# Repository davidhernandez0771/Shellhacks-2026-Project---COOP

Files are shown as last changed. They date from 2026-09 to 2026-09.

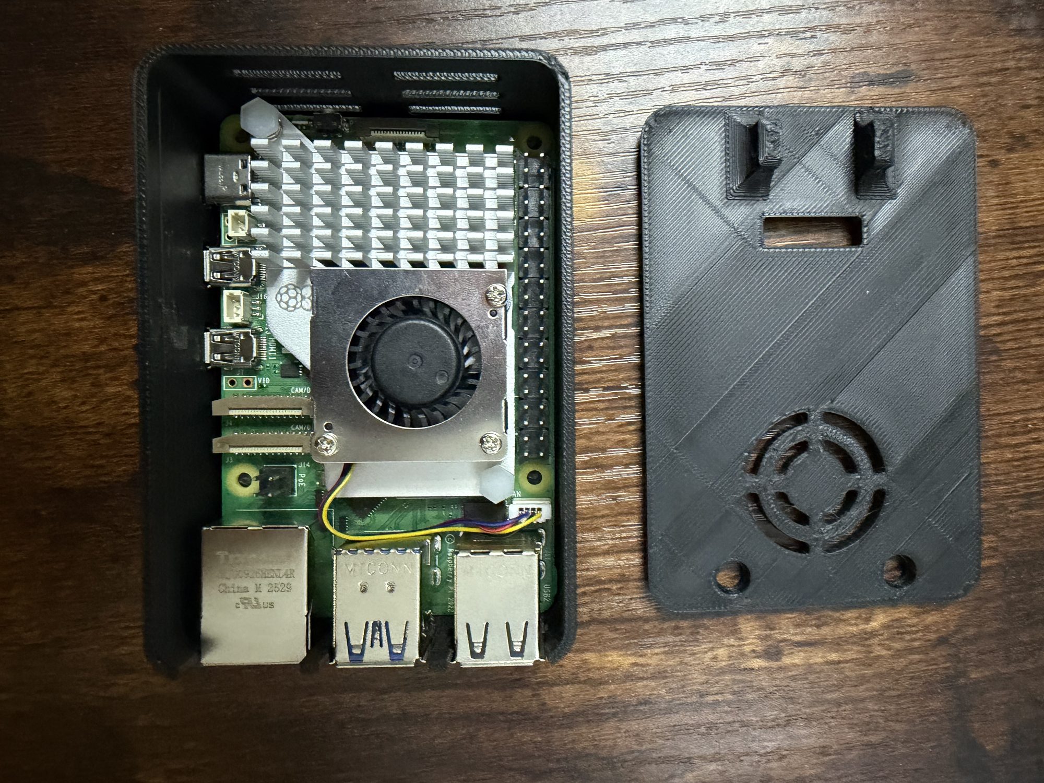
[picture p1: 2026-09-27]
site/media/gallery/05-printed-case-open.jpg

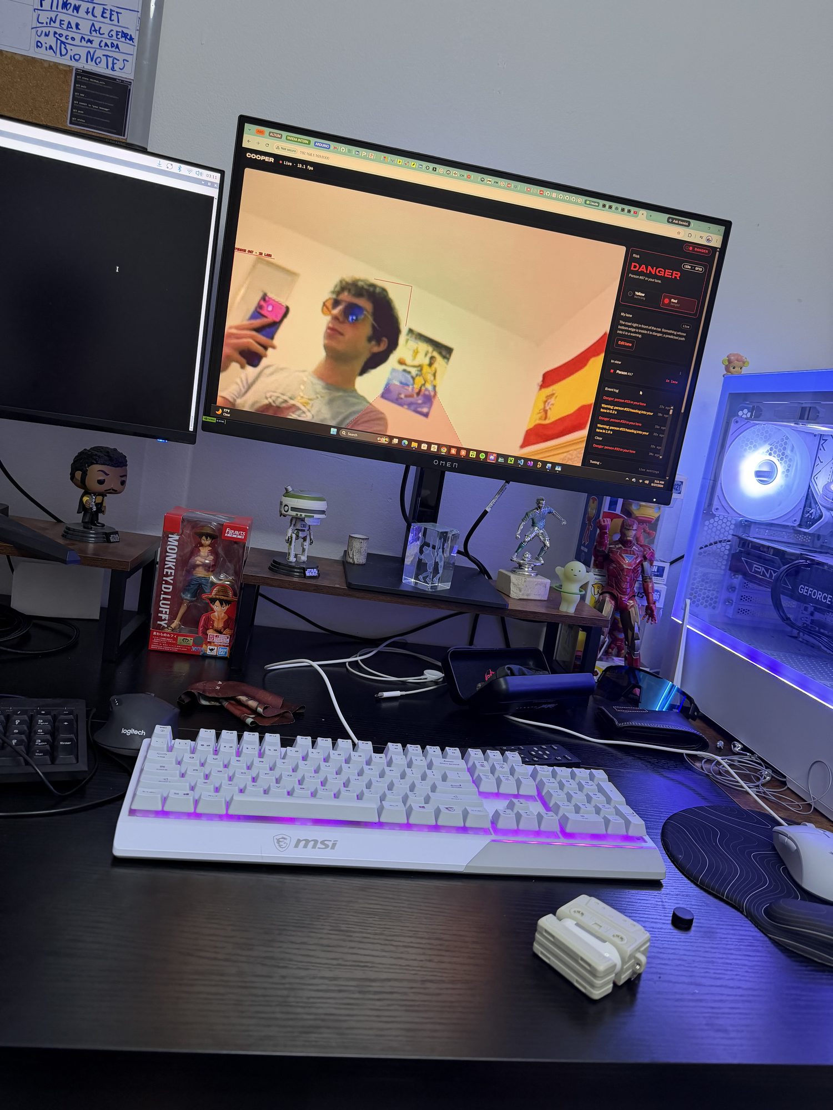
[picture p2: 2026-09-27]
site/media/gallery/12-test-danger-2.jpg

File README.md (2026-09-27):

# COOPER
✏️ _The story behind the name COOPER goes here (the team's to write)._

> COOPER is a Raspberry Pi 5 dashcam that spots people and cars, predicts where each one is heading, and lights a yellow or red LED before something cuts into your lane.

Built for **ShellHacks 2026**. The showcase site is live at [coop.davidhernandez.work](https://coop.davidhernandez.work) and the project page is on [Devpost](https://devpost.com/software/coop-l3s9ho); the Devpost submission text lives in [docs/DEVPOST.md](docs/DEVPOST.md).

```
Pi camera ─► YOLO11n + ByteTrack ─► Kalman filter per object ─► lane risk ─► yellow / red LED
                                                   │
                                                   └──► MJPEG stream + status API ─► web dashboard
```

## Team
| Who | Area |
|---|---|
| David Hernandez | Backend, vision, tracking, prediction |
| Diego Avila | CAD and hardware; assembled and wired the finished project |
| Diego Tabares | Presentation, pitch, and elements of website design |

## What it does
COOPER is a fixed, car-mounted dashcam: a Raspberry Pi 5 and an OV5647 camera behind the windshield, powered by the car. Nothing on it moves. Every frame, it:

1. **Detects** people, cars, motorcycles, buses and trucks with YOLO11n, and gives each one a stable ID with ByteTrack. All on the Pi 5's CPU, no accelerator.
2. **Predicts** where each object is going with its own Kalman filter, 1.5 s ahead.
3. **Judges the risk** against "my lane", a trapezoid of the road in front of the car:
   - **Red LED (danger):** something is in your lane right now.
   - **Yellow LED (warning):** something's predicted path enters your lane within 1.5 s (a car about to cut in, a pedestrian stepping out), or its time to contact is short (it's closing on you fast).
   - **Both off:** clear. Red overrides yellow.
4. **Streams** the video to a web dashboard that draws every predicted path, the lane (which you can drag to fit your car), the risk level and the LED state, and can beep in step with the LEDs.

## How it works (the math)
The car moves, so COOPER works on motion **relative to the camera**, in image pixels: that's what decides a collision, and it needs no map or speed sensor. [docs/MATH.md](docs/MATH.md) has the full derivation; the short version:

- **Where an object touches the road** is the bottom-centre of its box, (u, v). **How close it is** shows in the box height h, which is proportional to 1/distance.
- **A constant-velocity Kalman filter per object** tracks x = [u, v, h, u̇, v̇, ḣ] from measurements z = [u, v, h]:
  - F = [[I, Δt·I], [0, I]], H = [I 0].
  - Q is white-noise acceleration per axis, σ²·[[Δt⁴/4, Δt³/2], [Δt³/2, Δt²]], with σ = 400 px/s² for u, v and 150 px/s² for h.
  - R = diag(3², 3², 3²) px².
  - Predict: x̂⁻ = F·x̂, P⁻ = F·P·Fᵀ + Q. Update: K = P⁻Hᵀ(HP⁻Hᵀ + R)⁻¹, x̂ = x̂⁻ + K(z − Hx̂⁻), P = (I − KH)P⁻.
  - Because every matrix is block-diagonal per axis, it runs as three exact 2-state filters: a fraction of a millisecond for 10 objects.
- **Track lifetime:** a track unseen for 0.5 s is forgotten, and a track needs 3 measurements before its velocity is trusted for warnings.
- **Occlusion:** a box cut short by a nearer car would put the "ground point" on that car's roof. Measurements more than 4σ from the prediction are rejected and the filter coasts (v and h together, since they share the bottom edge), for at most 1 s.
- **Red:** at least 20 % of the object's bottom edge is inside the lane now.
- **Yellow:**
  - Path: the filter's path is sampled every 0.1 s out to 1.5 s, and a predicted bottom edge passes the same lane test.
  - Time to contact: τ = h / ḣ is below 2.0 s (it releases above 2.5 s) while the object is in the lane's corridor (the lane extended towards the vanishing point, widened by 25 % each side). That counts only when ḣ is more than 2 of its own standard deviations above zero, so detector jitter isn't read as closing, and only for boxes at least 24 px tall.
- **No flicker:** a level lights after 2 frames in a row and stays on 0.5 s after its condition ends.

## Hardware
- Raspberry Pi 5 (8 GB) with the active cooler
- OV5647 5 MP camera, 3.6 mm lens, 75° diagonal FOV (≈63°×49° at 4:3), no IR, on the Pi 5 camera port (needs the **15→22 pin Pi 5 cable**)
- A yellow and a red LED, each with a 330 Ω resistor, on Pi GPIO
- Power from the car: a USB-C PD car charger rated for the Pi 5 (5 V, 5 A / 27 W)
- microSD card (32 GB+) with Raspberry Pi OS Bookworm, 64-bit
- A windshield mount and enclosure for the Pi, camera and LEDs (designed in Fusion 360)

✏️ _Total parts cost: to fill in._

Wiring, pinout and the full BOM: [hardware/README.md](hardware/README.md).

### Wiring
| LED | GPIO (BCM) | Physical pin | Through | To |
|---|---|---|---|---|
| Yellow (warning) | GPIO17 ✏️ | 11 | 330 Ω → LED anode (long leg) | cathode → GND (pin 9) |
| Red (danger) | GPIO27 ✏️ | 13 | 330 Ω → LED anode (long leg) | cathode → GND (pin 14) |

✏️ **These pins are placeholders, still to confirm** against the real wiring. Set them as `yellow_pin` / `red_pin` under `[leds]` in `cooper.toml` (BCM numbers, not physical pin numbers). At 3.3 V with a ~2.0 V LED drop, 330 Ω gives about 4 mA per LED. gpiozero drives them through the lgpio backend (the Pi 5's GPIO is on the RP1 chip).

## Run it

### On a laptop (no Pi, no LEDs)
```bash
python -m venv .venv
.venv\Scripts\activate          # Windows  (source .venv/bin/activate on Mac/Linux)
pip install -r requirements.txt
python -m cooper.main --source webcam
```
Open `http://localhost:8000`. Off a Pi the LEDs are mocked automatically (`--no-leds` forces it anywhere): the dashboard shows what they would do, and gpiozero isn't needed. The first run downloads `yolo11n.pt`.

**No camera pointed at a road?** Run the rehearsal: the real app watching a synthetic road through a fixed dashcam (a car cutting in, a pedestrian crossing, the lead car braking, a car in the next lane that must never light anything).
```bash
python -m tools.rehearsal             # then open http://localhost:8000
python -m tools.rehearsal --timeline  # no dashboard: print one 20 s loop's risk and LED changes
```

### On the Pi
Flash Raspberry Pi OS Bookworm (64-bit) and, in Raspberry Pi Imager's settings, set the hostname, a user and **enable SSH**. Then, on the Pi:
```bash
git clone https://github.com/davidhernandez0771/Shellhacks-2026-Project---COOPER cooper
cd cooper
bash scripts/setup_pi.sh          # apt: picamera2, gpiozero, lgpio; a .venv that can see them; pip requirements
source .venv/bin/activate
python -m cooper.main --source picamera   # add --no-leds to keep the LEDs off
```
`setup_pi.sh` creates the venv with `--system-site-packages`, because Picamera2 and gpiozero come from apt, not pip. Test the camera alone with `rpicam-hello -t 5000`.

**Getting onto the Pi:**
- **SSH** from a laptop on the same network: `ssh <user>@<pi-hostname>.local`, or `ssh <user>@<Pi IP>`. `hostname -I` on the Pi prints its IP.
- **Raspberry Pi Connect** when you're not on the same network, or want the Pi's screen in a browser: `sudo apt install rpi-connect` (`rpi-connect-lite` on OS Lite), `rpi-connect on`, `rpi-connect signin`, then open [connect.raspberrypi.com](https://connect.raspberrypi.com) for a remote shell.

**Open the dashboard** from a laptop or phone on the same network: `http://<Pi IP>:8000` (or `http://<pi-hostname>.local:8000`).

- **Run on boot:** `sudo bash scripts/install_service.sh` installs `cooper.service` (systemd), which starts COOPER when the car powers the Pi and restarts it if it crashes. Check on it with `systemctl status cooper` and `journalctl -u cooper -f`; restart with `sudo systemctl restart cooper`.
- **Remote access:** to reach the dashboard over HTTPS from anywhere, with an email login in front (Cloudflare Tunnel + Access), see [scripts/setup_tunnel.md](scripts/setup_tunnel.md).
- **Calibrate the lane** once the camera is mounted: in the dashboard, **Edit lane**, drag the corners onto your lane out to about 15 m, then **Apply and save**. Step by step: [docs/HARDWARE_TEST.md](docs/HARDWARE_TEST.md).

## The dashboard
Served by the Pi at port 8000 (`web/`, plain HTML, CSS and JS; the API is in [docs/API.md](docs/API.md)).

- **Live feed** with, on one canvas: the lane (tinted yellow or red with the risk), every object's corner brackets, its predicted path with a tick every 0.5 s, and the bottom edge the lane test uses.
- **Risk panel:** the level and the reason ("car #201 heading into your lane in 0.8 s"), the two LEDs and whether they're real (GPIO) or mocked, every object by risk, and the event log.
- **Lane editor:** drag the four corners; **Apply** updates the risk rules on the next frame, **Apply and save** also writes it to `cooper.toml`.
- **Tuning:** confidence, horizon, time-to-contact thresholds and hold time, live.
- **Beep:** a sound that follows the same risk level as the LEDs, like a parking sensor: yellow is one short beep a second, red is rapid high beeps. It's off until you turn it on (the speaker button or the **S** key), because browsers block audio until the page is interacted with; the choice is remembered.
- **Diagnostics:** CPU temperature, throttling, vision and camera fps, inference time, camera-to-LED latency.
- **Keys:** **L** edit lane, **Esc** cancel, **F** fullscreen, **S** sound.

With no backend it plays a mock of the same road (`?demo=warning`, `?demo=danger`, …, listed in `web/mock.js`).

## Settings
Every tunable lives in `cooper/config.py`. To change one without editing code, copy `cooper.example.toml` to `cooper.toml` in the repo root and edit it (it's gitignored, so the Pi and each laptop keep their own). Unknown keys and wrong types stop COOPER at startup with the key named. `--config other.toml` picks another file.

Live from the dashboard (`GET/POST /api/settings`, saved back to `cooper.toml` with `"save": true`, comments kept): `conf`, `horizon_s`, `ttc_warn_s`, `ttc_clear_s`, `hold_s`. The lane is live too (`POST /api/lane`). See [docs/API.md](docs/API.md).

Command-line flags for `python -m cooper.main`: `--source auto|picamera|webcam`, `--port`, `--no-leds`, `--annotate` (burn boxes into `/video`), `--config`.

## Bench tools
Run from the repo root. Each also works as `python tools/<name>.py`.

| Tool | What it's for |
|---|---|
| `python -m tools.rehearsal` | The whole app on a synthetic road, no hardware. `--timeline` prints one loop's risk and LED changes instead. |
| `python -m tools.camera_check [--source picamera]` | Delivered resolution and FPS, plus a saved still for the colour and orientation check. |
| `python -m tools.bench_fps [--export]` | YOLO speed, PyTorch vs NCNN at imgsz 256/320/416, timing the same `track()` call COOPER makes; `--export` builds the NCNN models. Prints a Markdown table. |

The first-hardware checklist in [docs/HARDWARE_TEST.md](docs/HARDWARE_TEST.md) uses them in order: rehearsal → camera check → FPS bench → LEDs → lane calibration → risk test.

## Testing
```bash
pip install -r requirements-dev.txt
python -m pytest -q
```
Covers the Kalman filter (against the full 6×6 matrix form, occlusion gating, time to contact), every risk rule and the hysteresis, the LEDs (gpio vs mock, only writing on a change), the settings file and live settings, the lane API, the Flask API, diagnostics, the capture thread, the bench tools, and the rehearsal's whole 20 s loop (each scripted event warns before it's danger, the car in the next lane never lights an LED, no LED flickers). Runs anywhere `requirements.txt` does: no Pi, camera or GPIO needed. GitHub Actions runs it on every push and pull request.

## Performance tips (Pi 5)
- Export the model to NCNN for a big CPU speed-up: `python -m tools.bench_fps --export` (then `python -m tools.bench_fps` to compare), and set `model = "yolo11n_imgsz320_ncnn_model"` and `imgsz = 320` under `[detector]` in `cooper.toml`. An NCNN model must run at the size it was exported at.
- `/api/status` → `diag` shows `fps`, `capture_fps`, `infer_ms`, `latency_ms`, the CPU temperature and throttle flags.
- Keep `imgsz` at 320 and the capture resolution at 640×480 unless you have headroom. Prediction and risk cost well under a millisecond per frame.

## Troubleshooting
- **Camera not detected:** check the ribbon cable orientation and that it's the 22-pin Pi 5 cable. Test with `rpicam-hello`.
- **`numpy.dtype size changed` when importing picamera2:** pip replaced the system numpy. Run `pip uninstall numpy` inside the venv so it uses the apt version again.
- **LEDs say "mock" on the Pi:** the log line `LEDs: mock (...)` gives the reason. Usually gpiozero or lgpio isn't installed (re-run `scripts/setup_pi.sh`), or another process holds the pins.
- **Under-voltage (`throttled` not 0):** the car charger can't deliver 5 A. Use a 27 W USB-C PD charger.
- **No sound from the dashboard:** click the page once (or press **S**); the button reads "Click to enable" while the browser is still blocking audio.

## The website
[coop.davidhernandez.work](https://coop.davidhernandez.work) is the public showcase: a one-page, scroll-driven story (See, Detect, Predict, Warn, Build, Gallery, Team) in one persistent three.js scene, with COOPER's real CAD model pulled apart in the Build chapter. It lives in `site/`, has no build step and deploys to Cloudflare Pages; see [site/README.md](site/README.md) and [site/PERFORMANCE.md](site/PERFORMANCE.md).

## Repo layout
```
cooper/
  main.py       main loop: capture → detect/track → predict → risk → LEDs → stream
  config.py     every tunable value (camera, model, prediction, risk, lane, LED pins)
  camera.py     Picamera2 on the Pi, webcam fallback for laptop dev
  detector.py   YOLO11n + ByteTrack (person, car, motorcycle, bus, truck)
  predictor.py  constant-velocity Kalman filter per tracked object, in image space
  risk.py       lane geometry, path and time-to-contact rules, hysteresis → clear/warning/danger
  leds.py       the two LEDs: gpiozero on the Pi, a mock everywhere else
  control.py    the event log behind /api/events
  settings.py   cooper.toml loading/validation/saving, live tuning (/api/settings) and the lane (/api/lane)
  diag.py       CPU temperature, throttling, LED mode, fps for /api/status.diag
  stream.py     Flask MJPEG stream + the JSON API (docs/API.md)
cooper.example.toml  every setting at its default; copy to cooper.toml (gitignored) to override
web/            the dashboard (served by the Pi)
tools/          rehearsal, camera_check, bench_fps; cad_to_glb.py (Fusion 360 → the site's .glb); site_perf/ (site measurements)
scripts/        setup_pi.sh, install_service.sh + cooper.service, Cloudflare Tunnel (setup_tunnel.md, install_tunnel.sh)
hardware/       wiring, pinout, BOM, power and mounting notes
site/           the public showcase site (static; see site/README.md)
tests/          pytest suite
docs/           MATH.md (filter and risk rules), API.md, HARDWARE_TEST.md, DEVPOST.md, DESIGN_BRIEF.md
```

## License
MIT

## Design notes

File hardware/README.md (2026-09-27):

# Hardware

Owner: design & hardware teammate. Keep this file up to date when the wiring changes. Pin numbers live in `cooper/config.py` (`LedConfig`) and can be overridden under `[leds]` in `cooper.toml`.

## Architecture
```
car 12 V socket ──► USB-C PD car charger (5 V, 5 A) ──USB-C──► Raspberry Pi 5 ──22-pin ribbon──► OV5647 camera
                                                                   │
                                                                   ├─ GPIO17 ──330 Ω──► yellow LED ──► GND
                                                                   └─ GPIO27 ──330 Ω──► red LED ────► GND
```
COOPER is a fixed dashcam: nothing moves. The Pi runs everything (vision, prediction, risk) and drives the two LEDs directly from its GPIO.

## Bill of materials
| Part | Qty | Notes |
|---|---|---|
| Raspberry Pi 5, 8 GB | 1 | + active cooler (a parked car gets hot) |
| OV5647 5 MP camera, 3.6 mm, 75° | 1 | Non-IR |
| Pi 5 camera cable, 15→22 pin | 1 | ✅ have it |
| USB-C PD car charger, 27 W (5 V / 5 A) | 1 | + a short USB-C cable. A weaker charger causes under-voltage throttling |
| LED, yellow, 5 mm | 1 | Warning |
| LED, red, 5 mm | 1 | Danger |
| Resistor, 330 Ω | 2 | One per LED |
| Female-to-male jumper wires | 4 | Or solder to the header |
| microSD card, 32 GB+ | 1 | Raspberry Pi OS Bookworm, 64-bit |
| Windshield mount / enclosure | 1 | Designed by the hardware lead |

## Wiring: LEDs
**The pin numbers are placeholders (TODO): confirm them when wiring, then set them in `cooper.toml`.**

| LED | GPIO (BCM) | Physical pin | Series resistor | Cathode (short leg) to |
|---|---|---|---|---|
| Yellow (warning) | **GPIO17** (TODO) | 11 | 330 Ω, between the pin and the anode (long leg) | GND, physical pin 9 |
| Red (danger) | **GPIO27** (TODO) | 13 | 330 Ω, between the pin and the anode (long leg) | GND, physical pin 14 |

```toml
[leds]
yellow_pin = 17   # BCM numbering, not physical pin numbers
red_pin = 27
```

- **Why 330 Ω:** Pi GPIO is 3.3 V and a yellow or red LED drops about 2.0 V, so (3.3 − 2.0) / 330 ≈ 4 mA: clearly visible, and well under the Pi's per-pin limit (16 mA). Brighter LEDs for daylight can go down to 150 Ω (≈ 9 mA). Never connect an LED without a resistor.
- **BCM vs physical numbers:** gpiozero uses BCM numbers (GPIO17), not header positions (pin 11). `pinout` on the Pi prints the map.
- Only one LED is lit at a time: yellow = warning, red = danger, both off = clear.
- The software drives them through gpiozero with the lgpio backend (the Pi 5's GPIO is on the RP1 chip, which the old RPi.GPIO library doesn't support); `scripts/setup_pi.sh` installs both from apt.

## Power
- **Use a USB-C PD car charger rated for 5 V / 5 A (27 W).** A Pi 5 running YOLO draws a lot of current; a weak charger causes under-voltage throttling or reboots. Check with `vcgencmd get_throttled` (`0x0` = OK) or the dashboard's Power reading.
- On a charger that can't negotiate 5 A the Pi limits its USB ports to 600 mA and shows a boot warning. COOPER uses no USB devices, so that's harmless.
- **The car cuts power when the ignition turns off,** which is an unclean shutdown for the SD card. For the hackathon that's acceptable; a clean shutdown on ignition-off is on the "what's next" list.
- Cabin heat: a car in the sun passes 60 °C inside. Keep the active cooler, and watch `cpu_temp_c` (the Pi 5 throttles at 80–85 °C).

## Mounting and the lane
- Mount the camera **centred** behind the windshield (next to the rear-view mirror), **level**, looking straight down the road, and rigid: a mount that shakes makes every box jitter.
- The software's "my lane" is a region of the image, so it's only right for one mount position. After mounting, calibrate it from the dashboard (**Edit lane** → drag the corners onto your lane out to ~15 m → **Apply and save**); it's stored under `[risk] lane` in `cooper.toml`. `docs/HARDWARE_TEST.md` has the steps.
- Keep the LEDs where the driver sees them without looking away from the road (top of the dashboard, near the windshield base).

## Files
Put CAD, STL and wiring diagrams in this folder.

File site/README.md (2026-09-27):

# COOPER showcase site

A cinematic one-page site for COOPER, a fixed, car-mounted Raspberry Pi 5 dashcam that predicts every road user's path and lights a yellow or red LED before something enters your lane. The COOPER wordmark hero and seven chapters (See, Detect, Predict, Warn, Build, Gallery, Team) played out in one persistent WebGL scene that scroll drives. Design rationale: `docs/DESIGN_DIRECTIONS.md`.

**No build step.** Plain HTML, CSS and native ES modules. three.js and anime.js are vendored in `vendor/` and mapped with an import map in `index.html`, and the fonts are self-hosted in `fonts/`, so the page makes no third-party requests and deploys as-is.

## Preview locally
```bash
python -m http.server 8765 --directory site
```
Open http://localhost:8765. Useful switches:

| URL | What you get |
|---|---|
| `/?still` | the reduced-motion version (same as the OS "reduce motion" setting) |
| `/?nogl` | the no-WebGL fallback (a 2D-canvas render of the same scene) |
| `/?debug` | exposes `window.__coop` (the stage and anime.js) in the console |
| `/#build` | deep link to a chapter (skips the intro animation) |

## Edit the copy
All text is in `index.html`, one `<section class="chapter">` per chapter. Paragraphs with `class="reveal-words"` get the word-by-word reveal automatically; keep them plain text (no links inside). The intro tagline under the wordmark is `TAGLINE` in `js/intro.js`. The chapter names in the bottom HUD come from `CHAPTERS` in `js/stage/director.js`, and the on-canvas tags (`TRACKED`, `PATH · t + …`) from `js/stage/overlay.js`.

The Warn chapter keeps the section id `move` (the nav, the scroll code and the scene key off chapter numbers and ids), so don't rename the id.

## Fill the placeholders
Search for `✏️ PLACEHOLDER` (HTML comments) and `data-placeholder` (elements):

| Placeholder | Where | What to put |
|---|---|---|
| `cost-comparison` | Problem block | COOPER's total parts cost vs. a newer car vs. an aftermarket system |
| gallery `<li>` items | Gallery chapter | photos and videos, see below |

## Add photos and videos to the gallery
The 3D carousel is built from the list in `index.html` (`<ul id="gallery-list">`). Without WebGL the same list shows as a grid, so it's also the accessible version. Put files in `site/media/` and replace a placeholder `<li>`:

```html
<li data-src="media/build.jpg" data-alt="Inside COOPER: the Pi 5, camera and LEDs">Inside the build</li>
<li data-src="media/cut-in.mp4" data-kind="video" data-alt="COOPER lighting yellow as a car cuts in">A cut-in, caught early</li>
```
- The text inside the `<li>` is the caption; `data-alt` is the description for screen readers.
- Any number of items works (the ring spaces them evenly). 6–10 looks best.
- Images: JPG/WebP, 3:2, about 1600×1067, under 400 KB each. They're cover-cropped to 3:2.
- Videos: MP4 (H.264), muted, 3:2 or 16:9, under 4 MB, a few seconds long. They loop silently and only play while facing the viewer.
- A video card can open a longer cut with sound in the viewer: `data-src` is the short silent loop, `data-full` the full video (fetched only when the viewer opens it), `data-poster` the still shown until either plays. Cloudflare Pages rejects files over 25 MB. Card 1 (`media/gallery/demo*.{mp4,jpg}`) is the example.
- Media only downloads when the visitor scrolls near the gallery. The no-WebGL grid picks up the same `data-src` files automatically.

## The 3D model (.glb)
The Warn, Build and Team chapters show COOPER itself: `models/cooper-camera.glb`, made from the team's Fusion 360 assembly by `tools/cad_to_glb.py` (Blender, headless). It has one node per part: `Pi_Case`, `Pi_Case_Lid`, `RASPBERRY_PI_5_1`, `Camera_Mount`, `Camera_Module`, `LED5mm_Yellow` and `LED5mm_Red` (an instance of the yellow one's mesh). It's in metres, with the lens facing −Z, +Y up and the origin at the centre of the case's bottom face. It has about 24k triangles and weighs 281 KB, with positions only (no normals, textures or Draco).

To rebuild it after a CAD change, export the assembly from Fusion as **FBX** (it keeps the component names; the OBJ export loses them) and run from the repo root:

```
blender -b -P tools/cad_to_glb.py -- --src "path/to/Assembled Pi Case.fbx"
blender -b -P tools/cad_to_glb.py -- --src "…fbx" --preview preview.png   # check the part grouping first
```

The CAD files stay out of the repo. The script prints each part's triangle count; the budgets are at the top of it. On the site:
- `js/stage/solids.js` loads the model lazily, once the scroll nears the Warn chapter. Until then, or if it fails, a stand-in built from boxes (same parts, same places) is shown. `CAMERA_MODEL_URL = null` forces the stand-in.
- The model is restyled to match the scene (ink fill, paper edges; the scene has no lights). The exploded view is the `EXPLODE` table there: the lid lifts off first and takes the LEDs with it, the Pi rises out of the tray, then the mount and the camera module slide forward.
- The Build labels (`#parts` in `index.html`) hang on the parts through `data-part` → `PART_NODES`.
- Nothing on COOPER moves in use: no turning base, no bearing readout. The Warn chapter shows its two LEDs, lit by the scene's warning level (`riskLevel` in `js/stage/director.js`, by the real rules: red when something is in "my lane" now, yellow when a predicted path enters it within 1.5 s, red overrides yellow, and a level holds 0.5 s). The same level tints the lane in the scene and lights the model's LEDs.

## How it's put together
| File | Role |
|---|---|
| `main.js` | boot, straight into the hero (no loader or Enter gate): fonts → anime.js → three.js + scene → intro; enhances the hero CTAs, the wordmark and the stack grid |
| `js/intro.js` | the hero timeline: brackets lock onto the wordmark, the readout decodes into the tagline |
| `js/fx/vector-wordmark.js` | the hero title: "COOPER" drawn as one WebGL quad, its glyphs revealed through a soft-to-sharp mask that follows the pointer (auto-sweeps with no pointer) |
| `js/fx/tactile-button.js` + `.css` | the "See how it works" CTA: a keycap face that presses down onto its base and springs back |
| `js/fx/scan-grid-button.js` + `.css` | the "View on GitHub" CTA: a looping scanline sweep and a staggered glitch on the label while hovered or focused |
| `js/fx/interactive-grid.js` + `.css` | the tech-stack tile sheet at the end of the Build chapter (`#stack-grid`, logos in `media/logos/`): the hovered tile and its four neighbours lift and glow; the layout is pure CSS and works without JS |
| `js/chapters.js` | anime.js `onScroll` per chapter, word reveals, nav, chapter scrubber, frame counter, the Warn LEDs |
| `js/cursor.js` | the desktop cursor (ring → lock brackets on links, "Drag" in the gallery) |
| `js/stage/world.js` | the street as data: people, cars, sampled point clouds (no three.js) |
| `js/stage/director.js` | chapter keyframes: camera and what's visible; the scene's warning level; the HUD chapter names |
| `js/stage/points.js` | the point cloud shader (one draw call; motion computed on the GPU) |
| `js/stage/overlay.js` | detection brackets, leader-line labels, velocity vector, predicted path point, "my lane", the Build labels |
| `js/stage/solids.js` | COOPER's 3D model (lazy .glb, box stand-in), its exploded view and lit LEDs, the view frustum |
| `js/stage/carousel.js` | the gallery ring |
| `js/lightbox.js` + `lightbox.css` | the full-screen gallery viewer: opens on the carousel's `cooper:gallery-open` event (detail `{ index }`) or a click/Enter on a `#gallery-list` item; reads `data-full` (else `data-src`), shows the card image until the full one has loaded, pinch/double-tap/wheel zoom with pan, swipe to change item or close, and fires `cooper:gallery-close` with the last index. Built on first open; nothing runs while closed |
| `js/stage/fallback2d.js` | the no-WebGL renderer |
| `tokens.css` | every color, font and timing |

Numbers in the copy are real where they describe COOPER (FOV, frame size, the 1.5 s horizon and 0.1 s path steps, the 2 s time-to-contact warning, two frames to light and 0.5 s hold; see `cooper/config.py`). The scene is an illustration, not live data: the detection confidences, figures, frame counter, "my lane" (a 1.6 m × 5.5 m strip ahead of the unit) and the `PATH · t + 1.6 s` tag (drawn further ahead than the real horizon so it's visible) are all made up.

**Updating the vendored libraries:** `vendor/three.module.min.js` is `three/build/three.module.js` bundled and minified with esbuild (`esbuild three.module.js --bundle --minify --format=esm`); `vendor/GLTFLoader.js` is `three/examples/jsm/loaders/GLTFLoader.js` bundled the same way with `--external:three`; `vendor/anime.esm.min.js` is copied from the `animejs` package's `dist/bundles/`.

## Deploy (Cloudflare Pages)
The Pages project is **`coop-224`**: framework **None**, build command **empty**, build output directory **`site`**. Every pushed branch gets a preview at `https://<branch-alias>.coop-224.pages.dev`, where the alias is the branch name lowercased with `/` turned into `-` (so `cloud/showcase` → `cloud-showcase.coop-224.pages.dev`). Pushes to `main` update production.

To connect it the first time: Cloudflare dashboard → **Workers & Pages → Create → Pages → Connect to Git** → this repo, with the settings above.

**Hostname:** the showcase is served at `coop.davidhernandez.work` (the public link for judges); the live dashboard is at `coop-live.davidhernandez.work` behind Cloudflare Access (see `scripts/setup_tunnel.md`). Don't put an Access policy on the showcase hostname.

### Alternative: GitHub Pages
GitHub Pages can only publish from the repo root or `/docs`, so deploy `site/` with an Actions workflow (`actions/upload-pages-artifact` with `path: site`, then `actions/deploy-pages`), and set **Settings → Pages → Source: GitHub Actions**.

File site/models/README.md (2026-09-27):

# Models

`cooper-camera.glb` is COOPER itself, the model shown in the Warn, Build and Team chapters. It's made from the team's Fusion 360 assembly by `tools/cad_to_glb.py`: one node per part, in metres, lens facing −Z, +Y up, and about 24k triangles in 281 KB. `site/README.md` ("The 3D model") explains how to rebuild it and how the site uses it.

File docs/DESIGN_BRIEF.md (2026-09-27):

# COOP design brief

The single source of truth for the dashboard's look. It shares its identity with the showcase site (`site/`, rationale in `docs/DESIGN_DIRECTIONS.md`): **black, white and one orange**. The showcase is cinematic; the dashboard is a tool: calm, legible, fast.

**Vibe in one line:** an instrument panel for a camera that aims itself. The live feed and the pan gauge are the heroes; everything else is quiet.

## Tokens
All colors, type, spacing and motion live in **`web/tokens.css`**. No hard-coded colors anywhere else.

| Token | Value | Use |
|---|---|---|
| `--ink` | `#060606` | page background |
| `--ink-2` | `#0E0E0D` | panels |
| `--paper` | `#EEEDEA` | primary text, the active mode, the auto-picked target |
| `--paper-2` | `#9C9B98` | secondary text (7:1 on ink) |
| `--paper-3` | `#62615F` | ticks, disabled, never body text |
| `--lock` | `#FF5A1F` | **the one orange**: a locked target, the predicted aim, the primary action, and anything that needs you (e-stop, Arduino away, warnings) |
| `--hazard` | orange/ink stripes | the e-stop control and alert banners only |

There is no red and no green. Severity is shown with orange plus shape (hazard stripes, filled vs. outlined), never color alone.

**Type:** Archivo (display at 112–125% width for the brand and big numbers; normal width for UI text) and Martian Mono for telemetry, labels and numbers (tabular). Fonts are served from `web/fonts/`, so the Pi works offline. Sentence-case headings, no all-caps labels except detection tags (which mirror the model's class names).

**Shape:** 10px panels with a 1px line and no shadows or blur; pills for the mode switch and chips; a rectangular e-stop with a hazard edge. **Motion:** 140–240 ms ease-out; detection labels decode in (scramble) when a target is first seen; respect `prefers-reduced-motion`.

## Layout (desktop; one column on phones: feed → pan → target → lists → diagnostics)
```
┌ COOP  ● Live · 14.2 fps            [ Auto | Manual | Stop ]  [Zero here] [▨E-stop▨] ┐
├ banner (only when something needs attention: signed out, offline, e-stop, Arduino)   ┤
├───────────────────────────────────────────────┬──────────────────────────────────────┤
│                                               │ Pan: gauge (hero), ±170° limits,     │
│  LIVE FEED (4:3)                              │  needle = pan, orange mark = aim;    │
│  corner brackets + leader-line mono labels    │  Manual: ◀  Home  ▶, click the dial  │
│  (click a box = lock), velocity arrow,        │ Target: name, confidence, velocity,  │
│  predicted aim + trail                        │  lead, Lock / Clear                  │
│                                               │ In view (detections)                 │
├ diagnostics: CPU · Power · Vision · Camera ·  │ Event log                            │
│ Inference · Latency · Arduino · Uptime        │ Tuning (live settings, collapsed)    │
└───────────────────────────────────────────────┴──────────────────────────────────────┘
```

## Rules
- **The feed is sacred.** Nothing covers the center of the video except the target brackets and the prediction overlay.
- State is always visible: mode, connection (live / stale / offline / signed out), motors (live / mock / drivers off / Arduino reconnecting), e-stop.
- A locked target is orange; the auto-picked target is paper white; other detections are muted.
- Every failure has a designed state that says what happened and what to do: no camera, Arduino reconnecting, Access session expired, offline, stale, e-stop, no target. Preview them with mock data: `?demo=nocam|reconnecting|expired|offline|stale|estop|notarget|hot`.
- E-stop fires on one click (or `X`) and never waits for anything; Zero needs a second click within 3 s.
- It must work on a phone. Judges will open it on theirs.
- No build step: plain HTML, CSS and JS served by Flask, so the Pi serves it as is.

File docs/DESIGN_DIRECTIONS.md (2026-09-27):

> **Outdated: from the motorized-gimbal era.** COOPER is now a fixed dashcam; see README.md and docs/MATH.md.

# Showcase design directions (2026-09-26, unattended brainstorm)

Written by the overnight cloud session following the `brainstorming` skill in **unattended mode**: the questions were answered from `docs/CLOUD_PLAN.md`, three directions were written down, and one was picked. David can overrule the pick in the morning; everything below the decision is implementation detail.

## What the brief fixes (not up for debate)
- Black, white and orange only. Near-black stage, off-white text, one orange.
- A display face with character, a clean sans for body text, a mono for labels and telemetry.
- One persistent WebGL scene behind the page, driven by scroll and pointer; loader + enter gesture; the "COOP" scrambleText intro; seven chapters (SEE, DETECT, PREDICT, MOVE, BUILD, GALLERY, TEAM).
- 60 fps, light initial load, reduced-motion and no-WebGL versions, phones.

Those constraints already put the site into two of the "generated-design" clusters the `frontend-design` skill warns about (a near-black stage with one bright accent, and a mono face for small labels). Because the brief asks for them, they stay. So the identity has to come from somewhere else: **the subject matter itself**. COOP is a machine that turns a pixel into an angle and then turns itself by that angle. The thing it thinks in is *bearing*.

## Answers to the brainstorming questions (self-answered)
- **Who is it for?** ShellHacks judges, first on a laptop at the expo table, then on their phones later. Secondary: recruiters and the team's portfolio.
- **What must a visitor remember?** That this camera *predicts* and then physically *turns*. The math is real (world angles, Kalman lead aim), and the hardware is real.
- **What does success look like?** A judge scrolls the whole thing in ~60 seconds, understands the pipeline without reading paragraphs, and says "that looks like a product launch".
- **Where's the risk?** Generic particle-sphere WebGL; too much text; performance on a judge's mid-range laptop.

## Direction A: "Bearing" (instrument) ← picked
The page *is* the camera's point of view, and scrolling *is* panning. A heading tape runs along the bottom edge like an avionics bearing scale; as you scroll, the virtual COOP turns, the tape slides, and a readout shows the real pan angle in degrees. Every chapter sits "at" a bearing. Overlays use the language of the actual dashboard: corner-bracket reticles, thin leader lines, tiny labels (`PERSON #3 · CONF 0.87`). Orange is used for exactly one meaning: **lock** (the tracked target, the aim point, the active chapter, the primary action). Everything else is white at different strengths.
- **Type:** Archivo at its widest (wdth 125, heavy) for display: extended grotesks are the language of camera and optics brands, and its wide O's read as lenses in "COOP". Archivo at normal width for body text (same family, clearly distinct by width). Martian Mono, a squared mono, for telemetry. STIX Two for the equation figure only (math is set in a serif italic by convention).
- **Why it's specific:** the signature element (a bearing tape that moves with scroll) is literally how the product works (world-angle space); it couldn't be moved onto another project's site without becoming meaningless.
- **Risk:** instrument chrome can clutter. Mitigation: one tape, one reticle cursor, and nothing else permanent on screen except the pill nav.

## Direction B: "Night shift" (surveillance dossier)
A CCTV archive: timestamped frames, film-strip gallery, redaction bars, case-file typography, scanlines and noise.
- **For:** strong mood, easy to understand ("security camera").
- **Against:** the CCTV look is a cliché, and it frames the project as surveillance of people, which is the least flattering reading of a person-tracking camera. Scanlines and noise also fight the "soft blooms on black" feel the brief asks for.

## Direction C: "Signal from noise" (generative)
Pure generative art: a huge particle field that organises itself into meaning chapter by chapter, with giant type and almost no UI.
- **For:** the closest to Active Theory's surface, and very cinematic.
- **Against:** it's the default WebGL showcase (particles morphing between shapes); without an idea tying the motion to the product it reads as a template. It also hides the engineering, which is the project's real strength.

## Decision
**A, "Bearing"**, borrowing C's particle street scene for chapters 01–03 (the brief asks for point clouds), because the particles then have a job: they are what the camera sees, and the overlays are what it understands.

## Token plan
| Token | Value | Role |
|---|---|---|
| `--ink` | `#060606` | stage (true near-black, no warm or blue tint) |
| `--paper` | `#EEEDEA` | primary text, strong lines |
| `--paper-2` | paper at 64% | secondary text (≥ 7:1 on ink) |
| `--paper-3` | paper at 40% | tertiary / tick marks, never body text |
| `--lock` | `#FF5A1F` | the one orange: lock, aim, active, primary action |
| `--lock-dim` | lock at 18% | orange washes (focus rings, fills) |

Type scale (1.333, perfect fourth, from 16 px body): 12 / 16 / 21 / 28 / 38 / 50 / 67, with the display set fluid up to ~22vw for "COOP".

Layout: left-aligned copy in a narrow column (≤ 34 ch for leads, ≤ 62 ch for body) against the full-bleed stage; the stage's subject sits right of center on desktop and behind the copy on phones (with a scrim). Chapter numbers are real sequence (the pipeline runs in that order), so numbering is justified here.

```
┌───────────── ( COOP  see detect predict move build gallery team  GitHub ) ─────────────┐
│                                                                                        │
│  02                                                   ┌─┐          ┌──┐                │
│  Detect                                               │ │ PERSON #3│  │                │
│  Boxes snap onto what matters…                        └─┘ CONF .87 └──┘                │
│                                                                                        │
│ 03 / 07   ·|·····|·····|··· 330 ···|·····|····· N ·····|·····   PAN +012.4°            │
└────────────────────────────────────────────────────────────────────────────────────────┘
```

## Principles
1. Orange means lock. If something is orange, it's the thing COOP (or you) has chosen.
2. The overlays are the product's own UI language, so the showcase and the dashboard feel like one system.
3. One orchestrated moment per chapter, scrubbed by scroll, not a dozen fade-ins.
4. Real content only: no invented metrics, quotes or people. Placeholders are marked `✏️ PLACEHOLDER`.

## Self-review against the brief
- *Would I have produced this for any "AI camera" site?* The particle street and reticle boxes, maybe; the bearing tape tied to scroll, the orange-means-lock rule and the extended-grotesk "lens" wordmark, no. Kept.
- *First draft used Space Grotesk + JetBrains Mono.* Both are the reflex choices for "tech" pages; swapped for Archivo (extended) + Martian Mono.
- *First draft had a glassmorphism card per chapter.* That's the SaaS-card kit; removed. Copy sits directly on the stage with a gradient scrim for legibility.

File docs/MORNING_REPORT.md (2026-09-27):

> **Outdated: from the motorized-gimbal era.** COOPER is now a fixed dashcam; see README.md and docs/MATH.md.

# Morning report (2026-09-26)

Two overnight cloud sessions, merged. Part A is the backend (`cloud/hardware-ready`); Parts B and C are the showcase and dashboard (`cloud/showcase`).

---

## Morning report: `cloud/hardware-ready` (Part A)

Overnight cloud session, 2026-09-26. Branch `cloud/hardware-ready`, cut from `dev` at `101856e`, pushed. **Nothing was pushed to `dev` or `main`.** The dashboard and showcase (Parts B and C) are on `cloud/showcase`, from the parallel session.

**TL;DR.** All nine Part A items are done and tested. The serial protocol is unchanged, so the firmware needs no change beyond what `dev` already has. For the first time it has also been **compiled** (no warnings) and **run in an AVR simulator**, which confirmed the e-stop design against the real AccelStepper. 310 tests pass (on a fresh clone with only the CI dependencies, and under single-core stress), including the whole app running against an emulator of the firmware. The review passes found and fixed the problems listed below; 3 decisions are waiting for you.

---

## What was done

| # | Plan item | Where | Status |
|---|---|---|---|
| 1 | Pan-only cleanup | `coop/config.py`, `motors.py`, `control.py`, `main.py`, `stream.py` | ✅ The tilt fields are gone from the config and the control path. `/api/status` still reports `tilt: 0`, `tilt_enabled: false`, `tilt_limits: [0, 0]`. The wire format is unchanged (the tilt field is always `0`), so the firmware is untouched apart from a comment. |
| 2 | Fake Arduino | `tools/fake_uno.py` | ✅ A real-time emulator of the `.ino` over TCP (`socket://` via pyserial's URL handlers, cross-platform). Each connection is a DTR reset (READY), 50 ms `P` reports, T/C/Z/S/E/H with the sketch's exact parsing quirks, the 2 s watchdog, and an AccelStepper-style trapezoid. **It tracks the step counter and the physical shaft separately**, so tests can see lost steps. `MotorConfig.port` / `--motor-port` accept `socket://host:port`. |
| 3 | Settings file | `coop/settings.py`, `coop.example.toml` | ✅ `coop.toml` (gitignored) overrides the defaults; `coop.example.toml` lists every key at its default, and a test keeps it in sync. Unknown keys and wrong types stop startup with "did you mean". `--config` picks another file. Includes `pan_invert`, `microsteps`, `pan_gear_ratio`, limits, speed and accel, lead time, deadband, `conf`, and the new `idle_disable_s`. |
| 4 | Bench tools | `tools/jog.py`, `camera_check.py`, `bench_fps.py`, plus `rehearsal.py` | ✅ Documented in the README table. `jog` was driven through a real pseudo-terminal against the emulator. `bench_fps` was run for real here with ultralytics 8.4 (the PyTorch and NCNN export plus benchmark), and COOP's own `Detector` loaded the exported NCNN folder. `rehearsal` is the whole app with no hardware. |
| 5 | Safety | `POST /api/estop`, `/api/arm`, `/api/zero`; idle power-down | ✅ See "Safety design" below. |
| 6 | Latency and threading | `FrameGrabber` in `coop/camera.py` | ✅ Capture runs on its own thread and the loop always gets the newest frame (stale ones are dropped and counted). Frames carry their capture timestamp, which the **Kalman filter now uses** (it used to use processing time). Exposed as `diag.fps`, `capture_fps`, `infer_ms`, `latency_ms`. |
| 7 | Diagnostics | `coop/diag.py` | ✅ `diag: {cpu_temp_c, throttled, fps, capture_fps, infer_ms, latency_ms, serial, uptime_s}`. Every key is always present, `null` when unknown. The temperature comes from `/sys`, throttling from `vcgencmd get_throttled` (falling back to the firmware sysfs node), cached for 2 s. |
| 8 | Live tuning | `GET/POST /api/settings` | ✅ `lead_time_s`, `deadband_deg`, `conf`, `max_steps_per_sec`, `accel_steps_per_sec2`, `pan_invert`. Changes are validated all-or-nothing; speed and accel are re-sent to the Uno as one `C`; `pan_invert` changes only in stop mode; `"save": true` writes `coop.toml`, keeping its comments. |
| 9 | `docs/HARDWARE_TEST.md` | | ✅ Rewritten in the order emulator → jog → camera check → FPS bench → full run, using `coop.toml` instead of editing `config.py`. |

The API contract for all of this was written into `docs/API.md` **first** (the first commit) so the dashboard session could build against it. I checked `cloud/showcase`'s `web/app.js` and `web/mock.js` afterwards: they use exactly these names (`estop`, `/api/arm`, `/api/zero`, `gimbal.drivers_enabled`, every `diag` key, the throttle bits, `/api/settings` with `ranges` and `steps_per_deg`).

Beyond the plan: `tools/firmware_sim/` runs the **real compiled firmware** in simavr and counts its actual STEP pulses. It agrees with `tools/fake_uno.py` within ~2% on every scripted scenario, and it confirms with the real AccelStepper that "S then E 0" loses 334 steps (75°) while COOP's sequence loses none. Numbers are in `tools/firmware_sim/README.md`.

Also: `README.md` (settings, safety, bench tools), `docs/TERMINALS.md` (the new files go to lane 3), `docs/DEVPOST.md` (What it does, How we built it, a new Challenge, Testing), `hardware/README.md` (pan-only note, `coop.toml`), and the plan in `docs/superpowers/plans/2026-09-26-hardware-ready.md`.

## Safety design (worth reading before tomorrow)

- **E-stop ≠ "S then E 0".** AccelStepper keeps counting the steps of its braking ramp even with the drivers disabled, so cutting power right after `S` would leave the Uno's counter ahead of the shaft by up to v²/2a ≈ 333 microsteps ≈ **75°** at the defaults. `estop()` sends `S` at once, then `E 0` as soon as the reported position has been still for 0.25 s, with the worst-case braking time + 0.3 s as a hard deadline. The e2e test stops the emulator at full speed and asserts counter == shaft; a mutation test that cuts power immediately makes 4 tests fail.
- **Never a `T` while the drivers are off.** `aim()` refuses during an e-stop and sends `E 1` before any `T` after an idle power-down (even when the aim is inside the deadband).
- **The Uno boots with its drivers enabled**, so the reconnect handshake re-sends `E 0` when e-stopped or idle.
- **E-stop is serialized** against arm/zero: an e-stop pressed during an in-flight arm can't be undone by it (this was a real race, with a test).
- **`frame_epoch`**: `zero()` and a `pan_invert` flip change what every angle means; aims computed from the old frame are dropped, and the loop resets the Kalman filter.
- **Entering manual now holds the current pan** instead of jumping back to an old manual setpoint (e.g. auto has moved the camera to −30°, the last manual aim was +40°, and switching to manual used to swing it 70°).

## Integration check with `cloud/showcase` (local only, nothing pushed)

I merged both branches in a throwaway worktree. The only conflicts are docs, as expected: each branch has its own `docs/MORNING_REPORT.md`, and both edited `docs/DEVPOST.md`, so keep both sets of additions. The code merges cleanly and all 310 tests pass on the merge. I then ran `tools.rehearsal` with the **new dashboard** and drove it in headless Chromium at 1440 px:
- It used the real backend (not its mock). The diagnostics strip showed live `fps`, `capture_fps`, `infer_ms`, `latency_ms`, `serial: connected` and `uptime`, with CPU/Power as "–" (no `/sys` here, as designed).
- Clicking **E-stop** gave `estop: true`, `mode: stop`, `drivers_enabled: false`, and the banner's **Arm** released it. The tuning panel read `/api/settings` (it converts steps/s to 450°/s using `steps_per_deg`).
- No console errors, no failed requests.
- **One observation for the dashboard lane:** with a moving target, the drawn box trails the video by about 50 px. Boxes come from `/api/status` (polled ~300 ms) while `/video` is live, and at 12°/s that lag is 3–4°. Not a backend bug; a faster status poll, or drawing only boxes whose `frame_seq` is close to the displayed frame, would tighten it.

## How each item was reviewed, and what the passes caught

Every item went through TDD (test first, watched fail) plus three passes: (1) correctness against the plan and `docs/API.md`, with an eye on motor safety; (2) testing: the full suite, the e2e runs, coverage, mutation checks; (3) rethink: is there a simpler or safer design?

| Pass | What it caught | Fix |
|---|---|---|
| 1 correctness (item 1) | Python's JSON parser accepts `NaN`; a NaN aim would reach `round(nan)` inside the vision loop and crash it. | Finite-number checks in the API, in `Control`, and in `Gimbal.aim` |
| 2 testing (item 2) | Mutation testing showed the emulator's line-truncation test couldn't fail (both behaviours gave the same answer). | Rewrote the test so truncation changes the outcome |
| 2 testing (item 2) | The emulator's `replug()` resumed the old in-flight move instead of power-cycling. | Replug is now a power-on reset, with a test |
| 2 testing (item 4) | The replug e2e test failed about 1 run in 6. The root cause: the emulator's braking used the integer step counter and ignored the fractional step, overshooting one step, and the test's ±0.3° tolerance hid a stale report. | Fixed the braking maths, added a no-overshoot test over five speed/accel combos, and made the test wait for the exact settled reading. 60/60 trials clean |
| 3 rethink (item 5) | The e-stop design itself: an immediate `E 0` loses position (above). | Stillness-based power-down with a deadline, and a generation counter so a stale watcher from an earlier e-stop can't cut power mid-ramp of a later one |
| 1 correctness (item 5) | Race: an e-stop landing inside `Control.arm()` between its check and its effect was silently undone. | `_safety_lock` serializes estop/arm/zero; the test reproduces the interleaving |
| 1 final pass | A `P` report the Uno sent just before processing `Z` could arrive after `zero()` and restore the old position (and the reconnect restore point). | Reports are ignored for 150 ms after a zero |
| 2 testing (item 8 e2e) | The whole-app test's manual-hold check was flaky. The cause was the test reading a pre-switch published status, not the app. | Reads `target_pan` from a frame after the switch; 10/10 clean |
| 1 final pass | Any POST with a JSON array or string body raised in `.get()` → **500** (partly pre-existing). | `_json_object()`, with a 40-case test |
| 1 final pass | The capture thread started before the YOLO model loaded, outside `try/finally`, so it leaked on a model-load failure. | Started last |
| 1 final pass | An unwritable or undecodable `coop.toml` raised `OSError`/`UnicodeDecodeError` → a 500 or a startup traceback. | Now a `SettingsError` (a 400, or the one-line startup error) |
| 3 rethink (contract) | Cross-checking the dashboard: it posts only changed keys, so "Apply", then "Save" answered `saved: false`, and an applied-but-unsaved change was lost on restart. | `save: true` now writes all six live values; `docs/API.md` updated; no dashboard change needed |
| 2 testing | Coverage review: the `--annotate` path, lock → loss on the new capture timestamps, the save re-parse safety net, and `bench_fps`'s export/rename flow never ran under test. | Tests added (a stand-in `ultralytics` module for CI) |
| 3 rethink (docs) | `HARDWARE_TEST.md`'s first draft used separate `tools.jog --goto` runs for the direction and scale checks. But every jog run re-opens the port, which resets the Uno and silently moves the zero. | Those checks now happen in one interactive session, with a warning |
| 3 rethink (validation) | The emulator's fidelity was only my reading of AccelStepper. | Ran the real firmware in simavr (above); it matches |
| 2 testing (final) | Running the committed `firmware_sim/build_and_run.sh` from a clean directory: it linked `-lelf`, which Ubuntu's libsimavr doesn't need and isn't installed. | Links without it, falling back to `-lelf` |
| 1 final pass | `camera_check` printed a raw traceback when no camera opens, the most likely failure tomorrow. | A one-line hint (`rpicam-hello --list-cameras`), with a test |
| 2 final pass | I had described `rehearsal --invert` as "runs to a limit" without running it. Running it: it turns away until it loses the walker (~60°). | Wording fixed in three places |
| 2 testing | A few of my own test bugs (10° isn't a whole number of microsteps; the uptime rounding; a TCP write race). | Fixed in the tests; no app change |

## How to preview it

- **Backend changes have no Cloudflare Pages preview worth opening.** Pages serves only `site/`, which this branch doesn't touch. If the project builds every branch, its alias would be `cloud-hardware-ready.coop-224.pages.dev`, identical to `dev`'s site. Preview the backend by running it:
  ```bash
  git fetch && git checkout cloud/hardware-ready
  pip install -r requirements.txt        # nothing new is required; tomllib is stdlib (Python ≥ 3.11)
  pytest -q                              # 310 passed, about 35 s
  python -m tools.rehearsal              # open http://localhost:8000: tracking, E-STOP, ZERO, settings
  ```
- To see the new dashboard driving this backend, merge both branches locally (they touch disjoint files except `docs/DEVPOST.md`, which may need a trivial merge) and run `python -m tools.rehearsal`.

## Decisions for you

1. **A COOP restart moves the zero.** This is pre-existing and not new tonight, but it matters more now that systemd restarts on crash. Opening the serial port resets the Uno, whose counter restarts at 0 wherever the shaft is. After a crash-restart with the camera at 60°, "0°" is 60° off and the ±170° limits no longer protect the cables. Options:
   - (a) persist the last reported position to a file and restore it with `Z <pos>` on the first connect. This is right after a crash; wrong if the shaft was turned by hand while the drivers were off or unpowered.
   - (b) stop the Uno resetting on open (DTR handling). This is unreliable on Linux, and the handshake relies on `READY`.
   - (c) a homing switch.
   - (d) status quo plus the procedure (Home before stopping; E-STOP, turn by hand, ZERO after anything odd).

   **Recommendation: (d) for tomorrow and the demo, (c) if time allows.** I didn't implement (a) because a wrong restore is worse than a known reset.
2. **`idle_disable_s = 20`.** The TMC2209 in standalone mode may already reduce standstill current (I couldn't verify the OTP default here), so you may prefer a longer value or `0` (never), since while disabled the camera can be pushed by hand and lose its position. It's one line in `coop.toml`.
3. **NCNN in "Built with".** The Devpost list is at 25/25 tags. If NCNN wins the bench on the Pi, swap a tag (e.g. `html` or `css`) for `ncnn`. I didn't, because it isn't used until you choose it.

## Not done / limits (and why)

- **Nothing ran on real hardware** (there is none here). `docs/HARDWARE_TEST.md` still tags every step `[never run]`.
- **Firmware:** compiled and simulated, never flashed. It was compiled by hand with avr-gcc 7.3, the Arduino AVR core 1.8.6 and AccelStepper 1.64 (the Arduino package index is blocked from this sandbox, so `arduino-cli` couldn't install the core). The Arduino IDE may use a newer core; that's fine, the sketch uses nothing version-specific.
- **`tools/jog.py`'s Windows key reader** (`msvcrt`) wasn't exercised; only the POSIX path ran through a real pty. On Windows, `--goto/--by/--zero` don't use it.
- **Bench numbers here are x86 and meaningless for the Pi** (both backends ran at about 55 fps). Tomorrow's section 6 produces the real ones.
- **Known limit:** an unplug *mid-move* can leave the restored position off by up to `max_steps_per_sec × 50 ms` (the last report's age, 22° at defaults). A test documents the bound. Re-zero after one.
- CI (`.github/workflows/tests.yml`) runs on pushes to `dev`/`main` and on PRs, so it hasn't run on this branch; it will on the PR. The suite only needs `.github/requirements-ci.txt`.

## Tomorrow's hardware session, step by step

Full checklist with the expected results: `docs/HARDWARE_TEST.md`. In short:

1. **Laptop, before touching hardware:** `pytest -q`, then `python -m tools.rehearsal` (watch it track; try E-STOP, ZERO, arm), then `python -m tools.rehearsal --invert` to see what a wrong motor direction looks like.
2. **Pi setup:** `bash scripts/setup_pi.sh`, re-login, download `yolo11n.pt`, `cp coop.example.toml coop.toml` and set `microsteps` and `pan_gear_ratio` to the real build.
3. **Flash the Uno**, Serial Monitor sanity check (`READY`, `P 0 0`, `Z 400 0`).
4. **Motor, camera NOT mounted:** set Vref, then in **one** `python -m tools.jog` session check holding torque, direction (→ must turn right; else `pan_invert = true`), scale (45° step ×2 = 90°), and e-stop mid-move (`e`, then `e`, then `0` returns to the tape mark).
5. **Camera:** `rpicam-hello --list-cameras`, then `python -m tools.camera_check --source picamera`; check the still for colours and orientation.
6. **FPS:** `python -m tools.bench_fps --export`, then `python -m tools.bench_fps`; put the winner in `coop.toml` `[detector]`.
7. **Full run:** `python -m coop.main --source picamera`, Manual moves, Stop → idle power-down, limits with the camera mounted, then closed-loop tracking at reduced limits/speed. Tune `lead_time_s` / `deadband_deg` live from the dashboard and **Save**.
8. **Resilience:** E-STOP mid-move, `pkill`, USB unplug/replug, then systemd and the tunnel.

---

## Morning report: `cloud/showcase` (Parts B and C)

Overnight cloud session, 2026-09-26. Branch **`cloud/showcase`** (from `dev`), pushed; nothing went to `dev` or `main`. Part A is on `cloud/hardware-ready` with its own report.

## TL;DR
- **Showcase (`site/`)**: rebuilt from scratch as a cinematic WebGL site: dotted-ring loader with an Enter `>>>` gate, the "COOP" scrambleText decode (→ full name → tagline), and seven scroll-driven chapters in one persistent three.js scene. Reduced-motion and no-WebGL versions, phones, docs. **Preview:** `https://cloud-showcase.coop-224.pages.dev` (Cloudflare Pages branch alias for `cloud/showcase`; see "Previewing").
- **Dashboard (`web/`)**: same black/white/orange identity; pan-only with the pan gauge as the hero instrument (click or drag it to aim), leader-line detection labels that decode in, E-stop / Arm / Zero, a diagnostics strip, live tuning, and a designed state for every failure. **Tested end to end against Part A's real backend** (`tools/rehearsal.py`: real loop + fake Uno + synthetic camera).
- Screenshots of everything: `docs/screenshots/` (39 JPEGs: site at 1440 and 390 px, reduced motion, no WebGL; dashboard live, manual and every state). (These screenshots show the old gimbal dashboard and will be replaced.)

## What was done

### Part B: the showcase
| Chapter | What happens |
|---|---|
| Loader | 48-dot ring filled by real load progress (fonts → anime.js → three.js + scene → shaders compiled), reticle ticks, "Locked", then **Enter `>>>`** (click or Enter key). |
| Intro | Brackets close in like autofocus; **"COOP" decodes out of noise** letter by letter with anime.js `scrambleText` (cursor `░▒▓█`), brackets snap orange (lock), the line below decodes into "Computer-vision Object Observation & Prediction", then re-scrambles into "COOP keeps an eye on the coop." while the full name settles above the word. |
| 01 See | A street of ~20k points (people walking, cars, lamps, facades) forms out of the intro's noise. COOP's own 4:3 viewfinder with a live frame counter, and a band sweeping down the frame like the OV5647's rolling shutter. |
| 02 Detect | Corner brackets snap onto each figure in turn with leader lines and mono labels (`PERSON #3 · CONF 0.87`) that scramble in; the target locks (orange). |
| 03 Predict | The camera follows with lead; velocity arrow, orange ghost at *t*+1.6 s with a fading trail and aim reticle, angular rate label. Mid-chapter the copy hands over to the typeset equations (pixel→world angle and the lead aim), with annotated terms. |
| 04 Move | Third-person view: the rig turns to follow, its field-of-view frustum fades out from the lens, a dashed aim ray, and a ±170° arc gauge (pan, aim, limits). |
| 05 Build | Exploded, to-scale technical drawing: 12 V supply → buck, NEMA 17, TMC2209, Uno, Pi 5, OV5647, with aligned leader-line labels. |
| 06 Gallery | A 3D ring of 8 cards that turns card by card with scroll, plus drag with inertia. Placeholder cards until media is added. |
| 07 Team | David + teammate placeholder, GitHub and Devpost links, and a closing portrait of the rig slowly scanning. |

Also: a floating pill nav (collapses to "07 Menu" on phones), the chapter scrubber (`03 / 07`) and a **bearing tape** along the bottom that slides with the camera's pan angle (the design's signature: in COOP, scroll *is* panning), word-by-word reveals scrubbed by scroll, and a desktop cursor that turns into lock brackets over links and says "Drag" over the gallery.

**Quality bar, measured:**
- Console: 0 errors and 0 warnings across every run (1440, 390, reduced motion, no WebGL).
- No horizontal overflow at 1440 or 390.
- Load before the first interaction: about **1.16 MB raw / 450 KB gzipped** (three.js is 742 KB of that, behind the loader). Gallery media loads only near the gallery; GLTFLoader only if a model is set; the equation fonts are ~50 KB.
- 60 fps: **not verifiable here** (the container renders WebGL on the CPU through SwiftShader: 12–25 fps there). The scene is built for it: one draw call for all points with the animation in the vertex shader, capped point sizes, DPR capped at 1.75, and adaptive resolution that drops the pixel ratio if frames stay slow. Please check on a real laptop.
- Reduced motion: a still version with no gate; chapters cut between static compositions.
- No WebGL: the same scene is rendered as still frames on a 2D canvas; the gallery becomes a grid.

`site/README.md` explains editing copy, adding photos/videos (one `<li>` per item), swapping in the real camera `.glb` (one constant in `js/stage/solids.js`; tested with a generated test model), and deploying. `site/CREDITS.md` lists licenses.

### Part C: the dashboard
- **Identity:** `web/tokens.css` now matches the showcase; `docs/DESIGN_BRIEF.md` rewritten. No red or green: severity is orange plus shape (hazard stripes, fill vs. outline).
- **Pan-only:** the tilt D-pad is gone. The gauge shows pan (needle), aim (orange mark) and limits, with ◀ Home ▶ and click/drag-to-aim in Manual.
- **Detections:** corner brackets with leader-line mono labels that flip at the frame edge; a newly seen or newly acquired target's label decodes in.
- **Safety:** one-click **E-stop** (also key `X`, fires before anything re-renders), **Arm** from the banner, **Zero here** with a 3 s confirm click.
- **Diagnostics strip:** CPU °C, power/throttling (decoded bits in the tooltip), vision fps, camera fps, inference ms, latency ms, Arduino link, uptime. Missing values show "–".
- **Tuning panel** (collapsed): lead time, deadband, confidence, max speed and acceleration (shown in °/s), pan invert (only in Stop), Apply or Apply and save.
- **Designed states:** no camera, Arduino reconnecting, signed out (Access expired), offline, stale, e-stop, drivers powered down, no target (four variants). Preview any of them with mock data: `web/index.html?demo=nocam|reconnecting|expired|offline|stale|estop|notarget|hot`.
- **`web/mock.js`** implements the whole new contract (estop/arm/zero/settings, diag, drivers idle, events).

## Review passes (what each one caught)

### Showcase
1. **Correctness (first screenshots):** leader lines from the Build chapter stayed on screen through Gallery and Team. Diagnosed: `clearRect` on the overlay canvas did not clear it (reproduced with an explicit clear + readback; a bitmap reset did). The overlay now resets its bitmap per drawn frame and skips drawing when idle. Also: people walked behind the copy, labels ran off the right edge, the equations overlapped the target, the exploded view was too big and clipped, the gauge's labels collided, the carousel sat between cards, and the orange cursor was stuck at (0,0) after the gate.
2. **Retest:** fixed the above: an off-centre camera (subject right of the copy on desktop, above it on phones), a shader fade for anything passing behind the copy, labels that flip left at the edge, the copy→equations hand-off in 03, a smaller exploded view with aligned labels, a gauge moved out of the scene, and the carousel dwelling card by card. The target now paces back and forth instead of wrapping around, so every chapter reliably has it in frame and the prediction visibly flips when it turns. On phones: the wordmark clipped and the narrow aspect cropped the scene out entirely; fixed with a phone-sized wordmark and a minimum horizontal FOV.
3. **Art direction:** every chapter was the same template, and 01 See had no moment of its own, so See got the viewfinder, frame counter and rolling-shutter sweep. The ghost read as a smear (moved further ahead, trail made fainter). Labels re-scrambled on every number tick (now only when their subject changes).
4. **Final pass, weakest section:** 07 Team ended on a generic particle field. It now closes on a portrait of the rig scanning (dimmed on phones, where it would sit behind text).

### Dashboard
1. **Correctness:** with no gimbal data (no camera / signed out) the gauge was blank; the "Arduino reconnecting" chip was unreadable on hazard stripes; on phones the diagnostics came before the pan instrument (a CSS ordering bug); labels clipped at the right edge on phones.
2. **Retest against the real backend** (`tools/rehearsal.py` from `cloud/hardware-ready`, driven by Playwright): mode switches, nudge (+10°), dial click (→ −85° as expected), Home, E-stop (drivers off, banner), a mode change blocked with a clear message, Arm, two-step Zero, a settings change applied server-side, pan-invert locked outside Stop, and the event log showing every step. 0 console errors.
3. **Art direction:** a filled orange "Lock target" was the loudest thing on the page and competed with E-stop; it's now an orange outline, so E-stop is the only filled orange control. Removed a middle-dot hint row that wrapped badly.

## Decisions I made (please check)
1. **Design direction "Bearing"** out of three (`docs/DESIGN_DIRECTIONS.md`): Archivo at its widest for display, Martian Mono for telemetry, STIX Two for the equations only. Orange means lock.
2. **Libraries are vendored, not loaded from a CDN.** jsdelivr/esm.sh were blocked from the container, and self-hosting is faster and has no third-party dependency on demo day anyway. three.js was minified with esbuild once (documented in `site/README.md`); there's still no build step.
3. **The dashboard does not load anime.js**: the label scramble is ~30 lines in `app.js`, so the Pi serves no extra 118 KB.
4. **The dashboard now depends on Part A's API** (`estop`, `diag`, `/api/estop|arm|zero|settings`), with field names taken from `docs/API.md` on `cloud/hardware-ready` (it was already there). I did not edit `docs/API.md` on this branch, to avoid a conflict. **Merge `cloud/hardware-ready` first**, then this branch. Against an old backend it degrades: diagnostics show "–", and E-stop/Zero/Tuning report "This COOP build doesn't support that yet."
5. **Devpost "Built with"** was already at 25 tags; I swapped `libcamera` (covered by `picamera2`) and `computer-vision` (a topic, not a tool) for `three.js` and `anime.js`. Part A also edits `docs/DEVPOST.md`, so expect a small merge conflict there.
6. **Numbers on the showcase:** real where they describe COOP (FOV, frame size, 150 ms lead, ±170° limits, parts). The detection confidences, walking figures and frame counter are an illustration; `site/README.md` says so. The ghost is drawn 1.6 s ahead (labelled `AIM · t + 1.6 s`) because 150 ms would be invisible.
7. **E-stop keyboard shortcut is `X`** (not Space or Escape, which scroll or close things).

## What's not done / needs you
- ✏️ Placeholders: teammate name and line, the Devpost URL, gallery photos and videos, the real hostname in `<head>`, and a `.glb` of the camera if you want it (all listed in `site/README.md`).
- Real-GPU performance check (see above).
- Cloudflare Pages: if project `coop-224` isn't connected to the repo yet, connect it (framework None, no build command, output `site`), then the preview URL above works.
- `docs/API.md` on this branch is the old version until `cloud/hardware-ready` is merged.

## Previewing
- **Cloudflare Pages:** `https://cloud-showcase.coop-224.pages.dev` (branch alias = branch name lowercased, `/` → `-`).
- **Locally:** `python -m http.server 8765 --directory site`, then `/`, `/?still` (reduced motion), `/?nogl` (no WebGL), `/#build` (deep link).
- **Dashboard without hardware:** `python -m http.server 8767 --directory web` and open `/?demo=estop` (or any state above). With Part A merged: `python -m tools.rehearsal` and open http://localhost:8000.

## Tomorrow's hardware session (dashboard side)
Follow `docs/HARDWARE_TEST.md` on `cloud/hardware-ready` for the bench order (emulator → jog → camera check → FPS bench → full run). On the dashboard:
1. Open the dashboard; the header should say **Live · N fps** (no "mock") and the Pan chip **Motors live**. The diagnostics strip should show a real CPU temperature and **Arduino: connected**.
2. **Before anything moves, find E-stop** (top right, or `X`). Press it once: the banner says the drivers are off and the shaft should turn freely by hand. Press **Arm**.
3. Switch to **Manual** (`2`), press ▶ once. If the camera turns left, open **Tuning**, switch to **Stop**, tick **Invert pan**, **Apply and save**.
4. Point the camera straight ahead by hand (during E-stop if needed), then **Zero here** twice.
5. Click the dial at +30° and −30°: the camera should follow the needle. If it overshoots or crawls, adjust **Max speed** / **Acceleration** in Tuning.
6. **Auto** (`1`), walk across the room: the brackets should lock (orange when you click your box), and the orange aim mark should lead you. Tune **Lead time** so the aim sits just ahead, and **Deadband** if it jitters while you stand still.
7. Unplug the Uno's USB: the banner should say **Arduino reconnecting** and the camera should hold still; plug it back in and it resumes.
8. Watch **Power** and **CPU**: anything other than "OK", or ≥ 80 °C, turns orange. Hover for the decoded throttle bits (under-voltage usually means the buck is set too low or the cable is too thin).

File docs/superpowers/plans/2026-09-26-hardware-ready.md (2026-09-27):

> **Outdated: from the motorized-gimbal era.** COOPER is now a fixed dashcam; see README.md and docs/MATH.md.

# Hardware-ready backend implementation plan

> Written with the `writing-plans` skill for the unattended overnight session (Part A of
> `docs/CLOUD_PLAN.md`). Executed natively in the same session, task by task, TDD.

**Goal:** make the backend ready for tomorrow's first hardware session: pan-only control path,
an Arduino emulator, a settings file, bench tools, e-stop/zero/idle-disable, a capture thread
with latency measurement, diagnostics, and live tuning.

**Architecture:** the serial wire protocol stays byte-for-byte what `firmware/coop_motors`
already implements (tilt is always sent as `0`), so no firmware change is needed. Safety state
(e-stop, driver enable, frame-of-reference epoch) lives in `Gimbal`, which owns the serial
link; `Control` owns operator state and calls the gimbal outside its own lock. Live settings
go through one `LiveSettings` object that validates, applies and optionally saves.

**Tech stack:** Python 3.11+ stdlib (`tomllib`, `threading`, `socketserver`), pyserial URL
handlers (`socket://`), Flask, pytest.

**Spec:** `docs/CLOUD_PLAN.md` Part A; wire contract `docs/API.md`.

## Global constraints
- `pytest` green on every commit; tests never import `ultralytics`/`picamera2`.
- Pan-only, permanently. `/api/status` keeps `gimbal.tilt: 0`, `gimbal.tilt_enabled: false`.
- Every tunable in `coop/config.py`; hardware imports lazy; runs on a laptop without hardware.
- Serial protocol changes must update both `coop/motors.py` and the `.ino` (none planned).
- Never push to `dev`/`main`. Commit only own paths. Keep `docs/DEVPOST.md` in sync.

## Review focus (failure modes no single feature test covers)
1. A `T` sent while the drivers are disabled: AccelStepper counts steps the rotor never makes,
   and the Pi's position silently desyncs. → emulator tracks counter *and* rotor; e2e asserts
   they agree after e-stop, idle-disable and re-arm.
2. E-stop mid-move: `S` then an immediate `E 0` lets the counter run through the decel ramp
   with no torque (up to 75° at defaults). → disable only after the worst-case decel time.
3. A reconnect while e-stopped: the Uno reboots with drivers enabled. → `_connect` re-sends `E 0`.
4. `zero` or an invert flip while the loop is mid-iteration: a stale-frame aim moves the
   camera in the new frame. → gimbal `frame_epoch`; `aim()` drops commands from an old epoch.
5. A typo in `coop.toml` silently ignored. → unknown keys and wrong types fail loudly at startup.

---

### Task 0: API contract first
Write every new field and endpoint into `docs/API.md` and push, so the dashboard session can
build against it. Names below are final.

### Task 1: Pan-only control path
- `MotorConfig`: drop `tilt_gear_ratio`, `tilt_enabled`, `tilt_limits_deg`; add
  `pan_invert: bool = False`, `idle_disable_s: float = 20.0`.
- `Gimbal`: `pan` property (deg), `aim(pan_deg, deadband_deg=0.0, epoch=None)`, wire lines
  `T <steps> 0`, `Z <steps> 0`; `P a b` parses `a`. `steps_per_deg` property.
- `Control`: `manual_pan` (float) replaces `manual_aim`; `set_aim(pan)`, `nudge(dpan)`.
  `/api/aim` and `/api/nudge` accept but ignore `tilt`/`dtilt` (now optional).
- `main.py`: world tilt = in-frame offset only (gimbal tilt fixed at 0); predictor stays 2-D.
- Tests: update `test_motors`, `test_reconnect`, `test_control`, `test_stream`; add
  `test_aim_accepts_missing_tilt`, `test_status_keeps_tilt_fields`.

### Task 2: Fake Arduino (`tools/fake_uno.py`)
- `UnoModel`: pure state machine (`feed(bytes)`, `advance(dt)`, `drain_output()`), mirrors the
  .ino: 48-byte line buffer, `\r` ignored, `sscanf`-style parsing (so `Z 5` zeroes, like the
  real one), watchdog 2 s, 50 ms `P` reports, AccelStepper-style trapezoid, `stop()` target
  = position + stopping distance. Tracks `counter` (what it reports) and `rotor` (physical,
  moves only while enabled).
- `FakeUnoServer(host, port, boot_delay_s)`: TCP; each accepted connection = a DTR reset
  (counter → 0, drivers enabled, default limits, `READY` after boot delay). `unplug()` /
  `replug()` for reconnect tests. CLI: `python -m tools.fake_uno --port 5555`.
- `Gimbal._connect`: ports containing `://` open via `serial.serial_for_url`.
- `main.py --motor-port`.
- Tests: `tests/test_fake_uno.py` (model unit tests), `tests/test_gimbal_e2e.py` (real Gimbal
  over TCP: handshake, aim reaches target, watchdog, reconnect restores position with
  `counter == rotor`).

### Task 3: Settings file (`coop/settings.py`)
- `load_config(path=None) -> Config` (defaults ← `coop.toml` ← CLI), `validate_config(cfg)`,
  `SettingsError`. Unknown sections/keys and wrong types raise with the valid names listed.
- `save_settings(path, {section: {key: value}})`: in-place line edits that keep comments,
  verified by re-parsing.
- `coop.example.toml` committed; `coop.toml` gitignored; `main.py --config`.

### Task 4: Safety (e-stop, arm, zero, idle disable)
- `Gimbal.estop()`: `S` now, `E 0` after `max_speed/accel + 0.2 s`; `arm()`: `E 1`;
  `zero()`: `Z`, epoch++; idle: `E 0` after `idle_disable_s` of `stop()`; `aim()` re-enables
  with `E 1` before `T`; `aim()` is ignored while e-stopped; `_connect` re-sends `E 0`.
- `Control.estop()/arm()/zero()`, `bind_gimbal()`, e-stop blocks auto/manual/lock/home.
  Entering manual holds the current pan.
- Routes `POST /api/estop`, `/api/arm`, `/api/zero`. Events `estop`, `armed`, `zeroed`,
  `motors_idle`.

### Task 5: Capture thread + latency
- `FrameGrabber(camera)` in `coop/camera.py`: newest-frame handoff, stale frames dropped,
  camera exceptions re-raised in the consumer *after* any pending frame.
- `diag.fps`, `diag.capture_fps`, `diag.infer_ms`, `diag.latency_ms` (capture → publish).

### Task 6: Diagnostics (`coop/diag.py`)
- `read_cpu_temp_c()`, `read_throttled()`, `SystemMonitor.snapshot()` (2 s cache).
- `/api/status.diag` always has every key (null when unknown); `serial` from
  `Gimbal.link_state`; `uptime_s` = process uptime.

### Task 7: Live tuning
- `LiveSettings` + `GET/POST /api/settings`; atomic validation; `pan_invert` only in `stop`;
  speed/accel re-sent to the Uno with `C`; `save: true` writes `coop.toml`.

### Task 8: Bench tools + docs
- `tools/jog.py`, `tools/camera_check.py`, `tools/bench_fps.py`, `tools/rehearsal.py`
  (full app with synthetic camera/detector against the fake Uno).
- `docs/HARDWARE_TEST.md` order: emulator → jog → camera check → FPS bench → full run.
- README, DEVPOST, `docs/MORNING_REPORT.md`.

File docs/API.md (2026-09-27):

# COOPER web API contract

The contract between the Pi backend (`cooper/stream.py`, `cooper/settings.py`) and the dashboard (`web/`). Both sides build against this file. **If you change it, change it here first**, then the code on both sides.

Base URL: `http://<pi>:8000` (or `http://localhost:8000` on the laptop). All JSON. Boxes are `[x1, y1, x2, y2]` and points `[u, v]` in frame pixels, origin top-left. The lane is in **normalized** frame coordinates (0..1), so it survives a resolution change.

## Read

### `GET /video`
MJPEG stream (`multipart/x-mixed-replace`) of the camera frame. Use as `<img src="/video">`. The frame is **clean by default**: the dashboard draws the boxes, predicted paths and lane client-side from `/api/status`. `python -m cooper.main --annotate` burns boxes into the frame for debugging without the dashboard.

### `GET /api/status`
Polled by the dashboard (~300 ms).
```json
{
  "server_time": 1790000000.12,
  "frame_seq": 18234,
  "fps": 14.2,
  "frame": { "w": 640, "h": 480 },
  "objects": [
    {
      "id": 201, "label": "car", "conf": 0.9, "box": [412, 230, 506, 308],
      "level": "warning", "kind": "path",
      "reason": "car #201 heading into your lane in 0.8 s",
      "path": [[455.1, 308.0], [448.9, 308.0], "... 15 points ..."],
      "velocity": [-61.8, 0.4],
      "ttc_s": null,
      "time_to_lane_s": 0.8
    }
  ],
  "risk": { "level": "warning", "reason": "car #201 heading into your lane in 0.8 s" },
  "leds": { "yellow": true, "red": false, "mode": "mock" },
  "lane": [[0.44, 0.6], [0.56, 0.6], [0.79, 1.0], [0.21, 1.0]],
  "diag": {
    "cpu_temp_c": 61.3,
    "throttled": 0,
    "fps": 14.2,
    "capture_fps": 30.0,
    "infer_ms": 48.5,
    "latency_ms": 71.0,
    "leds": "gpio",
    "uptime_s": 3605.2
  }
}
```
- Before the first frame is published the payload is just `{server_time, diag}`; clients must tolerate missing fields.
- `server_time`: stamped per request, so it is always fresh; it does **not** tell you the vision loop is alive. Don't compare it to the client's clock (Pi and phone clocks differ).
- `frame_seq`: increments once per frame the main loop publishes. The dashboard shows "stale" when it stops advancing for 2 s, timed on the client's own clock.
- `objects`: every object ByteTrack has given an ID this frame (unconfirmed detections have no ID and are left out). Detected classes: person, car, motorcycle, bus, truck.
  - `level`: `"clear"`, `"warning"` or `"danger"`, this object on this frame, before hysteresis.
  - `kind`: which rule set the level: `"in_lane"` (danger: its bottom edge is in the lane now), `"path"` (warning: its predicted path enters the lane), `"ttc"` (warning: short time to contact inside the lane's corridor), or `null`.
  - `reason`: human-readable, `""` when clear.
  - `path`: the predicted **bottom-centre** (where it meets the road), every `step_s` (0.1 s) out to `horizon_s` (1.5 s): 15 points by default. The first point is 0.1 s ahead, not now.
  - `velocity`: `[u', v']` of the bottom-centre in px/s, from the object's Kalman filter.
  - `ttc_s`: time to contact from the box's scale growth, `h / h'`, in seconds, or `null` when the box isn't growing significantly. Present whatever the object's level.
  - `time_to_lane_s`: seconds until the predicted path enters the lane (`kind: "path"` only), else `null`.
- `risk`: what the LEDs show, **after** hysteresis: a level lights after `enter_frames` (2) frames in a row and stays `hold_s` (0.5 s) after its condition ends. `reason` is that of the object that set it (the nearest for danger, the soonest for warning). docs/MATH.md has the rules.
- `leds`: the LED state. Only one is ever lit (red overrides yellow). `mode` is `"gpio"` (real LEDs on the Pi) or `"mock"` (anywhere else, or `--no-leds`).
- `lane`: "my lane", the four corners top-left, top-right, bottom-right, bottom-left, normalized. Change it with `POST /api/lane`.
- `diag`: health readouts. **Every key is always present; a value is `null` when unknown** (e.g. before the first frame, or `cpu_temp_c` on a laptop without `/sys`). Computed fresh on each request except the four pipeline timings, which the vision loop publishes per frame.
  - `cpu_temp_c` (number | null): SoC temperature in °C from `/sys/class/thermal/thermal_zone0/temp`. Pi 5 soft-throttles at 80–85 °C.
  - `throttled` (integer | null): the `vcgencmd get_throttled` bit field as an integer; **`0` means healthy**. Bits: `0x1` under-voltage now, `0x2` ARM frequency capped now, `0x4` throttled now, `0x8` soft temperature limit now; the same four shifted by 16 (`0x10000`…`0x80000`) mean "has happened since boot". Show it as hex (`0x50005`).
  - `fps` (number | null): vision-loop frames processed per second (same value as top-level `fps`): 1 / the moving average of the interval between processed frames' capture times.
  - `capture_fps` (number | null): frames per second the camera delivers. When it's well above `fps`, inference is the bottleneck and stale frames are being dropped (always the newest frame is processed).
  - `infer_ms` (number | null): YOLO + tracker time per frame, smoothed.
  - `latency_ms` (number | null): from the moment the frame was captured until its status/JPEG was published, smoothed. The LEDs are set just before publishing, so this is the camera-to-LED latency.
  - `leds` (`"gpio"` | `"mock"` | null): how the LEDs are driven (same as `leds.mode`).
  - `uptime_s` (number): seconds since COOPER started (not since the Pi booted), so a jump back to ~0 means the service restarted.

### `GET /api/events?since=<seq>`
Recent event log (the last 200), newest last. `since` returns only events with `seq > since`.
```json
{ "events": [ { "seq": 41, "t": 1790000000.1, "type": "risk_changed", "level": "danger", "reason": "car #201 in your lane" } ] }
```
Event types:
- `risk_changed`: the LED level changed. Extra fields `level` and `reason` (`""` when clear).
- `lane_changed`: the lane was changed and/or saved. Extra fields `lane` (the four corners) and `saved` (bool).
- `settings_changed`: live settings changed and/or were saved. Extra fields `changed` (object of the values this request changed; `{}` for a bare save) and `saved` (bool).

## Control
All return `{"ok": true, ...}`, or `{"ok": false, "error": "..."}` with HTTP 400 (HTTP 404 if the server runs without live settings). Validation is all-or-nothing: on an error nothing is applied or saved.

### `POST /api/lane`
Body: `{"lane": [[x, y], [x, y], [x, y], [x, y]], "save": false}`: corners top-left, top-right, bottom-right, bottom-left, each 0..1. The top edge must be above the bottom edge and each left corner left of its right corner. Applied on the next frame. With `"save": true` it's also written to `cooper.toml` (`[risk] lane`), so it survives a restart.

Returns `{"ok": true, "lane": [...], "saved": false}`.

## Live settings

### `GET /api/settings`
```json
{
  "settings": { "conf": 0.4, "horizon_s": 1.5, "ttc_warn_s": 2.0, "ttc_clear_s": 2.5, "hold_s": 0.5 },
  "ranges": {
    "conf": [0.05, 0.95],
    "horizon_s": [0.1, 5.0],
    "ttc_warn_s": [0.1, 10.0],
    "ttc_clear_s": [0.1, 10.0],
    "hold_s": [0.0, 5.0]
  },
  "lane": [[0.44, 0.6], [0.56, 0.6], [0.79, 1.0], [0.21, 1.0]],
  "lane_default": [[0.44, 0.6], [0.56, 0.6], [0.79, 1.0], [0.21, 1.0]],
  "file": "/home/pi/cooper/cooper.toml"
}
```
- `conf`: YOLO confidence threshold. `horizon_s`: how far ahead each path is predicted. `ttc_warn_s` / `ttc_clear_s`: a time to contact below `ttc_warn_s` starts a warning, which ends only above `ttc_clear_s`. `hold_s`: how long a level stays lit after its condition ends.
- `ranges`: inclusive `[min, max]` for each setting (use them for slider bounds).
- `lane` / `lane_default`: the current lane and the built-in one (for a "reset" button).
- `file`: the settings file `save` writes to.

### `POST /api/settings`
Body: any subset of the `settings` keys (JSON numbers), plus optional `"save": true`.
```json
{ "horizon_s": 2.0, "save": true }
```
Returns `{"ok": true, "settings": {...all current values...}, "saved": true}`. Applied on the next frame, no restart. With `"save": true`, **all five live settings** (their values after this request) are written to `cooper.toml`; other settings and the comments in the file are kept. So `{"save": true}` on its own means "persist what's live now". Without it, changes last until COOPER restarts.

Rules between settings are checked on the result: `ttc_warn_s` must stay below `ttc_clear_s` (change both in one request to move the pair past each other).

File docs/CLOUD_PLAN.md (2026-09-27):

> **Outdated: from the motorized-gimbal era.** COOPER is now a fixed dashcam; see README.md and docs/MATH.md.

# Overnight cloud plan (2026-09-26)

A brief for a Claude Code cloud session working unattended overnight. David is asleep. **Hardware (Pi 5, Uno, TMC2209, NEMA 17, OV5647) is assembled tomorrow.** When he wakes up he should find: the backend ready for hardware, and a showcase site that looks like a professional studio built it.

Read first: `CLAUDE.md`, `docs/API.md`, `docs/TERMINALS.md`, `docs/HARDWARE_TEST.md`, `README.md`.

## Skills (in `.claude/skills/`, see its README)
- **Part A:** `writing-plans`, `test-driven-development`, `systematic-debugging`, `verification-before-completion`.
- **Parts B and C:** `frontend-design` for all design work, `brainstorming` in **unattended mode**: write 3 distinct design directions to `docs/DESIGN_DIRECTIONS.md` with your reasoning, pick the strongest yourself, don't wait for answers. Also `verification-before-completion`.

## Ground rules
- Work on **two branches off `dev`**: `cloud/hardware-ready` (Part A) and `cloud/showcase` (Parts B and C). Push them to GitHub. **Never push to `dev` or `main`**; David reviews and merges in the morning.
- Commit small and often, with descriptive messages, so the morning review can follow what changed.
- `pytest` must pass on every commit to `cloud/hardware-ready`. Keep tests free of `ultralytics`/`picamera2` imports (CI installs only `.github/requirements-ci.txt`).
- **The build is pan-only**, permanently. Tilt is never used.
- Libraries must be properly licensed (MIT/Apache/ISC). Use references for *inspiration*; never copy another site's code, 3D assets, images or text. Credit anything borrowed in `site/CREDITS.md`.
- Never invent content: no fake team members, photos, quotes or metrics. Use clearly marked placeholders (`✏️ PLACEHOLDER`).
- Keep `docs/DEVPOST.md` in sync (see `CLAUDE.md`).
- Finish with a morning report (see the end).

---

## Part A: hardware-ready backend (`cloud/hardware-ready`), do this FIRST
In priority order. Stop and report if anything would change the serial protocol in a way the flashed firmware doesn't support. Protocol changes must update both `coop/motors.py` and the `.ino`.

1. **Pan-only cleanup.** Remove tilt from the control path where that simplifies things (config, control, motors, status), but keep the `/api/status` fields that the dashboard reads (`tilt: 0`, `tilt_enabled: false`) so `docs/API.md` stays valid. Update tests.
2. **Fake Arduino emulator** (`tools/fake_uno.py`): speaks the exact firmware protocol (READY, P reports at 20 Hz, T/C/Z/S/E/H, the 2 s watchdog, AccelStepper-like accel/decel) and attaches through a virtual serial port (e.g. `socket://` via pyserial's URL handlers, or a pty on Linux). Add `MotorConfig.port` support for it. Add an end-to-end test that runs the real `Gimbal` against it, including a reconnect.
3. **Settings file** so nobody edits Python on the Pi: `coop.toml` (or JSON) next to the repo, overriding `coop/config.py` defaults, loaded at startup; an example file is committed and the real one gitignored. It includes **`pan_invert`** (motors often spin the wrong way the first time), `microsteps`, `pan_gear_ratio`, limits, speed/accel, lead time, deadband, and the confidence threshold.
4. **Bench tools** in `tools/`:
   - `jog.py`: keyboard or CLI pan jog over serial, no vision. Shows the position; sets zero.
   - `camera_check.py`: grab frames, report resolution and FPS, save a still.
   - `bench_fps.py`: YOLO FPS at imgsz 256/320/416, PyTorch vs NCNN, and an NCNN export helper. Document it in the README.
5. **Safety:**
   - `POST /api/estop` (immediate `S`, then drivers disabled with `E 0`, mode → stop; needs an explicit re-arm), plus `POST /api/zero` ("set zero here" → `Z`).
   - Disable the drivers after N seconds in stop mode. The steppers otherwise hold current and heat up.
   - Document both in `docs/API.md`. Add tests.
6. **Latency and threading:** capture in its own thread and always process the newest frame (drop stale ones). Measure the end-to-end latency and expose it.
7. **Diagnostics in `/api/status`:** `diag: {cpu_temp_c, throttled, fps, infer_ms, latency_ms, serial: "connected|reconnecting|mock", uptime_s}`. Read the temperature and throttling from `vcgencmd` or `/sys` when available, and report null otherwise.
8. **Live tuning:** `GET/POST /api/settings` for lead time, deadband, confidence, max speed and invert, applied without a restart and optionally saved to the settings file.
9. Update `docs/HARDWARE_TEST.md` so tomorrow uses these tools, in order: emulator → jog → camera check → FPS bench → full run.

---

## Part B: the showcase (`site/`, branch `cloud/showcase`)
**Bar:** Active Theory (activetheory.net), in feel. An immersive, cinematic WebGL site with a loader and enter gesture, soft blooms on a near-black stage, and motion driven by scroll and the pointer. It must not read as a template. Design decisions are yours; the references are a starting point, not a spec. Research more if it helps (Awwwards-level studio sites, anime.js docs and examples).

**Identity**
- **Colors: black, white and orange only.** Near-black stage (`#0A0A0A`-ish), off-white text, one orange accent (signal or safety orange). Greys only as tints of those. Put every value as a token in `site/tokens.css`.
- **Type:** a large display face for headlines (a free Google font; choose one with character, serif or grotesk), a clean sans for body text, and a mono for labels and telemetry.
- The name is **COOP: Computer-vision Object Observation & Prediction**. Tagline idea: "COOP keeps an eye on the coop."

**Tech:** no build step, so it deploys as-is on Cloudflare Pages (project `coop-224`, output directory `site`, no build command). Use native ES modules with an import map from `cdn.jsdelivr.net` or `esm.sh`: three.js, anime.js v4 (scrambleText, onScroll, timelines, stagger). If you want an OriginKit component (e.g. Round Carousel), check its license and how it's built. If it's React-only, reimplement the effect in three.js/vanilla instead.

**Structure:** one persistent WebGL scene behind the page that transforms as you scroll (anime.js `onScroll`), chapter by chapter.
1. **Loader and enter gesture:** a dotted progress ring, then an "enter" prompt (a nod to Active Theory's `>>>`).
2. **Intro:** **"COOP" decodes out of noise with anime.js `scrambleText`** (cursor `░▒▓█`), then re-scrambles into "Computer-vision Object Observation & Prediction", then into the tagline. It should feel like a camera acquiring a lock. See Julian Garnier's CodePen `vEyYdXN` for the API; write your own timeline.
3. **01 SEE:** a particle field forms a street scene: people and cars as point clouds, moving.
4. **02 DETECT:** boxes snap onto the figures, with thin leader lines and tiny mono labels (`PERSON #3 · CONF 0.87`).
5. **03 PREDICT:** a velocity vector, and a ghost of the future position with a fading trail. The two real equations (pixel→angle, Kalman lead aim, from `docs/DEVPOST.md`) are typeset as an elegant figure, not a code block.
6. **04 MOVE:** a camera on a pan base rotates to follow; an arc gauge sweeps. **Use a procedural or placeholder camera model and structure the code so a real `.glb` of the actual camera can be dropped in later** (`site/models/`, one constant to switch).
7. **05 BUILD:** an exploded view of the hardware stack with leader-line labels: OV5647 camera, Pi 5, Arduino Uno, TMC2209, NEMA 17, 12 V supply → buck.
8. **06 GALLERY:** a round 3D carousel of build photos and videos (placeholders for now; an easy way to add media).
9. **07 TEAM + links:** GitHub and Devpost; the team as placeholders except David.

Also: word-by-word reveal of body copy on scroll, a chapter scrubber (`03 / 07`), a floating pill nav, custom cursor states on desktop.

**Quality bar (non-negotiable):**
- 60 fps on a mid-range laptop.
- Lazy-load heavy parts.
- Keep the initial load light (target under about 1.5 MB before the first interaction).
- `prefers-reduced-motion` → a static, still-beautiful version.
- Fallback when WebGL is unavailable.
- Works on phones: the touch scroll must feel right, and there is no horizontal overflow.
- Accessible text contrast.
- No console errors.
- `site/README.md` explains how to edit copy, add media, swap in the `.glb` model, and deploy.

## Part C: the dashboard (`web/`, branch `cloud/showcase`), after Part B
Same black/white/orange identity, but it's a tool: calm, legible, fast.
- **Pan-only:** remove the tilt UI. ◀ HOME ▶ plus a big pan gauge as the hero instrument.
- Detection tags become leader-line mono labels; a newly acquired target's label scrambles in.
- A diagnostics strip (from Part A's `diag`), plus E-STOP and ZERO controls. **Keep every endpoint in `docs/API.md` working, and coordinate field names with Part A through `docs/API.md`.**
- Designed states: no camera, Arduino reconnecting, Access session expired, no target.
- Keep `web/mock.js` in sync so the dashboard demos without a backend.

---

## Verification before the report
- `pytest` passes on `cloud/hardware-ready`.
- Run the full app headless against the fake Uno and a fake camera/detector: modes, jog, E-stop and reconnect all work.
- Serve `site/` and `web/` locally and check with a headless browser if one is available (Playwright/Chromium): screenshots at 1440 and 390 px, the console clean, reduced-motion mode. Save screenshots in `docs/screenshots/` on the showcase branch. (These screenshots show the old gimbal dashboard and will be replaced.)

## Morning report
Write `docs/MORNING_REPORT.md` on each branch:
- what was done and what wasn't, and why
- how to preview it: Cloudflare Pages builds a preview URL for every pushed branch, so give the expected branch alias
- anything that needs David's decision
- a step-by-step for tomorrow's hardware session

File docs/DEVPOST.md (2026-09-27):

# Devpost submission: COOPER

Copy each section into the matching Devpost field. This file is kept up to date as the project changes; see "Keeping this current" at the bottom.

**Status legend:** ✏️ = needs your personal input before submitting.

---

## Project name
```
COOPER
```
✏️ _The story behind the name, and a tagline for the video and pitch, are yours to write._

## Elevator pitch
_(max 200 characters, currently 167)_
```
COOPER is a Raspberry Pi 5 dashcam that spots people and cars, predicts where each one is heading, and lights a yellow or red LED before something cuts into your lane.
```

---

## About the project
_(paste everything inside the box. Devpost supports Markdown and LaTeX)_

````markdown
## Inspiration
✏️ _What made you want to build this? A near miss, a car that cut in on you, a pedestrian stepping out from between parked cars, or just wanting to make hardware and AI work together. Write 2–4 sentences in your own words._

## What it does
COOPER is a car-mounted dashcam that warns you before something gets into your lane. A Raspberry Pi 5 with a camera sits behind the windshield, powered by the car. It never moves. It detects **people and vehicles** in real time, **predicts where every one of them is heading** over the next 1.5 seconds, and lights one of two LEDs:

- **Yellow: warning.** Something's predicted path enters your lane within 1.5 s (a car about to cut in, a pedestrian stepping off the curb), or it's closing on you fast.
- **Red: danger.** Something is in your lane right now.
- **Both off: clear.** Red overrides yellow, and the LEDs never flicker.

"Your lane" is a trapezoid of the road in front of the car, which you drag into place from the dashboard once the camera is mounted.

Everything streams live to a web dashboard: the video with every detected object, its predicted path drawn ahead of it, and the lane tinted yellow or red with the risk. A side panel says what COOPER is worried about and why ("car #201 heading into your lane in 0.8 s"), shows both LEDs, lists every object by risk, and logs every change. A diagnostics strip shows the Pi's temperature and throttling, the vision and camera frame rates, inference time and camera-to-LED latency; a tuning panel changes the prediction horizon and time-to-contact thresholds live. It can also beep in step with the LEDs, like a parking sensor: one short beep a second for yellow, rapid high beeps for red (off until you turn it on with the speaker button or the S key, since browsers block audio until the page is touched). Every failure has its own designed state (no camera, connection lost, signed out), all in the same black-white-and-orange identity as the showcase site, down to phone width.

The dashboard is reachable from anywhere over HTTPS at the team's own subdomain, behind an email login.

## How we built it
**Vision (Raspberry Pi 5).** Frames come from a 5 MP OV5647 camera through Picamera2. A YOLO11n model (Ultralytics) detects people, cars, motorcycles, buses and trucks, and ByteTrack gives each object a persistent ID. Everything runs on the Pi 5's CPU. Capture runs on its own thread and the vision loop always takes the newest frame, dropping the ones that arrived during inference instead of queueing them, and each frame carries its capture timestamp so every filter is updated at the moment the photo was taken.

**Prediction in image space.** The camera rides with the car, so what matters for a collision is motion *relative to the camera*, which is exactly what the image shows. For each tracked object COOPER filters the bottom-centre of its box \\( (u, v) \\), where it touches the road, and the box height \\( h \\), which is proportional to 1/distance. A constant-velocity **Kalman filter** per object tracks \\( \mathbf{x} = [u, v, h, \dot u, \dot v, \dot h] \\) with

$$F = \begin{bmatrix} I & \Delta t\, I \\ 0 & I \end{bmatrix}, \quad H = \begin{bmatrix} I & 0 \end{bmatrix}, \quad Q_i = \sigma_i^2 \begin{bmatrix} \Delta t^4/4 & \Delta t^3/2 \\ \Delta t^3/2 & \Delta t^2 \end{bmatrix}, \quad R = 3^2 I$$

(\\( \sigma = 400 \\) px/s² for \\( u, v \\), 150 px/s² for \\( h \\)). Every matrix is block-diagonal per axis, so the six-state filter factors exactly into three two-state filters: a few dozen scalar operations per object per frame (a test checks it against the full 6×6 form).

**Risk.** Each object's path is sampled every 0.1 s out to 1.5 s. **Danger** when at least 20 % of its bottom edge is inside the lane now; **warning** when a predicted bottom edge enters the lane within the horizon, or when its **time to contact from scale growth**

$$\tau = \frac{h}{\dot h} = \frac{Z}{-\dot Z}$$

drops below 2.0 s while it's in the lane's corridor (released above 2.5 s). Hysteresis stops flicker: a level lights after 2 frames in a row and holds 0.5 s after its condition ends. The whole derivation is in `docs/MATH.md` in the repo.

**LEDs.** Two LEDs on the Pi's GPIO, driven with gpiozero, written only when they change. On any machine that isn't a Pi they're mocked automatically, so the whole app runs on a laptop.

**Streaming.** A Flask server on the Pi serves an MJPEG video stream and a JSON status API to a lightweight HTML/JS dashboard that any device on the network can open.

**Dashboard.** No build step: plain HTML, CSS and JS, with every color and spacing value in one `tokens.css` file. Everything drawn over the video (the lane, boxes and predicted paths) is on one `<canvas>` that redraws only when a new frame arrives, the feed is resized or a lane corner is dragged, so the dashboard stays light even on a phone. Dragging the lane's corners and pressing Apply updates the risk rules on the Pi on the very next frame; "Apply and save" writes it to the settings file. Without a backend it plays a mock of the same road with the same lane rules, so the UI is demoable anywhere.

**Dev without hardware.** `tools/rehearsal.py` runs the real app on a synthetic road seen through a fixed dashcam: a car in the next lane, a car cutting in, a pedestrian crossing and the lead car braking hard, drawn with the pinhole ground-plane model so box sizes scale exactly like on the real camera. Its detector reads the boxes back out of the rendered pixels, so everything from the capture thread to the dashboard is the real code. `--timeline` runs a loop offline and prints every risk and LED change.

**Settings without editing code.** Every tunable (camera, model, filter noise, lane, horizon, TTC thresholds, hysteresis, LED pins) can be overridden in a `cooper.toml` file, read with Python's built-in `tomllib`. Unknown keys and wrong types stop COOPER at startup with the key named and a "did you mean" suggestion. The lane and the risk thresholds can also be changed live from the dashboard, checked against the whole configuration (so the TTC warn threshold can't end up above its release threshold), and written back to `cooper.toml` with its comments preserved.

**Hardware.** A Raspberry Pi 5, the OV5647 camera and two LEDs with resistors, powered from the car through a USB-C PD charger. Diego Avila designed and built the mount and enclosure (Fusion 360) and wired all the hardware together.

**Deployment.** A systemd unit runs COOPER as soon as the car powers the Pi and restarts it if it crashes. A second unit runs a **Cloudflare Tunnel**, which publishes the dashboard at an HTTPS subdomain through an outbound-only connection, so it works behind any NAT (a phone hotspot included) with no port forwarding. **Cloudflare Access** sits in front: only approved email addresses (one-time PIN login) can see the camera.

**Showcase site.** The public page opens straight on the hero, no loading screen: the COOPER wordmark is a single WebGL quad whose letters come into focus under a lens that follows the pointer (it sweeps by itself when there's no pointer), over two calls to action, a keycap button that presses down and springs back and a GitHub button with a scanline sweep and a glitch on hover. The story then plays out in scroll-driven chapters in one persistent three.js scene: a street of people and cars made of ~20,000 points. anime.js v4 drives the intro, the scroll timelines and the labels. The Build chapter ends on a tile sheet of the tech stack whose hovered tile and its four neighbours lift and glow; it's plain HTML and CSS underneath, so it reads the same without JavaScript. The dashcam in it is our real CAD: a Blender script turns the Fusion 360 assembly into a 281 KB glTF with one node per part, so the Build chapter pulls apart the actual lid, LEDs, Pi, camera mount and camera module, and in the Warn chapter the model's two LEDs light with the scene's warning level. It has no build step (native ES modules, vendored libraries, self-hosted fonts), a still version for reduced motion, and a 2D-canvas fallback for browsers without WebGL.

**Team.** David Hernandez built the backend: vision, tracking and prediction. Diego Avila did the CAD (Fusion 360) and the hardware, and assembled and wired the finished project. Diego Tabares did the presentation and the pitch, and elements of the website's design.

**Testing.** A pytest suite covers the Kalman filter (against the full matrix form, the occlusion gate, time to contact), every risk rule and the hysteresis, the LEDs (gpio vs mock on a fake board, only writing on a change, releasing a half-claimed pin), the settings file, live settings and the lane API, the Flask API, diagnostics and the capture thread. It also runs the rehearsal's whole 20-second loop and checks that the cut-in, the pedestrian and the braking car each warn before they're danger, that the car in the next lane never lights an LED, and that no LED state lasts under a quarter second. GitHub Actions runs it on every push and pull request without installing PyTorch, Ultralytics or the Pi camera stack, which also proves the tests never load them.

## Challenges we ran into
- **Running AI with no accelerator.** All inference runs on the Pi 5's CPU, so we used the smallest YOLO model at a reduced input size and kept everything after it tiny: prediction and risk for ten objects take about a fifth of a millisecond on a laptop.
- **The camera moves with the car.** Instead of estimating our own motion, COOPER works on motion relative to the camera, in the image: an object's bottom edge says where it meets the road, and its box height says how close it is. That's exactly what decides a collision.
- **Jitter that looks like danger.** Time to contact from scale growth, \\( h / \dot h \\), is very sensitive: a car that isn't moving at all, with a few pixels of detector jitter, produced false "contact in under 2 s" readings in 20 of 50 simulated runs. COOPER now counts it only when the growth rate is more than two of its own standard deviations above zero (from the Kalman filter's covariance), which cut false alarms to almost none while a real approach still fires every time.
- **Occlusion put the ground under the wrong car.** A pedestrian walking behind a car in the next lane is seen only above that car's roof, so their box's bottom edge, which we treat as where they stand, jumped onto the roof and their predicted path swung out of the lane, making the warning drop out mid-crossing. The fix is Kalman innovation gating: measurements far outside the filter's prediction are rejected and it coasts. The subtle part: the gate widens while coasting, so on its own the ground point eventually accepted the bad value; gating it together with the box height (they come from the same edge) keeps it coasting until the person reappears.
- **A car far ahead is above the lane.** The lane only reaches about 14 m, so a braking car further out is outside it, and a time-to-contact rule limited to the lane would fire only once it was already there. The TTC corridor extends the lane's side edges towards the vanishing point.
- **A frame-rate readout that lied.** The dashboard showed 64 fps from a 31 fps camera: averaging \\( 1/\Delta t \\) overshoots whenever frames arrive unevenly. Inverting the average interval fixed it.
- **A dashboard that doesn't lie.** A request-time timestamp always looks fresh, and the Pi's and a phone's clocks disagree. Staleness is detected from a per-frame counter timed on the client's own clock, and an expired Cloudflare Access session is told apart from a dead network by reading the login redirect instead of the opaque CORS error.
- **A cinematic site that still runs on a judge's laptop.** The showcase animates ~20,000 points, so every person's walk cycle and every car's motion is computed in the vertex shader from a handful of uniforms: one draw call, and the CPU never touches the points.
- **A 242,000-triangle CAD model on a laptop GPU.** The Fusion 360 assembly carries every resistor on the Pi. A plain decimation tore the case's flat faces and turned the Ethernet port into spikes, so the Blender script first dissolves coplanar faces (flat stays flat, and the case needs no further cuts), then treats the Pi board per component: the board and USB ports are decimated, chips and box-shaped connectors become boxes, the GPIO header is rebuilt as 40 pins, and tiny parts are dropped. The lens keeps its full detail. The result is 24,000 triangles and 281 KB, with no normals (the scene is unlit) and the second LED as an instance of the first.
- ✏️ _Add anything that actually went wrong during the hackathon (wiring, power in the car, mounting, calibration, time pressure). Judges like real stories._

## Accomplishments that we're proud of
- The full loop from camera to AI to prediction to a warning light, on a single Pi 5 with no accelerator
- Warnings that come *before* something is in your lane, not after
- The whole system runs on a laptop without any hardware (webcam or a synthetic road, mocked LEDs), which let software and hardware be built in parallel
- ✏️ _Add your own._

## What we learned
- ✏️ _In your own words: e.g. Kalman filters, time to contact, why the bottom edge of a box matters, real-time constraints on a small computer._

## What's next for COOPER
- Detect the actual lane lines, so "my lane" follows curves instead of being a fixed region
- A buzzer alongside the LEDs, and night vision with an IR camera module
- Read the car's speed over OBD-II to scale the horizon with speed
- A clean shutdown when the ignition turns off, to protect the SD card
- Faster inference with an AI accelerator HAT
````

---

## Built with
_(up to 25 tags, currently 24. Type each one into the tag box)_
```
python
raspberry-pi
yolo
ultralytics
pytorch
ncnn
bytetrack
opencv
numpy
kalman-filter
flask
picamera2
gpiozero
three.js
webgl
anime.js
blender
html
css
javascript
systemd
cloudflare
pytest
github-actions
```

---

## "Try it out" links
```
https://coop.davidhernandez.work
https://github.com/davidhernandez0771/Shellhacks-2026-Project---COOPER
```
Don't list the live dashboard: it's behind Cloudflare Access, so judges would hit a login wall.

---

## Image gallery
_(JPG/PNG/GIF, ≤5 MB each, 3:2 ratio works best, up to 15 images)_

Shot list:
- [ ] Hero photo of COOPER mounted behind the windshield (first image = thumbnail)
- [ ] Dashboard showing a yellow warning: a car's predicted path cutting into the lane
- [ ] Dashboard showing red: something in the lane
- [ ] The two LEDs lit, in the car
- [ ] Inside the build: Pi 5, camera, LEDs and wiring
- [ ] Wiring diagram (see `hardware/README.md`)
- [ ] The team working on it

The screenshots in `docs/screenshots/` are from an earlier dashboard and will be replaced.

## Video demo link
_(YouTube / Vimeo / Facebook / Youku link; embedded at the top of the page)_

Suggested 1–2 minute outline:
1. **(0:00–0:10)** Hook: from the driver's seat, a car starts to drift into the lane and the yellow LED lights before it's there.
2. **(0:10–0:30)** What it is: the one-line pitch, over a shot of COOPER on the windshield.
3. **(0:30–1:10)** Live demo: the dashboard side by side with the road; the predicted paths, yellow for a cut-in, red once it's in the lane, and a car in the next lane that never lights anything.
4. **(1:10–1:40)** How it works: camera → YOLO → Kalman filter per object → lane risk → LEDs, with the time-to-contact idea.
5. **(1:40–2:00)** What's next, and the team.

```
✏️ paste video URL here
```

---

## Keeping this current
Claude sessions in this repo are instructed (via `CLAUDE.md`) to update this file whenever:
- a library, tool, language or hardware part is added or removed → **Built with** and **How we built it**
- a feature is added or changed → **What it does**
- a real problem gets solved → **Challenges**

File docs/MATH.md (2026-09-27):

# The math behind COOPER

How COOPER goes from YOLO boxes to a yellow or red LED. Code: `cooper/predictor.py` (the filter), `cooper/risk.py` (the rules), defaults in `cooper/config.py` (`PredictionConfig`, `RiskConfig`). Every number below is the shipped default; `cooper.example.toml` lists them all.

## 1. Why image space, relative to the camera

COOPER rides in the car, so the camera moves with you. What decides a collision is how things move **relative to the camera**, and that's exactly what the image shows: a car you're closing on grows and slides down the frame whether it's braking or you're accelerating. So there's no world map and no ego-motion estimate: everything is in frame pixels (640×480 by default), origin top-left, x to the right, y down.

Two facts about a pinhole camera looking level down a flat road (height H above it, focal length f in pixels, horizon at the image's middle row c_y) make the rest work. For an object Z metres ahead and X to the side:

$$u = c_x + f\,\frac{X}{Z}, \qquad v = c_y + f\,\frac{H}{Z}, \qquad h = f\,\frac{h_{obj}}{Z}$$

- **The bottom edge of the box is where the object touches the road** (row v). That's the point that has to be inside your lane, not the box's centre: a tall truck in the next lane can overlap your lane in the image with its roof while its wheels are nowhere near it.
- **The box height h is proportional to 1/Z.** So its growth rate tells you how fast the distance is closing without knowing the object's real size (section 5).

The OV5647 with the 3.6 mm lens is about 63° wide at 4:3, so f ≈ 320 / tan(31.5°) ≈ 522 px at 640 wide.

## 2. The Kalman filter (one per tracked object)

ByteTrack gives each object an ID; each ID gets its own constant-velocity Kalman filter.

**State and measurement**

$$\mathbf{x} = [\,u,\; v,\; h,\; \dot u,\; \dot v,\; \dot h\,]^\top \qquad \mathbf{z} = [\,u,\; v,\; h\,]^\top$$

u, v: the bottom-centre of the box (px). h: the box height (px). The dots are their rates (px/s). A box `[x1, y1, x2, y2]` measures z = [(x1 + x2)/2, y2, y2 − y1].

**Model.** With Δt the time between the two frames' capture times:

$$\mathbf{x}_k = F\,\mathbf{x}_{k-1} + \mathbf{w}, \quad F = \begin{bmatrix} I_3 & \Delta t\, I_3 \\ 0 & I_3 \end{bmatrix}, \qquad \mathbf{z}_k = H\,\mathbf{x}_k + \mathbf{n}, \quad H = \begin{bmatrix} I_3 & 0 \end{bmatrix}$$
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

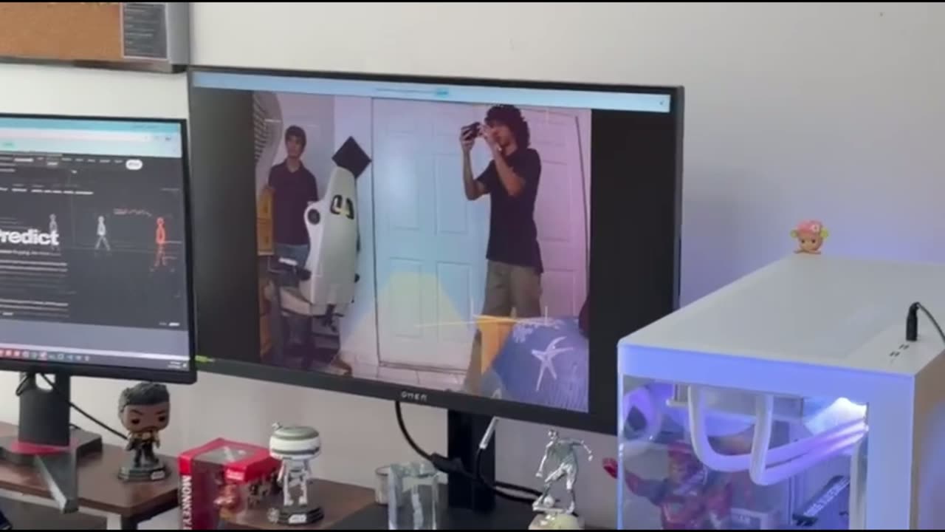
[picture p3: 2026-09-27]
site/media/gallery/demo-poster.jpg

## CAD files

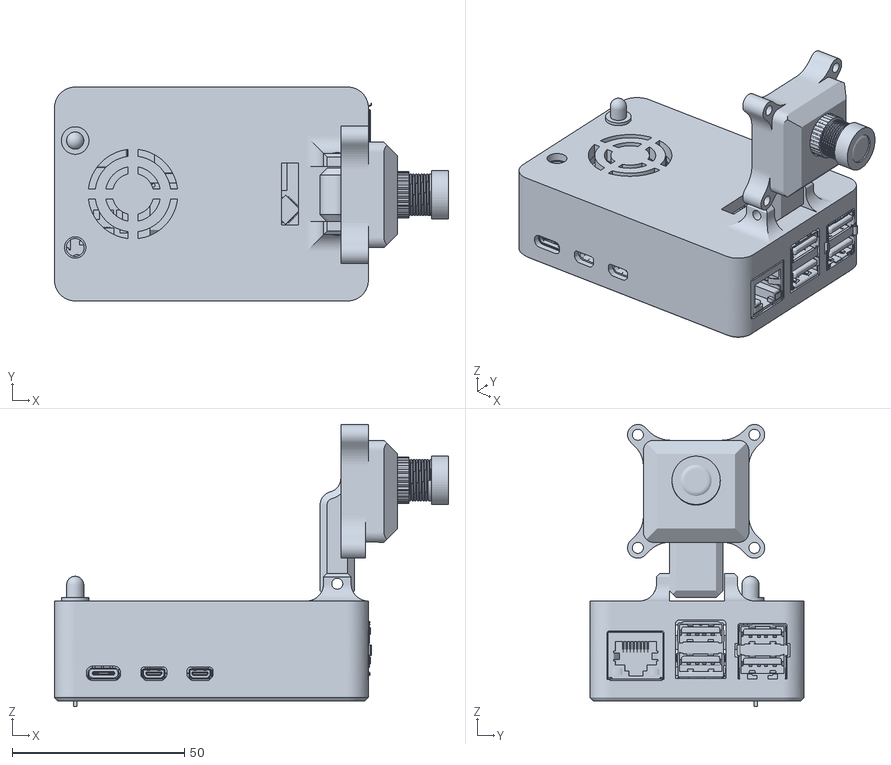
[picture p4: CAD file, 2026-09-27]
hardware/Assembled Pi Case.stl
114.2 x 62.0 x 81.8

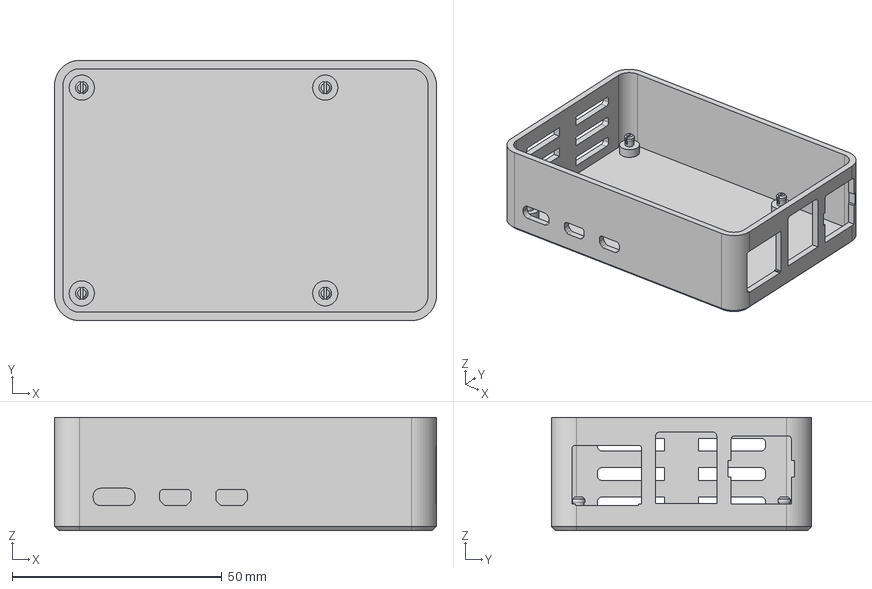
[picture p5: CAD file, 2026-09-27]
hardware/Pi_Case.step
91.0 x 62.0 x 27.0 mm

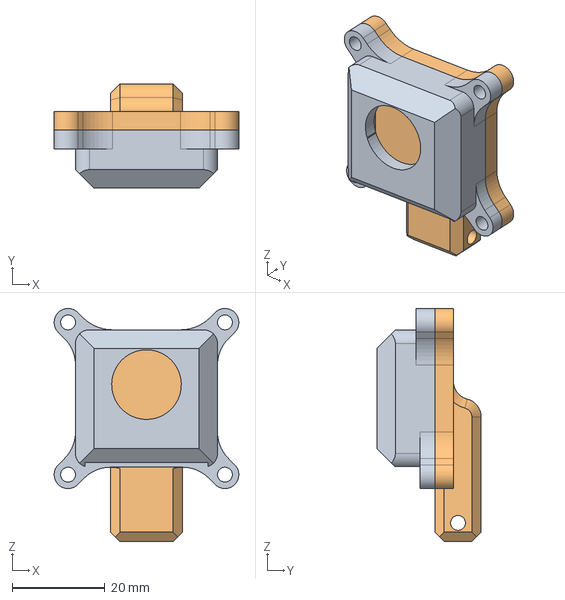
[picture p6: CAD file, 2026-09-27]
hardware/Camera Mount.step
39.8 x 22.5 x 50.2 mm

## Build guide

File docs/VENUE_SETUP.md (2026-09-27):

# COOPER: setting up at the venue (laptop)

Everything is on GitHub. Nothing is left only on the desktop.
Repo: https://github.com/davidhernandez0771/Shellhacks-2026-Project---COOPER

**Live links**
- Main site (the `dev` branch): https://coop.davidhernandez.work
- Design previews (update on every push):
  - https://design-showcase-v2.coop-224.pages.dev
  - https://design-fx.coop-224.pages.dev
  - https://design-sims.coop-224.pages.dev

---

## 1. Install (skip anything the laptop already has)
1. **Git**: https://git-scm.com/download/win
2. **Python 3.13**: python.org → Downloads → Windows → "Windows installer (64-bit)". **Tick "Add python.exe to PATH".**
3. **VS Code**, plus **Claude Code** (log in with your Claude account).
4. Close and reopen the terminal afterwards so it sees Python and Git.

## 2. Get the project (PowerShell, one line at a time)
```
git clone https://github.com/davidhernandez0771/Shellhacks-2026-Project---COOPER C:\dev\COOP
cd C:\dev\COOP
git switch dev
pip install -r requirements.txt
python -m pytest -q
```
`pytest` should end with every test passed and none skipped. The install takes a few minutes (PyTorch is big).

Then create one folder per design lane (each is its own branch, so terminals can't collide):
```
git worktree add C:\dev\COOP-site design/showcase-v2
git worktree add C:\dev\COOP-fx design/fx
git worktree add C:\dev\COOP-sims design/sims
```

## 3. Every time you sit down (on any computer)
Run `git pull` in each folder you'll use:
```
cd C:\dev\COOP;      git pull
cd C:\dev\COOP-site; git pull
cd C:\dev\COOP-fx;   git pull
cd C:\dev\COOP-sims; git pull
```
**Before switching computers, make sure each terminal has pushed**, or the other computer won't see the work.

---

## 4. The terminals
In VS Code, open a new terminal for each one. `cd` into its folder, run `claude`, type `/model` and pick the model shown, then paste its prompt.

### Coordinator: `C:\dev\COOP` · Opus 5.5
Merges each lane after you approve its preview, and keeps an eye on everything.
```
You are the coordinator for COOPER. Read CLAUDE.md, docs/TERMINALS.md and docs/SHOWCASE_V2_PLAN.md (on branch design/showcase-v2: git fetch, then git show origin/design/showcase-v2:docs/SHOWCASE_V2_PLAN.md). Three design lanes work in separate worktrees: C:\dev\COOP-site (design/showcase-v2, the integration branch), C:\dev\COOP-fx (design/fx) and C:\dev\COOP-sims (design/sims). When I say a lane is approved, merge it into design/showcase-v2, resolve conflicts carefully, check the site in the browser (no console errors, 1440 and 390 px), and push. When I approve the whole redesign, merge design/showcase-v2 into dev, run pytest, and push, which makes it live on coop.davidhernandez.work. Never push to main. Confirm with me before every merge.
```

### Lane A (Type & wordmark): `C:\dev\COOP-site` · Opus 5.5
```
Read CLAUDE.md and docs/SHOWCASE_V2_PLAN.md. You are Lane A (Type & wordmark): steps 1, 2, 3 and 7 and your lane's OriginKit components, only in your lane's files. The OriginKit code I copy is saved in C:\dev\COOP-site\site\_originkit\. I'm here: show me each step in the browser and wait for my OK. Start with step 1 (Diego Avila), then the font specimen page. Use the frontend-design and brainstorming skills. Review each step 3 times (correctness, retest in the browser, art-director critique) before showing me. Push to your branch after each approved step, never to dev or main.
```

### Lane B (Cursor & extras): `C:\dev\COOP-fx` · Sonnet 5
```
Read CLAUDE.md and docs/SHOWCASE_V2_PLAN.md. You are Lane B (Cursor & extras): steps 4 and 6 and your lane's OriginKit components (Particle Gimbal loader, Scan Grid and Tactile buttons, Neon/Glow Border, Pixel Trail), only in your lane's files. The OriginKit code I copy is saved in C:\dev\COOP-site\site\_originkit\ (read it from that path). Start with the target cursor and show it to me in the browser before doing the rest, one piece at a time. Use the frontend-design skill. Use tokens.css variables for all fonts and colors (Lane A is changing the font). Review each piece 3 times (correctness, retest in the browser, art-director critique) before showing me. Push to your branch after each approved piece, never to dev or main.
```

### Lane C (Simulations): `C:\dev\COOP-sims` · Opus 5.5
```
Read CLAUDE.md and docs/SHOWCASE_V2_PLAN.md. You are Lane C (Simulations): step 5 and your lane's OriginKit components (Predictive Arc, Dither Reveal, Morphing Glyph Cloud, and ASCII Wave only as an optional prototype), only in your lane's files; never touch js/stage/carousel.js. The OriginKit code I copy is saved in C:\dev\COOP-site\site\_originkit\ (read it from that path). Start with the 1-bit dither look on one chapter and show it to me in the browser before converting the rest, then the iris reveal, then the interactive PREDICT drag. Use the frontend-design and brainstorming skills. Keep 60 fps and the fallbacks. Review each piece 3 times (correctness, retest in the browser, art-director critique) before showing me. Push to your branch after each approved piece, never to dev or main.
```

### Hardware: `C:\dev\COOP` · Sonnet 5 (switch to Opus if stuck)
Use this once the parts are on the desk. It can share the coordinator's folder, but use a separate terminal.
```
Read CLAUDE.md and docs/HARDWARE_TEST.md. Today we bring up the real hardware (Pi 5, OV5647 camera, the yellow and red LEDs, mounted in the car). Walk me through the checklist one step at a time, starting with the laptop rehearsal (python -m tools.rehearsal --timeline), then the camera, the LEDs, the lane calibration and the parked risk test. Wait for me to report each result before moving on, and fix anything that fails. Work on dev, commit small, and tell me before pushing.
```

**If usage runs low:** pause Lane B first (its extras are the least essential), then Lane A. Keep Lane C and Hardware.

---

## 5. OriginKit components (you do this part)
1. Sign in at https://www.originkit.dev (the free plan allows **10 copies a day**).
2. Open each component and set its colors to ours: background `#060606`, text off-white, accent orange.
3. Click **Get this Component**, copy the code, and save it as **`C:\dev\COOP-site\site\_originkit\<name>.txt`** (e.g. `vector-wordmark.txt`). That folder is git-ignored, so the raw code never gets published.
4. Tell that lane's terminal the file is there.

**Today's 10, in order** (the lane is in brackets):
1. Vector Wordmark (A)
2. Particle Gimbal (B, the loader)
3. Dither Reveal (C)
4. Mask Text Reveal (A)
5. Scan Grid Button (B)
6. Tactile Button (B)
7. Neon Border (B)
8. Predictive Arc (C)
9. Morphing Glyph Cloud (C)
10. Interactive Grid (A)

**Tomorrow:** Pixel Trail, Outline Typeflow, Glow Border, and ASCII Wave (only if you like its prototype).

---

## 6. Useful commands
| What | Command (from `C:\dev\COOP`) |
|---|---|
| Tests | `python -m pytest -q` |
| The whole app with no hardware (a synthetic road, mocked LEDs) | `python -m tools.rehearsal`, then open http://localhost:8000 |
| App with the laptop webcam | `python -m cooper.main --source webcam` |
| Preview a design lane locally | `python -m http.server 8124 --directory C:\dev\COOP-site\site`, then open http://localhost:8124 |

## 7. Reminders
- The team is **David Hernandez** (backend, vision, tracking, prediction), **Diego Avila** (CAD and hardware; assembled and wired the finished project) and **Diego Tabares** (presentation, pitch, and elements of website design).
- Still to decide: Diego's GitHub or LinkedIn link, and whether David's team card links SANT (https://github.com/davidhernandez0771/Nebius-X-NVIDIA-Hackathon-Project).
- The hardware checklist is `docs/HARDWARE_TEST.md`; the Devpost copy is `docs/DEVPOST.md`.
- Only merge to `main` once the hardware checklist passes.

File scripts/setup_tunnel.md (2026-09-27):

# Exposing the dashboard with Cloudflare Tunnel

This guide makes the Pi's dashboard reachable at `https://cooper-live.example.com` from anywhere, without opening a port on the venue's router. Cloudflare Access sits in front of it so only approved email addresses can see the camera or change its lane and settings.

**Placeholder:** replace `example.com` with your domain everywhere below.

**Hostnames (decided 2026-09-26):** the live dashboard is `cooper-live.<domain>`, behind Access. The public showcase page (`site/`, see `site/README.md`) keeps `coop.<domain>`. Don't point the tunnel at `coop.`; one hostname can't serve both.

```
browser ──HTTPS──► Cloudflare edge ──(Access: email login)──► tunnel ──► cloudflared on the Pi ──HTTP──► 127.0.0.1:8000 (cooper.service)
```

`cloudflared` makes **outbound** connections to Cloudflare (QUIC on UDP 7844, falling back to HTTP/2 over TCP 7844). Nothing listens on the internet side of the Pi, so it works behind NAT, CGNAT and hotel/venue Wi-Fi.

| Piece | Where it lives |
|---|---|
| Tunnel config | `/etc/cloudflared/coop.yml` (written by the script) |
| Tunnel credentials | `/etc/cloudflared/<tunnel-id>.json` (root-only, `chmod 600`) |
| systemd unit | `/etc/systemd/system/cooper-tunnel.service`, from `scripts/cooper-tunnel.service` |
| Zone login cert | `~/.cloudflared/cert.pem` (only needed to create/route tunnels, not to run one) |

Order matters: **move DNS → create the Access app → then create the tunnel and DNS record.** That way the hostname is never live without a login in front of it.

---

## 1. Move the domain's DNS to Cloudflare

Tunnels need the zone on Cloudflare's nameservers (a "full" setup; the CNAME-only "partial" setup is Business plan only). Registration can stay wherever it is.

1. In the Cloudflare dashboard, **Add a domain** → enter `example.com` → choose the **Free** plan.
2. Cloudflare scans the existing DNS records. **Check the import before continuing**, especially `MX` and `TXT` (SPF/DKIM) records if the domain has email, and any `A`/`CNAME` for an existing website. Anything missing here stops working when the nameservers change.
3. If **DNSSEC** is on at your registrar, turn it off first. Otherwise the old DS record won't match Cloudflare's signatures and the domain stops resolving. You can re-enable it through Cloudflare (DNS → Settings) once the zone is active.
4. At the registrar, replace the nameservers with the two Cloudflare assigned (`<name>.ns.cloudflare.com`).
5. Wait for the zone to show **Active** (usually minutes, sometimes a few hours). Check from the laptop:
   ```powershell
   nslookup -type=NS example.com 1.1.1.1
   ```

Don't create a DNS record for `cooper-live` by hand; section 3 does it.

Stick to a single-level subdomain like `cooper-live.example.com`: Cloudflare's free Universal SSL certificate covers `example.com` and `*.example.com`, but not `live.cooper.example.com`. That's why it's `cooper-live.`, not `live.cooper.`.

## 2. Put Cloudflare Access in front (before the hostname goes live)

1. Open the **Zero Trust** dashboard (from the Cloudflare dashboard sidebar). The first time, pick a team name (it becomes `<team>.cloudflareaccess.com`) and the **Free** plan (up to 50 users). If it asks for billing details, the Free plan is still $0.
2. Login method: **One-time PIN** is enabled by default. Approved users type their email and get a code. Optionally add Google or GitHub under Settings → Authentication.
3. **Access → Applications → Add an application → Self-hosted** (newer dashboards call the menu "Access controls → Applications"):
   - Name: `COOPER`
   - Public hostname: subdomain `cooper-live`, domain `example.com`, **path empty** so it covers `/`, `/video` and `/api/*`
   - Session duration: `24 hours`
4. Add a policy: **Action: Allow**, **Include → Emails** → the team's addresses (add judges' emails on demo day, or use "Emails ending in" for a whole domain).
5. In the application's cookie settings, set **SameSite = Lax** and keep **HttpOnly** on. The write endpoints (`POST /api/lane`, `/api/settings`) are authorized purely by the Access cookie, so `Lax` stops another website from firing cross-site POSTs at COOPER with a logged-in user's cookie.
6. Save.

## 3. Install cloudflared, create the tunnel, run it as a service

On the Pi, from the repo root, as your normal user (the script calls `sudo` where needed, and the login cert must land in your home directory):

```bash
bash scripts/install_tunnel.sh cooper-live.example.com
```

The script is idempotent; re-run it to change the hostname or rebuild the service. It:

1. Installs `cloudflared` from the official GitHub release `.deb` for the Pi's architecture (`arm64` on 64-bit Raspberry Pi OS), if it isn't already installed.
2. Runs `cloudflared tunnel login` once. It prints a URL; open it on the laptop, sign in, and pick the `example.com` zone. This writes `~/.cloudflared/cert.pem`.
3. Creates a named tunnel `coop` (the pre-rename name, kept so an existing Pi reuses its tunnel instead of creating a second one) (`cloudflared tunnel create coop`), or reuses it if it exists.
4. Copies the tunnel credentials to `/etc/cloudflared/` and writes `/etc/cloudflared/coop.yml`:
   ```yaml
   tunnel: <tunnel-id>
   credentials-file: /etc/cloudflared/<tunnel-id>.json
   ingress:
     - hostname: cooper-live.example.com
       service: http://127.0.0.1:8000
     - service: http_status:404
   ```
   The origin is `127.0.0.1`, not `localhost`: Flask binds IPv4 `0.0.0.0`, and `localhost` can resolve to `::1` first. The catch-all `http_status:404` rule is required by cloudflared.
5. Asks you to confirm the Access app from step 2 exists, then creates the proxied DNS record `cooper-live.example.com CNAME <tunnel-id>.cfargotunnel.com` (`cloudflared tunnel route dns`).
6. Installs `cooper-tunnel.service` next to `cooper.service` and starts it.
7. Requests `https://cooper-live.example.com/api/status` without a login and warns loudly if it gets a `200`, which would mean Access isn't in front.

`cooper-tunnel.service` is deliberately independent of `cooper.service`. If COOPER restarts, the tunnel stays up and visitors briefly see a Cloudflare 502 instead of a DNS error; if the tunnel restarts, the camera keeps running and the LAN dashboard still works.

We use our own unit instead of `cloudflared service install` so it has a COOPER-specific name, lives in the repo, and reads an explicit config path. It matches the upstream unit otherwise (`Type=notify`, `--no-autoupdate`, restart on failure).

### Manual equivalent

If you'd rather not run the script:

```bash
# install (arm64 .deb from the official release)
curl -fsSLo /tmp/cloudflared.deb \
  https://github.com/cloudflare/cloudflared/releases/latest/download/cloudflared-linux-arm64.deb
sudo dpkg -i /tmp/cloudflared.deb

cloudflared tunnel login
cloudflared tunnel create coop                 # prints the tunnel ID, writes ~/.cloudflared/<ID>.json
sudo install -d /etc/cloudflared
sudo install -m 600 ~/.cloudflared/<ID>.json /etc/cloudflared/
sudoedit /etc/cloudflared/coop.yml             # contents as above
sudo cloudflared tunnel --config /etc/cloudflared/coop.yml ingress validate
cloudflared tunnel route dns coop cooper-live.example.com
sed -e "s|__CLOUDFLARED__|$(command -v cloudflared)|" -e "s|__CONFIG__|/etc/cloudflared/coop.yml|" \
  scripts/cooper-tunnel.service | sudo tee /etc/systemd/system/cooper-tunnel.service
sudo systemctl daemon-reload && sudo systemctl enable --now cooper-tunnel
```

The `.deb` doesn't auto-update. To track releases through apt instead, add Cloudflare's package repository (see pkg.cloudflare.com) and `apt install cloudflared`; the rest is the same.

## 4. The MJPEG stream through the tunnel

`GET /video` is a single, never-ending `multipart/x-mixed-replace` response. It works through the tunnel as is, and here is why, plus what to check:

- **No buffering.** cloudflared and the Cloudflare edge forward the response body as it arrives. Response buffering is an Enterprise-only setting and is off by default, so each JPEG part reaches the browser as soon as the Pi writes it.
- **Timeouts.** Cloudflare's 100 s limit (error 524) is for the origin to *start* responding. `/video` sends its headers with the first frame, then keeps streaming, so long sessions are fine as long as frames keep coming.
- **Caching.** Cloudflare never caches the stream or `/api/*` JSON. It *does* cache `.js`/`.css` by extension, which makes dashboard edits look like they didn't deploy. Add a **Cache Rule**: hostname equals `cooper-live.example.com` → **Bypass cache**. Alternatively, purge the cache after changing `web/`.
- **Auth.** The dashboard loads `/video` with a same-origin `<img>`, so the browser sends the Access cookie automatically. Nothing in the app needs to know about Access.
- **Bandwidth.** Each viewer gets its own stream from the Pi (the edge doesn't fan out). A 640×480 JPEG at quality 70 is roughly 25–40 KB, so at 15 fps that's about 3–5 Mbit/s of **upload** per open tab. On weak venue Wi-Fi, lower `StreamConfig.jpeg_quality` in `cooper/config.py` or keep the number of open tabs small.

Check it end to end:

```bash
# on the Pi: the origin streams (expect a few hundred KB after 2 s)
curl -sN --max-time 2 http://127.0.0.1:8000/video -o /dev/null -w '%{size_download} bytes\n'

# anywhere: no login -> Access redirect (302), never 200
curl -s -o /dev/null -w '%{http_code}\n' https://cooper-live.example.com/video
```

Then open `https://cooper-live.example.com` in a browser, sign in with an approved email, and confirm the feed moves. In DevTools → Network, `/video` should be a single pending request whose size keeps growing.

To test the stream through Access from a terminal (install cloudflared on the laptop with `winget install Cloudflare.cloudflared`):

```powershell
cloudflared access login https://cooper-live.example.com
cloudflared access curl https://cooper-live.example.com/video --max-time 5 -s -o NUL -w '%{size_download} bytes\n'
```

## 5. Everyday commands

```bash
systemctl status cooper-tunnel            # is it connected?
journalctl -u cooper-tunnel -f            # live logs ("Registered tunnel connection" x4 = healthy)
sudo systemctl restart cooper-tunnel      # after editing /etc/cloudflared/coop.yml
cloudflared tunnel info coop            # active connections and which edge locations
```

Uninstall:

```bash
sudo systemctl disable --now cooper-tunnel
sudo rm /etc/systemd/system/cooper-tunnel.service
cloudflared tunnel cleanup coop && cloudflared tunnel delete coop
# then delete the cooper-live CNAME in the Cloudflare DNS tab, and the Access application
```

## Troubleshooting

| Symptom | Cause / fix |
|---|---|
| Cloudflare **502 Bad Gateway** | The tunnel is up but COOPER isn't answering on port 8000. `systemctl status cooper`, `curl http://127.0.0.1:8000/api/status`. |
| Cloudflare **error 1033** | No tunnel connected for this hostname. `journalctl -u cooper-tunnel -e`. |
| Logs loop on `failed to dial to edge with quic` | The network blocks UDP 7844. cloudflared normally falls back to HTTP/2 on its own; to skip the QUIC attempts, add `protocol: http2` at the top level of `/etc/cloudflared/coop.yml` and restart. |
| Status updates but the video freezes or stutters | Upload bandwidth (see section 4). Close extra tabs, lower `jpeg_quality`. |
| Dashboard changes don't show up | Edge cache on `.js`/`.css`. Add the bypass Cache Rule, or purge. |
| Dashboard stops updating after many hours | The Access session expired. `/api/*` fetches are now redirected to the login page, which the browser blocks as cross-origin. Reload the page to sign in again. |
| `NXDOMAIN` / "server not found" | Zone not Active yet, or `route dns` never ran. Check the DNS tab for a `cooper-live` CNAME to `<id>.cfargotunnel.com`. |
| SSL error | You used a two-level subdomain (`a.b.example.com`). Use `cooper-live.example.com`. |

## Note: the LAN still bypasses Access

`cooper.service` binds `0.0.0.0:8000`, so anyone on the same network can open `http://<pi>.local:8000` without logging in. That's useful during the demo (it keeps working if the venue's internet drops), but if the camera should *only* be reachable through Access, set `StreamConfig.host = "127.0.0.1"` in `cooper/config.py`; the tunnel only needs loopback.

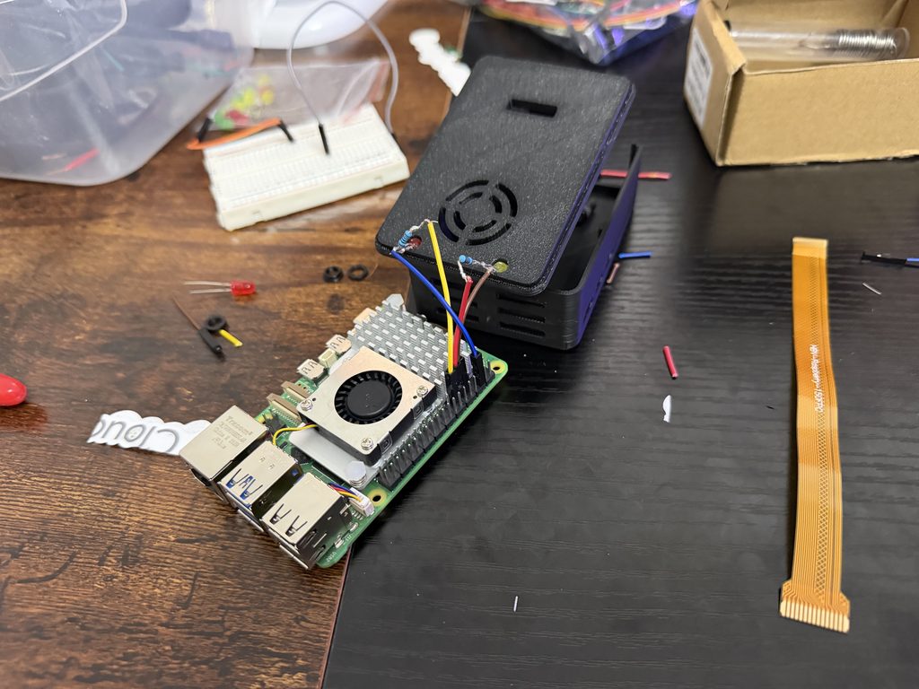
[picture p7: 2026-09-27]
site/media/gallery/09-wiring-gpio-card.jpg

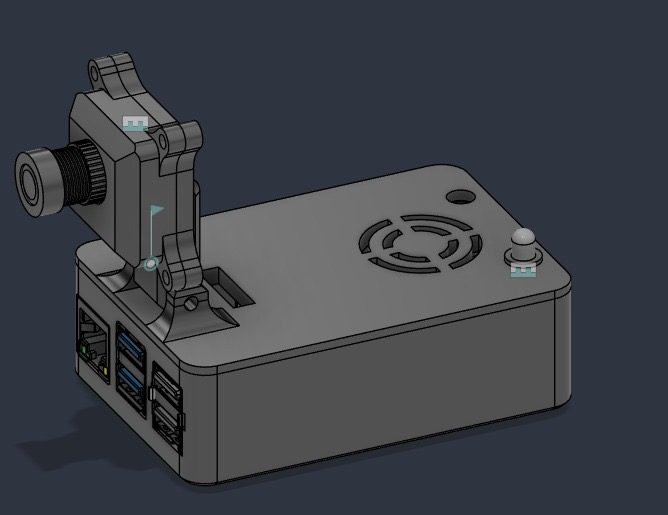
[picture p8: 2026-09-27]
site/media/gallery/01-cad-assembly.jpg

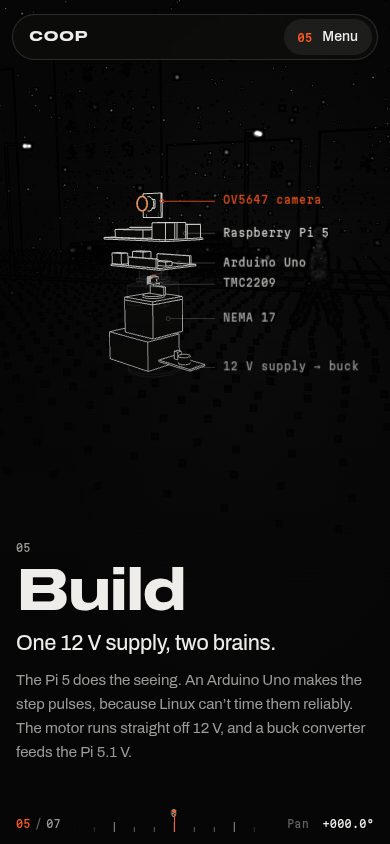
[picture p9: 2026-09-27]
docs/screenshots/site-390-08-build.jpg

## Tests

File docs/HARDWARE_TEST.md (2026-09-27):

# First hardware bring-up checklist

Work through this top to bottom on the real Pi 5, camera and LEDs. Each step has a checkbox and the result to expect; if you get something else, stop and write it in the findings log at the bottom before moving on. Commands run on the Pi from the repo root (with `source .venv/bin/activate`) unless marked **laptop**.

**The order is deliberate: rehearsal → camera → FPS bench → LEDs → lane calibration → risk test.** Each stage only adds one new thing that can go wrong.

**Status as of 2026-09-26: nothing below has run on real hardware yet.** Every step is tagged **`[never run]`**. When a step passes on the real thing, change its tag to **`[ok YYYY-MM-DD]`** in the same commit as any fix it needed.

What *has* been verified, off hardware only:
- The pytest suite (filter, risk rules, LEDs against a fake board, settings, lane API, Flask API, diagnostics, capture thread, and the rehearsal's full 20 s loop). It runs with only the minimal CI dependencies.
- `python -m tools.rehearsal` serving the dashboard with every risk state; `python -m cooper.main --source webcam` on a laptop (YOLO11n + ByteTrack at about 14 ms per frame, LEDs mocked).
- Nothing has touched the Pi camera, GPIO, systemd or Cloudflare.

**Safety rules for the whole session**
- **Do every car test parked first.** The driver never looks at or touches the dashboard while driving; a passenger does, or nobody.
- COOPER is a warning light, not a safety system. Drive as if it weren't there.
- Wire the LEDs with the Pi powered off, and never without their resistors.

---

## 0. Prerequisites

- [ ] **The Pi has a commit that includes the dashcam refactor** (`refactor/cooper-dashcam` or later). `[never run]`
  **Expect:** `ls cooper/` shows `risk.py leds.py predictor.py`, and `cooper.example.toml` exists.
- [ ] **CI is green on the commit you're testing.** `[never run]` **Expect:** the `tests` workflow passes on GitHub for that commit.
- [ ] **Bring:** the car charger and cable, two LEDs, two 330 Ω resistors, jumper wires, a multimeter, and a phone on mobile data (for the tunnel test and as a hotspot). `[never run]`

## 1. Rehearsal (laptop, no hardware)

This proves the software end to end before anything is wired.

- [ ] **Tests:** `python -m pytest -q`. `[never run]` **Expect:** all pass, none skipped.
- [ ] **One loop's timeline:** `python -m tools.rehearsal --timeline`. `[never run]`
  **Expect** (20 s loop, times ±0.1 s):
  - clear until the cut-in: yellow at ~4.7 s, red at ~5.7 s, clear at ~8.5 s;
  - the pedestrian: yellow at ~10.6 s, red at ~12.1 s, clear at ~13.4 s;
  - the braking lead car: yellow at ~18.3 s, red at ~19.0 s;
  - never a line mentioning `#4xx` (the car in the next lane).
- [ ] **Dashboard:** `python -m tools.rehearsal`, open `http://localhost:8000`. `[never run]`
  **Expect:** predicted paths on every object, the lane tinting yellow and red in step with the LED lamps, and **LEDs · mock** in the risk panel.

## 2. Pi software

- [ ] **Clone and set up:** `bash scripts/setup_pi.sh`. `[never run]`
  **Expect:** the script ends with `imports OK` (picamera2, gpiozero and ultralytics all import).
- [ ] **Download the model once, while online.** `yolo11n.pt` is gitignored, so the first run downloads it. `[never run]`
  Run `python -c "from ultralytics import YOLO; YOLO('yolo11n.pt')"`.
  **Expect:** `yolo11n.pt` (≈5.4 MB) appears in the repo root. After this, COOPER starts without internet access.
- [ ] **Settings file:** `cp cooper.example.toml cooper.toml`, and delete the lines you won't change. `[never run]`
  **Expect:** `python -c "from cooper.settings import load_config; print(load_config().leds)"` prints your pins. A typo fails loudly with the key named.
- [ ] **Diagnostics read the Pi:** `python -c "from cooper.diag import read_cpu_temp_c, read_throttled; print(read_cpu_temp_c(), hex(read_throttled()))"`. `[never run]`
  **Expect:** a temperature around 40–60 and `0x0`. (`None` means the path or `vcgencmd` isn't where `cooper/diag.py` looks; note it in the log.)

## 3. Camera

- [ ] **Camera detected:** `rpicam-hello --list-cameras`. `[never run]`
  **Expect:** one camera listed as `ov5647`.
  If there's none, check the 22-pin end is in a Pi 5 CAM port with the contacts facing the right way. If auto-detect still fails, add `dtoverlay=ov5647,cam0` (or `cam1`, depending on the port) to `/boot/firmware/config.txt` and reboot.
- [ ] **COOPER's camera path:** `python -m tools.camera_check --source picamera`, then copy `camera_check.jpg` to the laptop. `[never run]`
  **Expect:**
  - `Resolution: 640x480 (configured 640x480)` and `Delivered: ~30 fps`.
  - Skin tones look normal, not blue. If they're blue, the red/blue channels are swapped; see the `RGB888` comment in `cooper/camera.py`.
- [ ] **Orientation matches the world.** Take the still with text held up and something on the camera's right. `[never run]`
  **Expect:** the text reads normally (not mirrored or upside down), and something on the camera's right appears on the right of the image. If not, fix it before calibrating the lane: a Picamera2 `Transform` in `camera.py`, or how the camera is mounted.

## 4. FPS bench

- [ ] **Export NCNN models** (once, online): `python -m tools.bench_fps --export`. `[never run]`
  **Expect:** `yolo11n_imgsz256_ncnn_model/`, `…320…`, `…416…` folders in the repo root.
- [ ] **Benchmark:** `python -m tools.bench_fps`. Paste the printed table into the findings log. `[never run]`
  **Expect:** NCNN clearly faster than PyTorch at each size. The goal is ≥10 fps at 320.
- [ ] **Use the winner:** in `cooper.toml` under `[detector]`, set `model = "yolo11n_imgsz320_ncnn_model"` and `imgsz = 320` (an NCNN model must run at its export size). `[never run]`

## 5. LEDs

Wire them with the Pi **off**, as in `hardware/README.md`: GPIO → 330 Ω → LED long leg, short leg → GND. The default pins (BCM 17 yellow, 27 red) are placeholders: if you wire others, set them under `[leds]` in `cooper.toml` first.

- [ ] **Each LED lights on its own**, with COOPER not running (it would hold the pins): `[never run]`
  ```bash
  python - <<'EOF'
  import time
  from cooper.leds import Leds
  from cooper.settings import load_config
  leds = Leds(load_config().leds)
  print("mode:", leds.mode, "|", leds.mode_reason)
  for level in ("warning", "danger", "clear"):
      print(level); leds.set(level); time.sleep(2)
  leds.close()
  EOF
  ```
  **Expect:** `mode: gpio | GPIO17 yellow, GPIO27 red`, then yellow alone for 2 s, red alone for 2 s, both off. If it says `mock`, the reason is printed (not a Pi, gpiozero or lgpio missing, pin busy). If the colours are swapped, swap the pins in `cooper.toml`. If one never lights, the LED is probably in backwards (long leg towards the resistor).
- [ ] **Visible in daylight** from the driver's seat, at a glance. `[never run]` If not, drop the resistors to 150 Ω or use brighter LEDs.
- [ ] **COOPER drives them:** `python -m cooper.main --source picamera`. `[never run]`
  **Expect:** the log says `LEDs: gpio (GPIO17 yellow, GPIO27 red)`, and the dashboard's risk panel and diagnostics say **GPIO**. Walk in front of the camera (on the bench, the "lane" is the bottom middle of the frame): red lights when you're in it, then goes off about ½ s after you leave. Ctrl+C turns both off.

## 6. Mount and calibrate the lane (parked)

- [ ] **Mount** the camera centred behind the windshield, level, looking straight down the road; power the Pi from the car charger. `[never run]`
  **Expect:** it boots; the dashboard's Power reading is **OK** (`throttled: 0`). Not OK: the charger can't deliver 5 A.
- [ ] **Calibrate:** park on a straight, flat road or a car park with lane markings. Open the dashboard from a phone on the same network (or the tunnel), **Edit lane**, and drag the corners: the bottom corners on your lane's edges at the bottom of the frame (or your car's width if the markings are wider), the top corners on the same lane about 15 m ahead. **Apply and save.** `[never run]`
  **Expect:** a `Lane changed and saved` event, and `[risk] lane = [...]` in `cooper.toml`. Restart COOPER: the lane is still there.

## 7. Risk test (parked, a helper walking)

The car stays parked with the engine off for all of these; a helper walks, you watch the LEDs and the dashboard.

- [ ] **Crossing in front:** the helper walks across in front of the car, about 8–10 m ahead, at a normal pace. `[never run]`
  **Expect:** yellow while they're still outside the lane and heading in ("person #… heading into your lane in …"), red while they're in it, then off about ½ s after they leave it. Their predicted path points across the lane on the dashboard.
- [ ] **Walking alongside, in the next lane:** the helper walks towards the car along the next lane. `[never run]`
  **Expect:** nothing lights (they're neither in nor heading into your lane). If yellow lights, the lane is too wide: narrow it.
- [ ] **Approaching head-on:** the helper walks straight towards the car down the middle of the lane, starting beyond its far end (~20 m). `[never run]`
  **Expect:** yellow before they reach the lane's top edge (path or TTC; the reason says which), red once they're in it.
- [ ] **Standing still in the lane:** the helper stands in the lane for 10 s. `[never run]`
  **Expect:** a steady red, no flicker. Standing still just outside the lane: nothing, and no stray yellow from box jitter.
- [ ] **Tune if needed**, live from the dashboard's Tuning panel: a longer `horizon_s` warns earlier (and more often), a longer `hold_s` holds the LEDs longer. Keep good values with **Apply and save**. Record what you changed here. `[never run]`

## 8. On the road (a passenger watches, the driver drives)

- [ ] **Following traffic:** drive normally behind other cars. `[never run]`
  **Expect:** clear most of the time; yellow when the car ahead brakes hard or a car merges in front; the LEDs don't flicker. Note every surprising light in the findings log with the time; the dashboard's event log has the reason.
- [ ] **FPS and thermals after 10 minutes:** `curl -s localhost:8000/api/status | python3 -c "import json,sys; print(json.load(sys.stdin)['diag'])"`. `[never run]`
  **Expect:** `fps` close to the bench number, `capture_fps` ≈ 30, `cpu_temp_c` below about 80 °C, `throttled: 0`. Non-zero: see the bit list in `docs/API.md` (`0x1`/`0x10000` = under-voltage: the charger).

## 9. systemd service

- [ ] **Install:** `sudo bash scripts/install_service.sh`. `[never run]`
  **Expect:** `systemctl status cooper` shows `active (running)`, and `journalctl -u cooper -f` shows the same startup lines as a manual run, including `Settings: /home/…/cooper.toml` and `LEDs: gpio`.
- [ ] **Starts with the car:** turn the ignition off and on (the Pi loses and regains power). `[never run]` **Expect:** the dashboard is live within about 60 s, the LEDs work, and the saved lane is back.
- [ ] **Restarts after a crash:** `sudo systemctl kill -s SIGKILL cooper`. `[never run]` **Expect:** back to `active (running)` within about 3 s, and `diag.uptime_s` restarts from ~0.

## 10. Cloudflare Tunnel and Access

Follow `scripts/setup_tunnel.md`. DNS must already be on Cloudflare and the Access app created (steps 1–2) before the installer runs. In the car, the Pi needs internet: a phone hotspot works.

- [ ] **Install the tunnel:** `bash scripts/install_tunnel.sh cooper-live.example.com` (your domain). `[never run]`
  **Expect:**
  - cloudflared installs as arm64.
  - `ingress validate` passes.
  - The final check prints `OK: unauthenticated requests get HTTP 302`.
  - `journalctl -u cooper-tunnel` shows 4× `Registered tunnel connection`.
- [ ] **Blocked without a login:** from the laptop, `curl -s -o /dev/null -w "%{http_code}" https://cooper-live.example.com/video`. `[never run]` **Expect:** `302`, never `200`. Also try `-X POST …/api/lane`: `302`.
- [ ] **Unapproved email is refused:** on the login page, try an address that isn't in the policy. `[never run]` **Expect:** no one-time PIN arrives, or access is denied.
- [ ] **Approved email gets in, from a phone on mobile data.** `[never run]`
  **Expect:** the dashboard loads over HTTPS, `/video` plays smoothly, and the risk panel follows the LEDs.
- [ ] **Stream is unbuffered:** in DevTools → Network, open `/video`. `[never run]` **Expect:** one long-running request whose transferred size grows steadily; no stall and no 524 error after 100 s.

---

## Findings log

| Date | Step | What happened | Fix / commit |
|---|---|---|---|
| | | | |

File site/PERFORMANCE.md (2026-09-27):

# Site performance

Measured with `tools/site_perf/`: `serve.mjs` fronts `site/` the way Cloudflare Pages
does (brotli, `Cache-Control: no-cache`, ETags/304s), and `measure.mjs` drives headless
Chromium at 1440×900, 4× CPU throttle, DevTools "Fast 4G", cold cache, median of 3 runs.
Headless WebGL runs on SwiftShader (software), so **scroll FPS here is only meaningful
relative to itself** (before vs. after, DPR2 vs. DPR1, gl vs. `?nogl`) — not as an
absolute number a real GPU would hit.

Baseline was captured from `origin/dev`'s `site/` (before any fix in this doc), served
on its own port so later edits on this branch don't move the baseline.

**Since these measurements** the site changed around the numbers below, which have not been
re-measured yet:

- **The loader/Enter gate (`js/gate.js`) is gone.** The page boots straight into the hero
  (fonts → anime.js → three.js + scene → intro, `main.js`), so "Loader end" in the tables
  below measured a screen that no longer exists, and fix 1 is kept only as history (it's
  where performance rule 6 comes from).
- **The hero title is `js/fx/vector-wordmark.js`**, a second, small WebGL canvas (one quad,
  DPR capped at 2). Its `requestAnimationFrame` loop runs only while it's on screen and the
  tab is visible (IntersectionObserver + `visibilitychange`); under reduced motion it
  draws one static frame and runs no loop.
- **The hero CTAs (`js/fx/tactile-button.js`, `js/fx/scan-grid-button.js`) and the Build
  chapter's stack grid (`js/fx/interactive-grid.js`)** do no per-frame work: they react to
  pointer/focus events, and animate only `transform`, `opacity` and `filter` (the scan-grid
  button with the Web Animations API, the others with CSS transitions).

The next measurement should replace "Loader end" with time to first hero frame, and check
scroll FPS with the wordmark on screen (two WebGL contexts at once) as well as past it.

## Baseline (origin/dev, before fixes)

| Config | Loader end | Transfer | Requests | Scroll FPS | Frame p50/p95 | Task ms/frame | Long tasks (load) |
|---|---|---|---|---|---|---|---|
| WebGL, DPR 2 | 2.8 s | 441 KB | 24 | 8.4 | 100 / 217 ms | 117 | 3 (673 ms) |
| WebGL, DPR 1 | 2.4 s | 441 KB | 24 | 14.2 | 67 / 133 ms | 71 | 3 (333 ms) |
| `?nogl`, DPR 2 | 2.3 s | 441 KB | 24 | 17.3 | 50 / 133 ms | 58 | 2 (194 ms) |
| `?nogl`, DPR 1 | 2.1 s | 441 KB | 24 | 32.8 | 33 / 50 ms | 28 | 2 (123 ms) |

Largest transferred files (unchanged across configs, same HTML/JS/fonts/vendor):

| File | Size |
|---|---|
| `vendor/three.module.min.js` | 172.1 KB |
| `fonts/archivo-var.woff2` | 88.2 KB |
| `vendor/anime.esm.min.js` | 38.9 KB |
| `fonts/martian-mono-var.woff2` | 37.8 KB |
| `fonts/stix-two-text-latin-400-italic.woff2` | 18.0 KB |
| `fonts/stix-two-text-latin-400-normal.woff2` | 16.6 KB |

### Reading the numbers

- **Loader end** (~2.1–2.8 s here) is dominated by network + module parse + shader warm-up
  under throttle, not by anything frame-rate dependent in this headless run. But
  `js/gate.js`'s ring converges a fixed *fraction per animation frame*
  (`shown += (target - shown) * 0.12`) instead of a fixed fraction per elapsed *time* — on
  a real machine where the main thread is busy (importing three.js, compiling shaders,
  laying out fonts) and `requestAnimationFrame` fires far less often than 60 Hz, the ring's
  wall-clock convergence time stretches by the same factor the frame rate drops by. That's
  the reported "~10 s loader" on MacBooks: not slower loading, a slower-appearing *ring*.
  Fixed below (time-based convergence, independent of frame rate).
- **WebGL DPR 2 → DPR 1** roughly halves task time per frame (117 ms → 71 ms): the
  full-screen WebGL draw (fragment shading, MSAA resolve) scales with pixel count, and DPR 2
  is 4× the pixels of DPR 1.
- **`?nogl` is still slow** (58 ms/frame at DPR 2, only 2× faster than WebGL, not 10×): the
  2D HUD overlay (`js/stage/overlay.js`) — every visible chapter does a full canvas reset
  and redraws all brackets/leader-lines/lane markings every animation frame at up to DPR 2 —
  and the no-WebGL scene fallback (`js/stage/fallback2d.js`, also DPR-capped at 2) are
  themselves expensive 2D-canvas fill-rate work, independent of WebGL. `?nogl` isolates this:
  it's roughly half the WebGL cost, not a rounding error.
- `js/stage/stage.js` already caps WebGL at `MAX_DPR = 1.5` and has an adaptive
  downgrade (drop the ratio cap after 90 sustained slow frames), but at the baseline's ~8
  fps that threshold takes **~11 seconds** to trip — long past the point a visitor has
  already judged the page as laggy.

## Fixes

### 1. Loader ring: converge per elapsed time, not per animation frame (the gate has since been removed)

`js/gate.js`'s ring advanced `shown += (target - shown) * 0.12` once per
`requestAnimationFrame` callback. That is a fixed fraction *per tick*, so its wall-clock
fill time is proportional to how often rAF actually fires — on a busy main thread (module
imports, shader compile under `stage.warm()`, font layout) a real machine can see rAF at a
fraction of 60 Hz, and the ring visibly crawls even after loading has actually finished.
Changed to a fixed fraction per elapsed *second* (`1 - exp(-14·dt)`, ~0.8 s to converge
regardless of frame rate).

| Config | Loader end before | Loader end after |
|---|---|---|
| WebGL, DPR 2 | 2.8 s | 2.0 s |

Scroll performance is unaffected (this only touches the pre-"Enter" gate), as expected.

### 2. Match the 2D HUD/fallback resolution to the WebGL ratio cap

`overlay.resize()` and `fallback.resize()` were called with a hardcoded DPR cap of 2,
independent of `MAX_DPR` (1.5) or its adaptive downgrade — so the full-canvas 2D redraw
(`js/stage/overlay.js`, every frame it has anything to show) and the no-WebGL fallback
render were consistently sharper, and more expensive per pixel, than the WebGL draw they
sit on top of or replace. Pass the same `ratio` computed for WebGL instead.

| Config | Scroll FPS before | Scroll FPS after | Task ms/frame before | after |
|---|---|---|---|---|
| WebGL, DPR 2 | 8.4 | 10.7 | 117 | 94 |
| `?nogl`, DPR 2 | 17.3 | 22.1 | 58 | 43 |

### 3. React to sustained slow frames in ~1s, not ~11s

The existing adaptive-resolution step (drop the WebGL ratio cap after sustained slow
frames) required 90 consecutive slow frames before acting. At the baseline's ~8 fps that's
**~11 seconds** of visible lag before the page corrects itself — long past the point a
visitor has judged it as laggy. Lowered the threshold to 24 frames (~1s at a healthy frame
rate, ~3s even at the baseline's fps), so the page recovers quickly instead of staying
pegged at the worst-case resolution for the whole first scroll.

| Config | Scroll FPS before (fix 2 only) | Scroll FPS after (+ fix 3) | Task ms/frame before | after |
|---|---|---|---|---|
| WebGL, DPR 2 | 10.7 | 16.2 | 94 | 62 |
| WebGL, DPR 1 | — | 16.1 | — | 63 |

(`?nogl` never had this problem: it doesn't run the WebGL adaptive-resolution branch, so
fix 3 doesn't apply there — its whole gain is fix 2.)

Combined, fixes 2+3 take WebGL/DPR2 scroll from **8.4 fps / 117 ms per frame** (baseline)
to **16.2 fps / 62 ms per frame** — essentially a 2× reduction in main-thread cost per
scroll frame, with no change to the steady-state resolution when the page isn't struggling.

### 4. Disable MSAA on the WebGL renderer

`WebGLRenderer` was created with `antialias: true`. Under SwiftShader (headless) this alone
was worth 16.2 → 25.4 fps; visually, checked with a same-DPR (1.5, the site's `MAX_DPR`)
screenshot comparison of the Warn chapter (the densest line/edge scene — the COOPER model's
paper edges, "my lane" dashes, detection brackets), the difference is not perceptible: the
DPR cap already supersamples above 1×, which covers most of what MSAA buys on this line-art
style at a fraction of the per-frame GPU cost. (MSAA cost on a real GPU is usually cheaper
than on SwiftShader's software rasterizer, but the resolve step is never free, and the scene
never needed it once DPR-supersampled.)

| Config | Scroll FPS before | Scroll FPS after | Task ms/frame before | after |
|---|---|---|---|---|
| WebGL, DPR 2 | 16.2 | 27.1 | 62 | 37 |

Fixes 1–4 combined take the reported problem's two symptoms from baseline to:

| Metric | Baseline | After fixes 1–4 |
|---|---|---|
| Loader end (WebGL, DPR 2) | 2.8 s | ~2.0 s |
| Scroll FPS (WebGL, DPR 2) | 8.4 | 27.1 |
| Task ms/frame (WebGL, DPR 2) | 117 | 37 |

### 5. Give `?nogl` the same adaptive-resolution relief as WebGL

After fix 4, `?nogl` (47 ms/frame) was slower than WebGL (37 ms/frame): the fallback 2D
scene render (`fallback2d.js`) plus the HUD overlay is now the more expensive path, but the
adaptive-resolution step from fix 3 was gated on `animate` (`= !still && webgl`), which is
always `false` without WebGL — so a struggling `?nogl` visitor never got the ratio-cap
downgrade a struggling WebGL visitor does. Changed the gate to `!still`, since the
ratio/resize the step controls applies to the 2D canvases the same way it applies to the
WebGL one, regardless of which path is drawing.

| Config | Scroll FPS before | Scroll FPS after | Task ms/frame before | after |
|---|---|---|---|---|
| `?nogl`, DPR 2 | 20.4 | 32.3 | 47 | 28 |

(WebGL numbers are unchanged by this fix, confirmed by re-measuring: 28.1 fps / 36 ms per
frame, within run-to-run noise of fix 4's 27.1 fps / 37 ms.)

## Final numbers (all fixes applied)

| Config | Loader end | Scroll FPS | Frame p50/p95 | Task ms/frame | Long tasks (scroll) |
|---|---|---|---|---|---|
| WebGL, DPR 2 | 2.0 s | 27–28 | 33 / 67 ms | 36–37 | ~30 |
| WebGL, DPR 1 | ~1.9 s | 28.4 | 33 / 50 ms | 35 | 22 |
| `?nogl`, DPR 2 | 1.9 s | 32.3 | 33 / 50 ms | 28 | 28 |
| `?nogl`, DPR 1 | 1.8 s | 32.4 | 33 / 50 ms | 28 | 20 |

vs. baseline:

| Config | Scroll FPS: baseline → final | Task ms/frame: baseline → final |
|---|---|---|
| WebGL, DPR 2 | 8.4 → 27–28 (**3.2×**) | 117 → 37 (**3.2×**) |
| `?nogl`, DPR 2 | 17.3 → 32.3 (**1.9×**) | 58 → 28 (**2.1×**) |

Loader end dropped from 2.8 s to ~2.0 s in this headless run; the bigger effect of fix 1
(time-based ring convergence) is on real hardware where the main thread is busier than
here and rAF fires less often, which is exactly the failure mode that made the ring lag
behind actual load progress.

WebGL DPR 1 and DPR 2 converge to nearly the same numbers because the adaptive-resolution
step (fixes 3 and 5) drops the effective ratio to 1× partway into any sustained slow
stretch regardless of the starting DPR — this is intended: the steady state under load is
now the same for both, only the time-to-full-quality on a fast machine differs.

Largest remaining per-frame cost in both paths is the 2D canvas HUD/overlay
(`js/stage/overlay.js`) and, without WebGL, the 2D scene fallback (`js/stage/fallback2d.js`):
both do a full canvas reset and redraw every frame that has anything on screen (which is
most of the scroll range — detections, predictions, the lane, exploded-view leaders). That
full redraw is inherent to how the HUD is drawn today (values are genuinely changing most
frames: camera easing, time-driven object motion, scroll-scrubbed chapter progress), so
cutting it further would mean diffing what actually needs to repaint — a real refactor, not
a tuning change, and out of scope here per "performance before new effects." Fixes 2, 3 and
5 already remove the part of that cost that was pure waste (rendering the HUD sharper than
the scene, and staying at a too-high resolution long after frames were provably too slow).

Transfer (441 KB, 24 requests) was not a significant contributor to loader time under Fast
4G and wasn't touched: `vendor/three.module.min.js` (172 KB) is close to its practical
floor for a bundled, minified three.js; the fonts are already split into latin/Greek
subsets by `unicode-range` (`tokens.css`) so the Greek weights only download if a page
actually paints a Greek character (the overlay's `ω` label does, but it's a few KB and
not on the critical path to the loader closing).

## Performance rules

Keep these in mind for future work on `site/`:

1. **Measure before changing anything perf-related**, with `tools/site_perf/` (`serve.mjs`
   + `measure.mjs`, 3 runs, medians) against a snapshot of the unmodified code, not just
   before/after in place — a stale baseline server drifts if you edit `site/` under it.
   Report loader end, transfer, scroll FPS/frame time, and long tasks; when a change could
   plausibly touch either the WebGL or the 2D path, measure both DPR 1 and DPR 2, and both
   with and without `?nogl`, to attribute the effect correctly. Headless Chromium's WebGL
   is software-rendered (SwiftShader) — treat FPS as *relative* (before vs. after), never
   as an absolute number a real GPU would hit.
2. **DPR is the single biggest lever** on both the WebGL and 2D-canvas paths: cost scales
   with pixel count, so doubling DPR roughly quadruples fill-rate-bound work. Any canvas
   (`stage-gl` or `stage-hud`) should be sized off the same effective ratio
   (`js/stage/stage.js`'s `ratio`/`ratioCap`), not a separately hardcoded cap — two canvases
   drawing the same scene at different resolutions is both wasted work and visually
   inconsistent.
3. **MSAA (`antialias: true`) is redundant once DPR supersampling is above 1×** for this
   line-art style; leave it off unless a specific DPR-1 visual regression is found and
   verified with a same-DPR screenshot comparison (not assumed).
4. **The adaptive-resolution downgrade must gate on `!still`, not on `webgl`/`animate`** —
   it protects whichever canvas is actually drawing (WebGL or the `?nogl` fallback), and
   both are fill-rate-bound the same way. If you add a third rendering path, wire it in too.
5. **React to sustained slowness in ~1 s (~24 frames), not tens of seconds.** A visitor has
   already judged the page as laggy long before a multi-second-to-trip threshold fires; a
   short debounce (a couple dozen frames, not a couple hundred) still avoids reacting to a
   single hitch.
6. **Anything that visibly counts up or fills in during load (any future progress
   indicator; the loader ring that prompted this rule is gone) must converge at a fixed rate per elapsed *time*, never per
   animation frame.** A fixed fraction-per-tick makes the animation's wall-clock duration
   inversely proportional to the frame rate — exactly backwards, since it's slowest exactly
   when the page is busiest. Use a `dt`-based exponential decay (see
   `js/stage/stage.js`'s `damp()`) instead.
7. **The 2D HUD/overlay and fallback scene redraw the whole canvas every frame they have
   anything to show**, by design (the scene's state is genuinely continuous — camera
   easing, time-driven motion, scroll scrubbing). Don't try to skip redraws based on "did
   anything change" without a real diffing mechanism; a half-measure will either miss
   real changes (stale visuals) or catch nothing (no perf gain). If overlay cost becomes
   the bottleneck again, the fix is reducing per-frame draw-call/state-change count inside
   `draw()`, not skipping frames.

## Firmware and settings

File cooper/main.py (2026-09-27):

"""COOPER main loop: capture -> detect/track -> predict every object -> judge risk -> LEDs -> stream.

Run with:  python -m cooper.main [--source webcam] [--no-leds]
"""
import argparse
import logging
import time

import cv2

from .camera import Camera, FrameGrabber
from . import settings
from .control import Control
from .detector import Detector
from .diag import RateMeter, SystemMonitor
from .leds import Leds
from .predictor import Tracks
from .risk import RiskJudge
from .settings import LiveSettings, SettingsError, load_config
from .stream import SharedState, serve_in_background

log = logging.getLogger("cooper")


def _smooth(avg, sample, alpha=0.2):
    """Exponential moving average; the first sample starts it."""
    return sample if avg is None else (1 - alpha) * avg + alpha * sample


def _object_json(o):
    return {
        "id": o.id, "label": o.label, "conf": round(o.conf, 2), "box": list(o.box),
        "level": o.level, "kind": o.kind, "reason": o.reason,
        "path": [[round(u, 1), round(v, 1)] for u, v in o.path],
        "velocity": [round(c, 1) for c in o.velocity],
        "ttc_s": None if o.ttc is None else round(o.ttc, 2),
        "time_to_lane_s": o.time_to_lane,
    }


def annotate(frame, detections):
    for d in detections:
        x1, y1, x2, y2 = d.box
        cv2.rectangle(frame, (x1, y1), (x2, y2), (0, 200, 0), 2)
        cv2.putText(frame, f"{d.label} #{d.track_id} {d.conf:.2f}", (x1, y1 - 6),
                    cv2.FONT_HERSHEY_SIMPLEX, 0.5, (0, 200, 0), 1)
    return frame


def main():
    parser = argparse.ArgumentParser(description="COOPER dashcam")
    parser.add_argument("--source", choices=["auto", "picamera", "webcam"])
    parser.add_argument("--port", type=int)
    parser.add_argument("--annotate", action="store_true", help="draw boxes into the /video stream")
    parser.add_argument("--no-leds", action="store_true", help="mock the LEDs even on a Pi")
    parser.add_argument("--config", help="settings file (default: cooper.toml in the repo root, if present)")
    args = parser.parse_args()

    logging.basicConfig(level=logging.INFO, format="%(asctime)s %(name)s %(levelname)s %(message)s")

    try:
        cfg = load_config(args.config, required=args.config is not None)
    except SettingsError as e:
        parser.error(str(e))
    log.info("Settings: %s", args.config or (settings.DEFAULT_PATH if settings.DEFAULT_PATH.exists()
                                            else "built-in defaults (no cooper.toml)"))
    if args.source:
        cfg.camera.source = args.source
    if args.port:
        cfg.stream.port = args.port
    if args.annotate:
        cfg.stream.annotate = True
    if args.no_leds:
        cfg.leds.enabled = False

    camera = Camera(cfg.camera)
    detector = Detector(cfg.detector)
    control = Control()
    leds = Leds(cfg.leds)
    tracks = Tracks(cfg.prediction)
    judge = RiskJudge(cfg.risk)
    state = SharedState()
    monitor = SystemMonitor(leds_mode=lambda: leds.mode)
    live_settings = LiveSettings(cfg, path=args.config or settings.DEFAULT_PATH, control=control)
    serve_in_background(state, control, cfg.stream, diag=monitor.snapshot, settings=live_settings)
    log.info("Dashboard at http://localhost:%d", cfg.stream.port)

    rate = RateMeter()
    infer_ms = latency_ms = None  # smoothed, for diag
    level = "clear"

    grabber = FrameGrabber(camera)  # started last: nothing between here and `try` can fail
    try:
        while True:
            frame, now = grabber.read()  # newest frame and its capture time; stale ones dropped
            if frame is None:
                continue
            h, w = frame.shape[:2]

            t_infer = time.monotonic()
            detections = detector.detect(frame)
            infer_ms = _smooth(infer_ms, (time.monotonic() - t_infer) * 1000.0)

            # Each object's filter is updated at the moment its frame was captured.
            assessment = judge.update(tracks.update(detections, now), w, h, now)
            leds.set(assessment.level)
            if assessment.level != level:
                level = assessment.level
                log.info("Risk: %s%s", level, f" ({assessment.reason})" if assessment.reason else "")
                control.log_event("risk_changed", level=level, reason=assessment.reason)

            fps = rate.update(now)  # from capture times, so it's the processed-frame rate

            if cfg.stream.annotate:
                frame = annotate(frame, detections)

            ok, jpeg = cv2.imencode(".jpg", frame, [cv2.IMWRITE_JPEG_QUALITY, cfg.stream.jpeg_quality])
            if ok:
                # Capture -> detect -> predict -> risk -> LEDs -> encode, for this frame.
                latency_ms = _smooth(latency_ms, (time.monotonic() - now) * 1000.0)
                lane = cfg.risk.lane
                state.publish(jpeg.tobytes(), {
                    "fps": round(fps, 1),
                    "frame": {"w": w, "h": h},
                    "objects": [_object_json(o) for o in assessment.objects],
                    "risk": {"level": assessment.level, "reason": assessment.reason},
                    "leds": {**leds.state, "mode": leds.mode},
                    "lane": [[lane[i], lane[i + 1]] for i in range(0, 8, 2)],
                    "diag": {
                        "fps": round(fps, 1),
                        "capture_fps": round(grabber.capture_fps, 1),
                        "infer_ms": round(infer_ms, 1),
                        "latency_ms": round(latency_ms, 1),
                    },
                })
    except KeyboardInterrupt:
        log.info("Shutting down")
    finally:
        leds.close()
        grabber.close()
        camera.close()


if __name__ == "__main__":
    main()

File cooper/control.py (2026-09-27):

"""Shared state for the vision loop and the HTTP API: the event log described in docs/API.md.

One Control instance is created in cooper/main.py and handed to both the vision loop and
cooper.stream's Flask app, so it's the single thread-safe hub between them.
"""
from __future__ import annotations

import threading
import time
from collections import deque

EVENT_LOG_SIZE = 200


class Control:
    def __init__(self):
        self._lock = threading.Lock()
        self._events = deque(maxlen=EVENT_LOG_SIZE)
        self._next_seq = 1

    def events_since(self, since):
        with self._lock:
            return [e for e in self._events if e["seq"] > since]

    def log_event(self, event_type, **fields):
        with self._lock:
            event = {"seq": self._next_seq, "t": time.time(), "type": event_type, **fields}
            self._next_seq += 1
            self._events.append(event)

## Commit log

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2026-09-26 Drive steppers through Arduino Uno + TMC2209
    Replace direct Pi GPIO stepping with a USB serial link to an Uno running
    AccelStepper (firmware/coop_motors). Adds heartbeat watchdog, auto port
    detection, TMC2209 wiring/flashing docs, and pyserial dependency.
    [config.py]
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2026-09-26 Auto-reconnect the Arduino serial link in coop/motors.py
    A supervisor thread now owns (re)connecting: on disconnect the
    gimbal falls back to mock motion and keeps retrying instead of
    staying stuck in mock mode for the rest of the process. Fires
    motor_connected/motor_disconnected through an on_event callback for
    the control event log, and adds Gimbal.stop() for control mode
    "stop".
2026-09-26 Add pytest suite: pixel math, Kalman, target choice, control, serial, Flask API
    Covers coop/main.py's pixel_to_offset_deg and choose_target, the Kalman
    predictor's convergence and reset behavior, coop/control.py's mode/target/aim
    state machine and event log, coop/motors.py's Arduino handshake/aim/heartbeat/
    reconnect protocol against a fake serial port, and every coop/stream.py route
    via Flask's test client. Runs anywhere requirements.txt does, no hardware
    needed (pip install -r requirements-dev.txt && pytest).
    [test_control.py, test_predictor.py, test_stream.py]
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2026-09-26 Devpost: add Cloudflare Tunnel/Access; lane requests for Access expiry
    Swaps the redundant stepper-motor tag for cloudflare to stay at 25.
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2026-09-26 Add first-hardware bring-up checklist
    Step-by-step checks with expected results for power, camera, Uno
    flashing, serial handshake, motor direction/scale/limits, closed-loop
    tracking, FPS, resilience, systemd and the tunnel. Everything is
    tagged [never run]; also records the reconnect re-zero issue.
2026-09-26 Wire coop/control.py into the main loop
    Fixes the startup crash from the 3-argument serve_in_background. The loop
    now honours auto/manual/stop, lets an operator lock beat auto-selection,
    releases a lock once the target has been gone for lost_timeout_s, logs
    target_acquired/target_lost, and publishes the full docs/API.md status
    (mode, target.locked, boxes, frame FOV, gimbal target/limits).
    When ByteTrack re-IDs a target (the box jumps while the gimbal slews), it
    is re-associated with the detection nearest the Kalman prediction in world
    angles, and the lock carries over. Lock switches held 11/12 times in a
    synthetic test, versus both attempts failing before.
    The virtual gimbal no longer clam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
    [config.py, main.py]
2026-09-26 API: add frame_seq and frame FOV; document the prediction overlay math
    server_time is stamped per request, so it can't show a stalled vision
    loop; frame_seq can. The frame FOV lets the dashboard project the
    predictor's lead aim and velocity into pixels with main.py's pinhole model.
2026-09-26 Dashboard: show the prediction, keyboard control, fullscreen, connection banner
    - Overlay draws the target's velocity arrow, the predicted aim point, and a
    fading aim trail kept in world angles so it doesn't smear as the camera pans
    - Keys: 1/2/3 switch mode, arrows nudge in manual (Shift = 1 deg), H home, F fullscreen
    - Fullscreen with a pseudo-fullscreen fallback for iPhone Safari
    - Banner for offline, stale (frame_seq frozen) and expired Cloudflare Access
    (detected via redirect: "manual"); controls pause while disconnected
    - Smaller boxes drawn on top so overlapping detections stay clickable
    - Mock moves actors in world angles so auto mode really follows and leads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
2026-09-26 Fix serial reconnect turning the camera past its limits
    Opening the port resets the Uno, zeroing its step counter wherever the
    axis stopped; the Pi then replayed its last target in the old frame,
    so a link lost at pan 90 turned the camera a further 90. The mock
    simulation also kept "moving" the gimbal during the outage, so the
    Pi's own position estimate drifted toward the target.
    Firmware: Z now takes optional <pan> <tilt> to set the counter.
    Pi: the first connect still sends bare Z (power-on = 0 deg); every
    reconnect restores the last reported position, and once hardware has
    connected, angles hold that position during an outage instead of
    simulating. tests/test_reconnect.py fails on the ol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
2026-09-26 Add frame_seq to status, fix /video before the first frame, add smoke test
    SharedState.publish stamps frame_seq per docs/API.md so the dashboard
    can detect a stalled vision loop. frames() now starts at seq 0, so a
    /video request made during startup waits for a real frame instead of
    yielding None (500). tests/test_smoke.py runs one real coop.main loop
    iteration with a fake camera and detector and --no-motors, which would
    have caught the serve_in_background signature break.
    [stream.py, test_smoke.py]
2026-09-26 Update hardware checklist and lane requests for the reconnect fix
    HARDWARE_TEST.md: reconnect step now verifies the fix (plus a Z check
    when flashing), coop-live hostname, prerequisites updated. TERMINALS:
    clear the finished frame_seq, /video, smoke-test and hostname requests;
    claim tests/test_smoke.py and tests/test_reconnect.py; new requests for
    lane 4 (stale frame_seq assertion, site README hostname) and lane 1
    (virtual-gimbal crop gating).
2026-09-26 Record COOP name, fix stale frame_seq test, sync lane requests
    - COOP = Computer-vision Object Observation & Prediction (README, CLAUDE.md, Devpost)
    - test_stream: expect frame_seq in published status
    - TERMINALS.md: clear finished requests
    [test_stream.py]
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2026-09-26 Make the control path pan-only
    MotorConfig drops the tilt fields and gains pan_invert. Gimbal exposes
    pan/steps_per_deg and aim(pan); the wire format is unchanged (tilt is
    always sent as 0), so the firmware needs no re-flash. Control keeps a
    single manual_pan. /api/aim and /api/nudge accept a body without tilt,
    and /api/status keeps tilt: 0 / tilt_enabled: false for the dashboard.
    Non-finite angles are now rejected at the API, in Control and in
    Gimbal.aim: Python's JSON parser accepts NaN, and round(nan) would have
    crashed the vision loop.
    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
    [config.py, control.py, main.py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]
2026-09-26 Add a fake Uno that emulates the firmware over TCP
    tools/fake_uno.py runs the .ino's logic in real time: the READY
    handshake after a DTR reset, 50 ms P reports, T/C/Z/S/E/H with the
    sketch's exact parsing (47-char buffer, sscanf quirks), the 2 s
    watchdog and an AccelStepper-style trapezoid. Each axis tracks the
    reported counter and the physical rotor separately, so tests can see
    steps lost while the drivers are disabled.
    Gimbal opens ports containing :// through serial.serial_for_url, so
    MotorConfig.port = socket://localhost:5555 attaches it. New end-to-end
    tests drive the real Gimbal against it, including unplug/replug.
    Claude-Sessio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
2026-09-26 Load settings from coop.toml
    coop/settings.py overlays coop.toml (gitignored; coop.example.toml
    documents every key at its default) on the config.py defaults, then CLI
    flags win. Unknown sections/keys and wrong types are startup errors with
    a suggestion, and validate_config range-checks everything. save_settings
    edits the file line by line so comments survive, and re-parses the
    result before atomically replacing the file.
    main.py gains --config and --motor-port; MotorConfig gains
    idle_disable_s. Tests never read a developer's real coop.toml.
    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
    [config.py, main.py, settings.py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]
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2026-09-26 Gimbal: e-stop, arm, zero, idle power-down, frame epoch
    estop() sends S at once and E 0 only once the reported position has
    been still for 0.25 s (or at the worst-case braking deadline): cutting
    power mid-ramp lets AccelStepper count ~400 steps the shaft never makes.
    aim() is refused until arm(). In stop mode the drivers power down after
    idle_disable_s, and aim() re-sends E 1 before any T. The reconnect
    handshake re-sends E 0 because the Uno boots with its drivers on.
    zero() and set_pan_invert() bump frame_epoch; aim(epoch=...) drops
    commands computed in an old frame. link_state reports
    connected/reconnecting/mock; set_motion_limits re-sends C.
    Also fixes a one-step overshoot in the emulat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
2026-09-26 Add /api/estop, /api/arm and /api/zero
    Control.estop() commands the gimbal first, then forces stop mode and
    clears the lock; while engaged, auto/manual/lock/home fail with the
    documented 400. arm() releases but stays in stop. zero() makes here 0
    and, outside an e-stop, switches to manual at 0. estop/arm/zero are
    serialized so an e-stop can't land inside an in-flight arm and be undone.
    Entering manual now holds the current pan instead of jumping back to an
    old setpoint.
    main.py binds the gimbal to Control, passes frame_epoch to aim() and
    resets the predictor when it changes; status gains estop and
    gimbal.drivers_enabled.
    Claude-Session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
    [control.py, main.py, stream.py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]
2026-09-26 Capture on its own thread; measure inference and latency
    FrameGrabber reads the camera continuously and read() returns only the
    newest frame, counting the stale ones it dropped. Camera errors (and a
    test double's KeyboardInterrupt) are re-raised in the vision loop after
    any pending frame, so a dead camera still ends the run as before.
    The loop now timestamps each frame at capture and feeds that time to
    the Kalman filter, and publishes diag.fps, capture_fps, infer_ms and
    latency_ms (capture to encoded frame, after the motor command).
    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
    [camera.py, main.py, test_capture.py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]
2026-09-26 Showcase: review passes 1-2 (framing, legibility, mobile, fallback)
    - target paces instead of wrapping, so every chapter has it in view and the
    prediction visibly flips when it turns around
    - off-centre camera (right on desktop, up on phones) and a shader fade for
    anything passing behind the copy column
    - labels flip left at the screen edge; phones show IDs only for non-targets
    - 03 swaps copy for the equation figure mid-chapter; gauge and exploded view
    re-framed; the gallery ring dwells card by card
    - minimum horizontal FOV on portrait screens
    - overlay canvas resets its bitmap per frame (clearRect left stale leader
    lines on a GPU canvas in testing)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
2026-09-26 Add live tuning: GET/POST /api/settings
    LiveSettings validates a whole request before applying any of it
    (unknown keys, wrong JSON types, NaN and out-of-range values are 400s),
    saves to coop.toml first when asked so a failed save changes nothing,
    then applies: tracking/detector values on the next frame, speed and
    acceleration re-sent to the Uno as one C command, pan_invert only in
    stop mode. Changes are logged as settings_changed events.
    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
    [main.py, settings.py, stream.py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]
2026-09-26 Showcase: docs, credits, .glb switch, gallery media; Devpost sync
    - site/README.md: editing copy, adding media, swapping in the camera .glb,
    deploying to Cloudflare Pages (coop-224), hostname decision
    - site/CREDITS.md with licenses for three.js, anime.js and the fonts
    - vendored GLTFLoader (imports three via the import map); a loaded model
    is restyled to the scene's ink-and-edges look
    - no-WebGL gallery grid picks up the same data-src media
    - 04 Move reframed; gauge labels no longer collide with the readouts
    - DEVPOST: three.js and anime.js replace libcamera and computer-vision in
    Built with (still 25), showcase paragraph and a challenge entry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
2026-09-26 Add bench tools: jog, camera_check, bench_fps
    tools/jog.py jogs the pan motor over serial with no vision, through the
    real Gimbal and coop.toml (so invert, gearing and limits apply):
    interactive keys on Windows and POSIX terminals, or --goto/--by/--zero
    for one-shot moves. tools/camera_check.py reports delivered resolution
    and FPS and saves a still for the colour/orientation check.
    tools/bench_fps.py times model.track exactly as COOP calls it, PyTorch
    vs NCNN at 256/320/416, and exports per-size NCNN models.
    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
    [bench_fps.py, camera_check.py, test_tools.py]
2026-09-26 Docs: hardware checklist in tool order; README tools, settings, safety
    HARDWARE_TEST.md now runs emulator -> jog -> camera check -> FPS bench
    -> full run, uses coop.toml instead of editing config.py, covers the
    e-stop, zero, idle power-down and diag readouts, and drops the tilt
    step. It warns that each separate jog run resets the Uno's zero.
    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
2026-09-26 Review fixes: non-object JSON bodies, capture-thread leak, stale P after zero
    - POST routes treated any truthy JSON as an object, so a list or string
    body raised in .get() and returned 500; they now get the normal 400.
    - The capture thread started before the YOLO model loaded, outside the
    try/finally; a model-load failure leaked it. It now starts last.
    - A P report the Uno sent just before processing Z could land after
    zero() and put the old position back (and into the reconnect restore
    point). Reports are ignored for 150 ms after a zero.
    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
    [main.py, stream.py, test_stream.py]
2026-09-26 Settings: report unreadable/unwritable files as SettingsError
    A read-only directory, a missing folder or a non-UTF-8 coop.toml raised
    OSError/UnicodeDecodeError, which POST /api/settings turned into a 500
    and startup into a traceback. They're now SettingsErrors (a 400, or the
    usual one-line startup error).
    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
    [settings.py, test_settings.py]
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2026-09-26 camera_check: a camera that won't open gets a hint, not a traceback
    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
    [camera_check.py, test_tools.py]
2026-09-26 Describe the --invert rehearsal as it actually behaves
    Running it showed the camera turns away until it loses the walker
    (about 60 deg out), not all the way to a limit.
    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
    [rehearsal.py]
2026-09-26 API: describe the e-stop power-down as implemented
    It waits for 0.25 s of stillness (deadline: braking time + 0.3 s), not
    a fixed braking time + 0.2 s as first specified.
    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
2026-09-26 Remove the motor, gimbal and firmware code
    COOPER is now a fixed dashcam: nothing moves. Deleted the Arduino firmware,
    cooper/motors.py (serial link, e-stop, zero), cooper/sim.py (virtual gimbal),
    tools/jog.py, tools/fake_uno.py, tools/firmware_sim/ and their tests.
    What's left is capture -> detect/track -> stream:
    - config: the motors, tracking and sim sections are gone; an old cooper.toml
    that still has them fails at startup naming the section
    - control.py keeps only the event log; the mode/lock/aim/e-stop routes are gone
    - live settings: conf only (the motor and aim keys went with the motors)
    - diag: no serial link state
    - main: --no-motors and --motor-port removed; no world angles or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
    [camera_check.py, config.py, control.py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]
2026-09-26 Rebuild the rehearsal as a synthetic road seen by a fixed dashcam
    tools/rehearsal.py no longer needs the fake Uno. A 20 s scripted loop (a
    car in the next lane, a far lead car, a car cutting in, a pedestrian
    crossing, the lead car braking) is drawn with the pinhole ground-plane
    model, so box height scales as 1/Z like on the real camera. The detector
    reads each actor back out of the rendered pixels by colour and gives it
    ByteTrack-style IDs, so the real app runs end to end with no hardware.
    [rehearsal.py, test_rehearsal.py]
2026-09-26 Predict every object in image space and judge lane risk
    Replaces the world-angle predictor. cooper/predictor.py runs a
    constant-velocity Kalman filter per ByteTrack ID on the box's bottom-centre
    (u, v) and height h. F, H, Q, R and P0 are block-diagonal per axis, so the
    6-state filter factors exactly into three 2-state filters (checked against
    the full 6x6 form). v and h share the box's bottom edge, so they're gated
    together: a box cut short by an occluder coasts instead of dragging the
    ground point onto the occluder's roof. TTC = h / h' only counts when h'
    exceeds 2 standard deviations of itself, so jitter on a steady box isn't
    read as closing.
    cooper/risk.py: danger when an object's bottom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
    [config.py, predictor.py, risk.py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]
2026-09-26 Drive the yellow and red warning LEDs with gpiozero, mocked off a Pi
    Mock unless [leds] is enabled, /proc/device-tree/model says Raspberry Pi,
    and both pins can be claimed (a pin claimed before a failure is released).
    gpiozero is imported only on a Pi and comes from apt (with lgpio for the
    Pi 5), so laptops and CI never need it. GPIO is written only on a change.
    Pins are placeholders (BCM 17 yellow, 27 red), marked TODO.
    [leds.py, test_leds.py]
2026-09-26 Main loop: predict, judge risk, drive the LEDs; fix the fps readout
    capture -> detect/track -> predict every object -> judge risk -> LEDs ->
    stream. The status carries objects (with predicted paths, level, TTC),
    risk, LED state and the lane; risk changes are logged as risk_changed
    events. --no-leds forces mock LEDs, and the LEDs turn off on shutdown.
    fps was an average of 1/dt, which overshoots when frames arrive unevenly
    (the webcam read 64 fps against a 31 fps capture). RateMeter inverts the
    average interval instead. Drops the stage-2 tests that only asserted
    removed things stay removed.
    [diag.py, main.py, test_diag.py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]
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2026-09-26 Rewrite the showcase copy for COOPER, the fixed dashcam
    Rename to COOPER and drop every aiming, gimbal, motor and Arduino line.
    Chapter 04 becomes Warn (yellow and red LEDs), Predict explains the
    per-object constant-velocity Kalman filter, the 1.5 s path against the
    lane, and time to contact (tau = h / h-dot). Build lists the real parts
    on the placeholder rig, and the READMEs say the 3D model is a placeholder.
    The name lore is a marked placeholder in js/intro.js.
    The intro word's font size is scaled by 4/6 so six letters fit where
    four did; the HUD, overlay tag and chapter-name strings change, not
    their code.
2026-09-26 Dashboard for the dashcam: risk, LEDs, predicted paths, editable lane
    Removes the pan dial, modes, manual aim, target lock and e-stop. The feed
    gets one canvas overlay, redrawn only on a new frame, a resize, a lane
    drag or a decoding label: the lane (tinted by the level), every object's
    brackets and predicted path, and the bottom edge the lane test uses. The
    rail shows the risk level and reason, the two LEDs (gpio or mock), the
    lane editor (drag the corners; apply, save, reset), the objects by level,
    the event log and the new live settings. Two tokens mirror the physical
    LEDs (yellow, crimson red, kept apart from the brand orange); risk
    indicators switch instantly, like the LEDs. mock.js pla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
2026-09-26 README and Devpost for the COOPER dashcam
    Pitch (167 chars), what it does, the math with the shipped numbers, the
    hardware and placeholder LED pins, and how to run it. Devpost "Built with"
    drops arduino, c++, accelstepper, tmc2209, nema-17 and pyserial and adds
    gpiozero, ncnn and github-actions (22 tags); the challenges are the
    dashcam's (jitter vs TTC, occlusion gating, the TTC corridor, the fps
    readout). The name's story and the other ✏️ sections stay unfilled.
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2026-09-27 Keep only the two site fixes from the WIP snapshot
    05d1c11 (mislabelled "stage 4/5") holds the two leftover fixes from the
    site review: COOP -> COOPER in site/CREDITS.md, and the bottom HUD's
    "Bearing +000.0°" (the old pan angle) relabelled "Frame 000000", a
    counter of rendered frames like the dashboard's frame_seq, with the same
    markup, classes and layout. It also renamed COOP in five code comments,
    which went beyond that; this restores those files as merged from
    copy/cooper-site.
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2026-09-27 Site: the real model in Build/Warn/Team, a static LED indicator, no rotation
    - solids.js loads models/cooper-camera.glb lazily (when the scroll nears
    Warn), with a box stand-in until then. Build pulls the real parts
    apart as you scroll: lid, then both LEDs, the Pi out of the tray, the
    mount and the camera module forward. Labels hang on the real parts.
    - Everything that implied rotation is gone: the turning base, the
    bearing tape, the chapter 04 gauge, the panning eye view and the aim
    ray. The frustum is fixed.
    - Chapter 04 shows COOPER's two LEDs, lit by the scene's warning level
    (red: something in my lane now; yellow: a path enters it within
    1.5 s; red overrides; 0.5 s hold).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
2026-09-27 Record baseline site performance measurements
    Measured against origin/dev's site/ (served on its own port so this
    branch's fixes don't move the baseline): loader end, transfer, largest
    files, and scroll FPS/frame time at DPR 2/1 and with ?nogl to separate
    WebGL cost from 2D overlay cost.
    Claude-Session: https://claude.ai/code/session_01EwGKCcjdNm9oqqZvUbMSZ1
2026-09-27 Make the loader ring converge per elapsed time, not per frame
    shown += (target - shown) * 0.12 once per rAF tick makes the ring's
    wall-clock fill time scale with however slow the main thread makes
    requestAnimationFrame fire, so a busy load (module imports, shader
    compile) visibly stretches the loader well past when loading actually
    finished. Use a fixed convergence rate per elapsed second instead.
    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
2026-09-27 Match 2D overlay/fallback resolution to the WebGL ratio cap, react faster
    overlay.js and fallback2d.js were hardcoded to DPR 2 regardless of the
    WebGL MAX_DPR (1.5) or its adaptive downgrade, so the full-canvas 2D
    redraw every frame was sharper and more expensive than the WebGL draw
    it sits on top of or replaces. Pass the same ratio for both.
    Also lower the adaptive-downgrade threshold from 90 to 24 sustained
    slow frames: at the measured baseline's ~8fps, 90 frames took ~11s to
    react, long past the point a visitor has judged the page as laggy.
    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
2026-09-27 Record final performance numbers and the site perf rules
    Full before/after matrix (WebGL/nogl x DPR1/DPR2) and the reasoning
    for what's left (the 2D HUD/overlay redraw is now the largest
    remaining per-frame cost in both paths, but cutting it further is a
    diffing refactor, not a tuning change). Save the rules future work
    should follow so this doesn't regress.
    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
2026-09-27 Stage: softer particle discs with depth fog and per-point jitter
    From PR #8 (feat/website-originkit), site/js/stage/points.js only.
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2026-09-27 Delete the loader/Enter gate; boot straight into the hero
    Removes the #gate markup, every .gate*/is-gated/chevrons rule and
    js/gate.js. boot() now sets is-entered on <html>, starts the stage and
    plays the hero intro with no loader in front. README and PERFORMANCE rule 6
    no longer point at gate.js.
2026-09-27 Wordmark: keep the title legible under reduced motion and on phones
    Under the lens the word turns into a thin dotted outline. Reduced motion
    set the lens to cover everything, so ?still showed an almost invisible
    title; it now has no lens (solid fill). On narrow screens the fixed 290px
    lens covered the whole word; it now shrinks with the word below the
    1200px reference width (desktop unchanged).
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2026-09-27 Stl file for assembled case
    stl file since step file is too large
    [Assembled Pi Case.stl]
